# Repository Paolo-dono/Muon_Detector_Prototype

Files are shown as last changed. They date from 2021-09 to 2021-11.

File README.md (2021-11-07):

# Muon Detector Prototype
PCB design for the microcontroller subsystem of a muon detector.
- Creator: Paolo de Bruyn
- License: GNU General Public License v3.0

NOTE: Although the name of the project folder is STM32WL55JC_pcb_design, the STM32WL55JC is not the microcontroller that is used in the design. It was used during the initial design, but it has been replaced by the STM32F051R8. The reason why it was not renamed was because all the external component libraries that were added use the absolute filepath, and it would be a mission to change all of them.

## Component availability
All of the components are available from JLCPCB except for a few exceptions.

The GPS module needs an external antenna in order to function properly. Any antenna that has an IPEX MHF connector can be used. One recommendation is the KYOCERA AVX GPS Antenna 1004138 which is available from RS Components.

The banana connectors are sadly not available from JLCPCB but can be procured from DigiKey. It is recommended that the CT3151SP-0 connector is ordered for the ground connector as it is black, and the CT3151-6 is a blue connector which can be used for the supply voltage.

## Using the project
Simply clone the project and open it in KiCAD. The PCB should be in a state where it can already be printed by JLCPCB, but if not, probably only minor changes will have to be made.

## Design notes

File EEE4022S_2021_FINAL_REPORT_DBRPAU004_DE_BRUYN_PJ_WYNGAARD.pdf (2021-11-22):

# Muon Detector Prototype

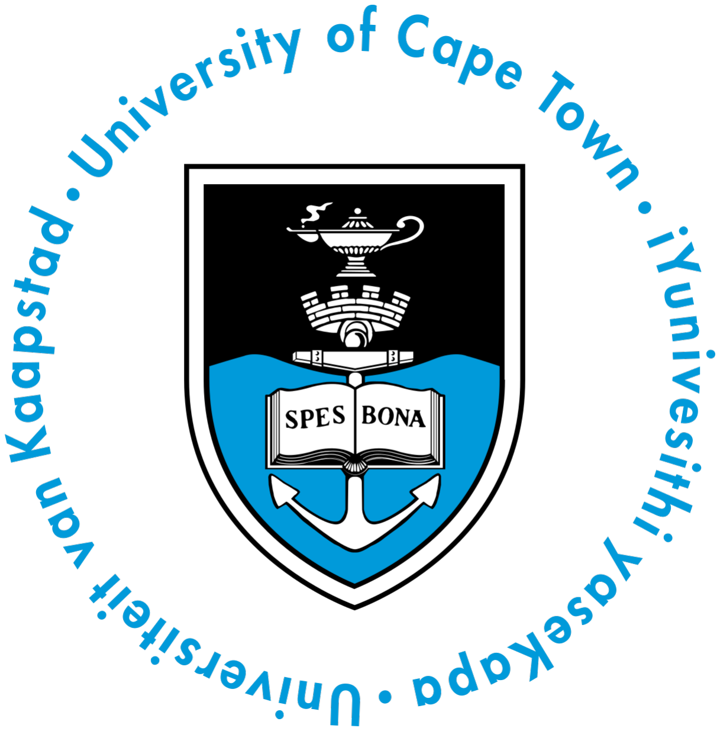
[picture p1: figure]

Presented by:
Paulus Jacobus de Bruyn

Prepared for:
Dr. Jane Wyngaard
Department of Electrical and Electronics Engineering University of Cape Town

Submitted to the Department of Electrical Engineering at the University of Cape Town in partial fulfilment of the academic requirements for a Bachelor of Science degree in Electrical and Computer Engineering

### 7 November 2021

## Declaration

1. I know that plagiarism is wrong. Plagiarism is to use another’s work and pretend that it is one’s own.
2. I have used the IEEE convention for citation and referencing. Each contribution to, and quotation in, this report from the work(s) of other people has been attributed,

and has been cited and referenced.

3. This report is my own work.
4. I have not allowed, and will not allow, anyone to copy my work with the intention of passing it off as their own work or part thereof.
Signature: |
P.J. de Bruyn
Date: | 7 November 2021

## Abstract

Muon radiography has been used since the 1950s to create scans of large and complex objects such as mountains, volcanoes, and pyramids. In this project, a system that can detect muons will be created in order to muon-image Devil’s Peak. A previous final year engineering student built a muon detector subsystem. The purpose of this project is to create the microcontroller subsystem to which the muon detector subsystem can connect that can send out data about the muon detection to a distant computer using LoRa. The data that will be sent is the following: longitude and latitude coordinates; accelerometer data; temperature and humidity; and voltage levels over time measured by the peak detector.

i

# Contents

1 Introduction | 1
2 Literature Review | 4

ii

3 Methodology | 15

iii

4 Design | 24
5 Implementation | 37

iv

6 Results | 65

v

7 Conclusion | 67
8 Recommendations | 68
A Additional files and schematics | 72
B Addenda | 77

vi

# List of Figures

3.1 Flow chart of the methodology | | 16
3.2 Layout of scintillator planes [24] | | 17
3.3 Layout of the muon detector subsystem [24] | | 18

4.1 Diagram of the daughter board and its interface with the microcontroller
subsystem | | 25
4.2 Pulse shaping circuit output [24] | | 27
4.3 Microcontroller subsystem design | | 29
4.4 Attempted STM32WL55JC routing | | 32
4.5 FSM of the control program | | 35
5.1 Power supply of the PCB | | 38
5.2 Peripherals on the PCB | | 39
5.3 IO expanders on the PCB | | 40
5.4 Schematic of the LoRa module | | 42
5.5 Connections of the microcontroller | | 44
5.6 NRST and BOOT connections | | 45

vii

5.7 ST-Link header | | 46
5.8 Oscillators for the microcontroller | | 46
5.9 JST GH header footprint | | 48
5.10 3D view of the JST GH header | | 48
5.11 19-pin 2.54 mm pitch male header appearance on the PCB | | 49
5.12 8-pin 2.54 mm pitch male header appearance on the PCB | | 50
5.13 Microcontroller routing on the PCB | | 51
5.14 LoRa routing on the PCB | | 52
5.15 Power supply routing on the PCB | | 53
5.16 Accelerometer and temperature sensor routing on the PCB | | 54
5.17 IO expanders routing on the PCB | | 55
5.18 3.3V supply across the PCB | | 56
5.19 Acid trap formed by copper tracks | | 57
5.20 An initial design with poor track spacing | | 58
5.21 Timing diagram of the daughter board | | 59
5.22 Final timing diagram | | 64
A.1 Front side of the PCB | | 73
A.2 Back side of the PCB | | 74
A.3 Front side of the PCB without copper fill | | 75
A.4 3D view of the PCB | | 76

viii

# List of Tables

3.1 Functional requirements of the system | | 21
3.2 Non-functional requirements of the system | | 22
5.1 Address selection of the IO expanders | | 40
5.2 10-pin JST GH header pin description | | 48
5.3 9-pin JST GH header pin description | | 49
5.4 3-pin JST GH header pin description | | 49
5.5 19-pin 2.54 mm pitch male header pin description | | 50
5.6 8-pin 2.54 mm pitch male header pin description | | 51

ix

# Nomenclature

BGA Ball Grid Array

EMC Electromagnetic Capability

FSM Finite State Machine

PCB Printed Ciruit Board

RTC Real Time Clock

SiPM Silicon Photomultiplier

SPI Serial Peripheral Interface

SWD Serial Wire Debug

x

# Chapter 1

# Introduction

## 1.1 Background to the study

Muons are elementary particles that are part of the lepton group and were discovered by American physicists Carl David Anderson and Seth Neddermeyer in 1936 [1]. It was later

found that muons provide a good way to image the internal structure of large objects such as mountains. This is because of a property muons have where they change direction and lose a certain amount of energy after they penetrated an object. This information can be used to find the size and type of material the muon travelled through. Muons are a good method for imaging because they occur naturally in the environment and do not have to be produced by an external source like other imaging techniques such as using x-rays or gamma rays. Muon radiography is also a much safer way of imaging that does not have the potential to expose humans to stray radiation as with other methods [2]. Additionally, the foremost reason muons are efficient for imaging is because of their deep penetrative power. Muons can travel through thick layers of rock, concrete, and iron which usually block other particles that are used for detection such as x-rays, gamma rays, neutrons, alpha particles, and beta particles [3].

## 1.2 Objectives of the study

### 1.2.1 Problems to be investigated

The main problem that will be investigated is how to design a PCB with a microcontroller that can communicate with the muon detector subsystem, GPS module, accelerometer, and temperature and humidity sensor, and transmit information from those devices via LoRa to a remote computer. This information will then be used for muon imaging.

### 1.2.2 Purpose of the study

This study will produce a way to detect muons and measure their direction of motion. This will allow one to muon image large objects such as Devil’s Peak, which is the case in this study. This way, geological research can be done on Devil’s Peak such as finding hidden tunnels and caves.

## 1.3 Scope and limitations

This study will only include the following: the design of the PCB of the microcontroller subsystem; the coding of the microcontroller to interface with the muon detector, GPS module, accelerometer, and temperature and humidity sensor; and then finally the sending of the data from those sensors via LoRa. The study will not include the design of the muon detector subsystem, or the actual muon-imaging of Devil’s Peak.

The biggest limitation to this study is time as it has to be completed within a period of three months. There is also a limited budget of R1500 for the project.

## 1.4 Plan of development

The study starts off with a literature review which will be an overview of the research and development that has been done in the field of muon detection, edge computing, IoT, and communication technologies. It will then continue to the methodology section which will explain what approach was used to satisfy the requirements of the project as well as exploring previous work done on the project. Thereafter, the schematic and PCB design of the microcontroller subsystem will be documented together with the design choices that were made to come to that design. Then, the results of the study will be reported. And finally, conclusions will be drawn and recommendations will be made for further study in this field.

# Chapter 2

# Literature Review

## 2.1 Muons

### 2.1.1 Introduction to muons

A muon is an elementary particle which, similar to an electron, has a negative charge and is part of the lepton group, but is approximately 207 times heavier than an electron. It was discovered by the American physicists Carl David Anderson and Seth Neddermeyer in 1936. A muon is fairly unstable, and has a lifetime of just 2.2 microseconds. Although their lifetime is short, muons travel at speeds close to the speed of light and can penetrate thousands of metres into the Earth [1].

Muons detected on Earth come into being due to primary cosmic rays. These are produced from a variety of sources in outer space such as solar flares, or novas. The primary cosmic rays travel through space and some collide with Earth’s atmosphere. Then, they generate a shower of secondary cosmic rays of which muons are one type [4].

### 2.1.2 Muon radiography

A valuable property that muons have is that they scatter after penetrating objects. The degree at which their angles change depend on the object. For dense objects with a high number of protons, such as uranium and plutonium, the change in angle is more prominent. Data can be collected on the degree of scattering of muons throughout the body of the object to create scans of the interior of the object. This field is known as muon radiography and has been implemented since the 1950s [5].

Due to their high momentum, muons can penetrate deeper into thick and dense objects than x-rays, and so they are the better choice when scanning thick samples [5]. Muon

radiography is also a safer option than x-rays which can produce stray radiation, unlike muons that are present naturally [2]. About 10 000 muons reach every square metre of

Earth per minute which is approximately one muon passing through an area the size of a human hand every second [5]. Thus, there is an ample supply of muons to create accurate

scans.

### 2.1.3 Operation of a muon detector

The main parts of a muon detector are a scintillator and a SiPM. A scintillator is a material that luminesces (produces photons) when it is hit by ionizing radiation (which includes muons). This is a property of the material scintillators are made of. Scintillators

can be made from a variety of different materials that can be solid, liquid, or gas and can be organic or inorganic. But in general, high density materials are usually chosen. In the case of inorganic crystal scintillators, the way they operate is when they are hit by ionizing radiation, it excites the electrons within the crystal which then move from the valence to the conduction band leaving holes behind in their place. These electron-hole pairs move around the structure until they reach and are trapped by a defect such as a dopant which are known as activators when it comes to scintillation. At these activator sites, the electrons decay and emit photons which causes luminescence [6].

Although the property of scintillators to luminesce is interesting from a physics perspective, to turn it into something useful an electrical signal is required so that processing and analysis of the luminescence can be made. This is where SiPMs come in. SiPMs are devices that convert light into electrical pulses. They are highly sensitive such that even a single photon can trigger them. The most vital component in a SiPM is the APD (Avalanche Photomultiplier Diode). This component streams an avalanche of electrons

when it is triggered by a photon. This avalanche of electrons only lasts for a very short time in the order of 1 nanosecond. This electrical pulse is then what can be passed to an electronics device for processing. One disadvantage of SiPMs is that they need a high voltage power supply. In some cases, an older variant of the SiPM is used which is the PMT (Photomultiplier Tube). However, SiPMs are becoming the more popular choice

because of their lower operating voltage, lack of susceptibility to magnetic fields, compact

size, and sturdiness [7].

### 2.1.4 Use cases

Decision Sciences

Decision Sciences is a company that has been given the exclusive licence of the Intellectual Property (IP) by U.S. Department of Energy’s Los Alamos National Laboratory (LANL)

to create a system they call Discovery. Discovery is a system that uses muon radiography as a non-intrusive and safe way to generate scans of cargo trucks. They have found that dense shielding such as metal plates around nuclear materials and contraband can pass many types of scanning techniques, like x-rays and gamma rays, completely undetected. However, this does not happen with muons as the dense shielding makes them scatter more which actually makes the materials easier to find. Many smugglers know that water can defeat x-ray systems and would place contraband in pallets of water. However, water still cannot pass by muon radiography undetected [3]. The system can learn the

configuration of different types of vehicles to ignore the known features such as the engine and transmission and focus on any unusual materials that might be hidden [2].

Pyramids

A major use for muon radiography is to scan the internal structure of pyramids. This is often used for the purpose of finding hidden rooms inside the pyramids. Luis Alvarez used muon radiography to search for hidden chambers in the Pyramid of Chephren in Giza. Alvarez and his team started recording data in early 1968 on magnetic tape and through the course of their research they were unable to find any hidden chambers in the 19% of the pyramid that they scanned. Although they were unable to find anything, their research did demonstrate the potential that muon radiography holds [8].

In December 2015, a physicist called Kunihiro Morishima and his team placed muon detectors in the Queen’s chamber of the Great Pyramid of Giza. After a few months, the researchers came upon something promising. To validate their findings, two other teams of physicists placed muon detectors of different types at different locations inside and outside the pyramid. All three teams agreed that their results showed a cavity above the Grand Gallery. The space was found to have a similar cross section as the Grand Gallery and at least 30 metres long. This was the largest discovery of a new space inside the pyramid since the 19th century [9].

Volcanoes

Muon radiography has also been used to scan magma chambers in order to estimate when the volcanoes will erupt. Hiroyuki K. M. Tanaka from the University of Tokyo and his colleagues investigated the density distribution of magma in Mount Iwodake. A 1m² detector was placed at the foot of the volcano to obtain an image of the conduit on

the inside. This information can be used to predict the development of eruptions and determine which areas close to the volcano are in danger [5].

Cosmic Pi

Cosmic Pi is a low-cost cosmic ray detector kit. The kit contains scintillators and SiPM modules as well as a PCB with an amplifier for the detection of muons. The PCB also contains a GPS module, temperature and humidity sensor, and accelerometer. The kit also contains a Raspberry Pi Zero WH which helps with wireless communication and some processing. The idea is for many of these kits to be assembled and used by people all over the world so that the data gathered by these devices can be collected in order to create a global telescope [10].

## 2.2 The Internet of Things (IoT)

### 2.2.1 Introduction

IoT is the growing trend whereby more and more devices are being connected to the internet. Through the development of IoT, devices that initially had very limited functionality have become more useful and responsive not only through their ability to connect to the internet, but more specifically because of their ability to collaborate with other devices. This makes the environment smarter as more internet-capable devices are integrated with it. These devices collect a vast amount of data about the environment which then leads to a challenge with IoT which is how to store and process such large quantities of data that are related to each other. The challenge is made harder by the fact that the data can be produced by many different types of devices running on different platforms that are connected from a variety of remote locations. This is where cloud computing arises to offer a solution [11].

Cloud computing allows a way for IoT devices to connect to each other through central servers that are very powerful and reliable. Cloud computing also offers analytics tools and various ways to visualize data. In addition, it also allows one to access applications from anywhere that has an internet connection [11]. There are some issues with the use

of cloud computing when it comes to IoT which are explained further in Section 2.3.

Through the large collection of data about an environment (such as a home environment or work environment like construction), it helps one produce a common operating picture (COP) [11] of the environment. In addition, through this collection of data, a new realm

of possibilities are opened in the field of data analytics, and it allows one to understand, optimize, and control the environment better.

Another important factor of IoT is that it should be able to operate without the interference of humans or, put differently, it should ”disappear from the consciousness of the user”[11]. To achieve this, IoT devices need to: be able to communicate relevant con-

textual information; have a shared comprehension of the environment and context; and have strong analytics tools. This will allow IoT devices to act autonomously [11].

In order to fully utilize the available Internet technology, large-scale wireless sensor networks that are platform independent must be deployed and include the collection, management, storage, and analysis of data [11].

### 2.2.2 History of IoT

The term ‘Internet of Things’ was first introduced by Kevin Ashton in a presentation he made at a Proctor and Gamble (P&G) conference in 1999. The presentation specifically addressed the use of RFID in supply chain management [12]. But since then, the term has

expanded to include a whole variety of applications and smart devices that can operate autonomously.

### 2.2.3 The use of IoT

Radio Frequency Identification (RFID)

RFID is the use of small electronic chips for wireless data communication. They assist with the identification of the object they are attached to. One major benefit is that they are passive elements and not battery powered, which saves a lot of energy. They use the power of the RFID reader’s probing signal to communicate their ID. The major usage of RFID tags is currently with bank cards to allow for quick transactions. Another major usage is in the monitoring of cargo by attaching RFID tags to port containers [11].

Lighting

The control of lighting is one of the classic examples of the use of IoT because it can take place fully without the need for human intervention. Light sensors that are positioned outside a building can communicate the light intensity to the lights that are inside the building which would then adjust their brightness accordingly. This can save much energy and ensures that lights are not too bright or left on unnecessarily. This is often done using Bluetooth mesh nodes that are attached to all the sensors and lights.

Automotive

Predictive maintenance technology can be used in one’s car to have a better understanding about the internal state of the car. Data that is collected by many sensors in your car can be sent for analysis on the cloud to notify the driver of any potential problems that might present themselves in the future. This allows the user to take action to avoid potential incidents [13].

## 2.3 Edge computing

### 2.3.1 Introduction to edge computing

Edge computing is a distributed computing paradigm that brings computing closer to the edge where it is needed. The edge can be defined as any computing resources that are at a distance from cloud data centers and closer to data sources. In the last couple of years, the amount of data produced at the edge has grown significantly with the great expansion of IoT and the increase of data producers. As an example, a Boeing 727 can produce 5 GB of data every second, and an autonomous car can produce 1 GB of data every second. This has put much pressure on networks and cloud data centers and they cannot keep up with the big volume of data being produced. This is why edge computing is needed because it lightens the load on cloud data centers and decreases network traffic [14].

### 2.3.2 History of edge computing

The idea behind edge computing started in the late 1990s when Akamai launched content delivery networks (CDNs) to increase the speed of web services. CDNs use nodes closer

to the user devices to prefetch and cache content so that it can be delivered to users faster. CDNs are especially useful when it comes to video streaming because there is no more reliance on one central server to do all the work. The potential for edge computing truly became evident in 1997 when Brian Noble and his coworkers implemented speech recognition on mobile devices by having the resource intensive work delegated to a nearby server and then the results would be only have to be sent to the mobile device.

### 2.3.3 Benefits of edge computing

Edge computing increases responsiveness because it decreases the distance data exchanges have to travel. Data does not have to traverse various networks to get to the cloud for processing and so latency is decreased [15]. As a test for edge computing, researchers

built a platform to run a facial recognition application, and found that the response time improved from 900 to 169 ms when using edge computing instead of a cloud based solution [14]. According to Ha et al. [16], using cloudlets to do the processing for wearable

cognitive assistants improved the response times between 80 and 200 ms. In addition, the energy consumed was lowered by 30% to 40% [16].

A great example of the potential of edge computing was given by Shi et al. [14], which is

in the case of video analytics. If a child goes missing, the video data from street cameras can be used to help locate the child. However, to send all of that large video data to a central server to be analyzed would be a very slow task which would not be suitable for such an urgent matter. But if edge computing is utilized, the central server can signal the devices at the edge to search through their local data. Then, an edge device only needs to report back the result to the cloud server. This is very beneficial because not only is the overhead of transferring large amounts of video data eliminated, the search for the child is done in parallel by all the devices which massively reduces the time to retrieve a result [14].

Privacy and security is a major issue of concern with the increasing prevalence of IoT. IoT devices can collect a vast amount of private data that should not be available to unauthorized third parties. And so, sending data to the cloud for processing could be a problem because it exposes the data to potential threats such as unauthorised parties intercepting the data. For this reason, it is more secure to process the data where it is collected - at the edge [14].

### 2.3.4 Challenges of edge computing

One challenge experienced with edge computing is that of programmability. With cloud computing, programs are usually written in one language and compiled for a specific platform. In this way, there is more control over where and how a program is run. But because edge computing platforms are more diverse, it becomes more difficult to create a program that will function properly everywhere it is used [14].

And next is the issue of data abstraction. It should be avoided to send raw data from IoT devices to applications that run on the gateway. Firstly, because of security, and secondly, because the extra load of data could overwhelm the gateway. However, one then has the issue of usability of the data because information describing the data is removed which could make it more difficult for the gateway application to make sense of the data and use it. The reliability of the data can also be a problem because firstly the sensing of the data might not be completely accurate and the wireless communication medium might be unreliable. And so, a major challenge for edge computing and IoT is how to extract useful data from an unreliable source. [14].

According to Shi et al. [14], there are four essential issues when it comes to service

management for edge computing which are summarized as follows:

- Differentiation: some services are more important than others and so there needs

to be some form of prioritization.

- Extensibility: the network should be able to grow and easily accept new nodes to

connect to it.

- Isolation: several applications should have access to a resource so that if one appli-

cation fails, the resource should still be accessible. In this way, if one application fails, it does not affect the rest of the system.

- Reliability: if a service is not working properly, it is a challenge to find what ex-

actly the problem is. A way to overcome this problem would be if the service could provide a message of what component failed.
The reliability of a service is mostly centred around data collection and communication. When the communcation medium is not reliable, one way to overcome this is to use predictions from historical and reference data, but this is still an ongoing challenge.

## 2.4 Communication technologies

### 2.4.1 Introduction

In order for IoT devices to interact with each other, they need to be able to communicate. This can be either with short range communication technologies such as Bluetooth, Zigbee, LoWPAN, RFID, Zwave, and NFC as well as long range technologies such as cellular networks (such as 3G and 4G), Sigfox, and LoRa. All of these technologies utilize radio

waves instead of dealing with the complications of physical wiring such as not being easily extendable. These technologies can be based locally on a more private network with a smaller range, or they can make use of the cloud for interconnection and take advantage of cloud services [17]. The following subsections will take a look at the different long

range communication standards.

### 2.4.2 Cellular networks

Cellular communication, especially through the evolution of 4G and 5G, allows for communication at very high speeds. 4G has a theoretical maximum of 300 Mbps while typical values are around 40 Mbps. And 5G has theoretical speeds of 10 Gbps and potentially even more, but currently speeds of around 200 Mbps are experienced [18]. Cellular net-

works also have a very wide range with LTE being able to reach 100 km. The main disadvantage of cellular networks, however, is that they are relatively power hungry and might not be suitable for small low-powered devices that should be able to run on a battery for a number of weeks [17].

### 2.4.3 Sigfox

Sigfox is a narrowband technology that uses binary phase-shift keying (BPSK) for radio

transmission. The narrowband technology allows a receiver to only listen for incoming signals on a smaller spectrum of frequencies which reduces the effects of noise [19]. Sigfox

uses a very low data rate of 100 to 600 bps but has a range of approximately 40 km in rural areas and 10 km in urban areas.

Sigfox was found in 2010 by Ludovic Le Moan and Christophe Fourtet with the intention to improve the world of IoT and allow devices to connect to each other in a more efficient way. Sigfox places great emphasis on providing a service that can extend a long range to reach low-powered devices that need to transfer small packets of data. All the complex computations for Sigfox are performed on the cloud instead of the low-power devices for additional energy savings. Another advantage is that Sigfox is capable of operating very efficiently and has reduced signalling and protocol overhead [20].

One usage of Sigfox is in the monitoring of the fill levels of dumpsters. In this way, dumpsters do not have to be manually checked, and the refuse collection provider does not have to be manually sent a request for a pickup. Instead, these processes happen automatically by having a sensor send a signal to the pickup collection provider, using Sigfox, that the dumpster is full and ready for a pickup. In addition, a temperature sensor and fire alarm can be added to the system for extra safety [20].

### 2.4.4 LoRa

LoRa (Long Range) is a technology provided by Semtech. It is used to transmit data of low data rates (0.3 to 27 kbps) [17] over a long range and can transmit 5 km in urban

areas and 20 km in open space. LoRa uses the sub-GHz bands of the ISM radio band spectrum and the specific band it uses depends on the geographical location. A major advantage of LoRa is that it is very low-power, making it suitable for IoT applications [21].

It is important to make a distinction between LoRa and LoRaWAN. LoRa is the modulation technique to get a high receiver sensitivity and reduce bit errors. LoRa also refers to the systems and chips that support this type of modulation [22]. However, LoRaWAN is quite different. It is a MAC layer protocol that is built on top of LoRa. LoRaWAN also includes encryption and identification functionality at the gateway level. Additionally, LoRaWAN has a cloud component which the gateways connect to [23].

# Chapter 3

# Methodology

The approach used for this project was mostly similar to that of the waterfall methodology with some touches of the agile methodology. The work took a mostly linear approach with problem definition, design, and implementation, but there were numerous times where the design would have to change or new components had to be added to the design and then the project had to adapt to those changes in an agile manner.

The project had a team of five members. The undergrad student doing this project, a master’s student, Alan Pohl, who previously worked on this project for his final undergraduate project, the supervisor for the project, Jane Wyngaard, and a team from the physics department consisting of two members. The physics team was made up of a student, Daniel Weiss, doing his honours project on muon imaging and his supervisor, James Keaveney. The team would meet weekly for updates on everyone’s progress together with direction from the supervisors. Much collaboration was done with Pohl as he pursued the design and implementation of the muon detector subsystem further as his master’s project which had to interface with the microcontroller subsystem of this project. The physics team acted as a sort of client for this project as the eventual goal was to provide them with the muon detector to be used in their research.

Below is a diagram showing the sequence of steps in the project, followed by a more detailed description of each step.

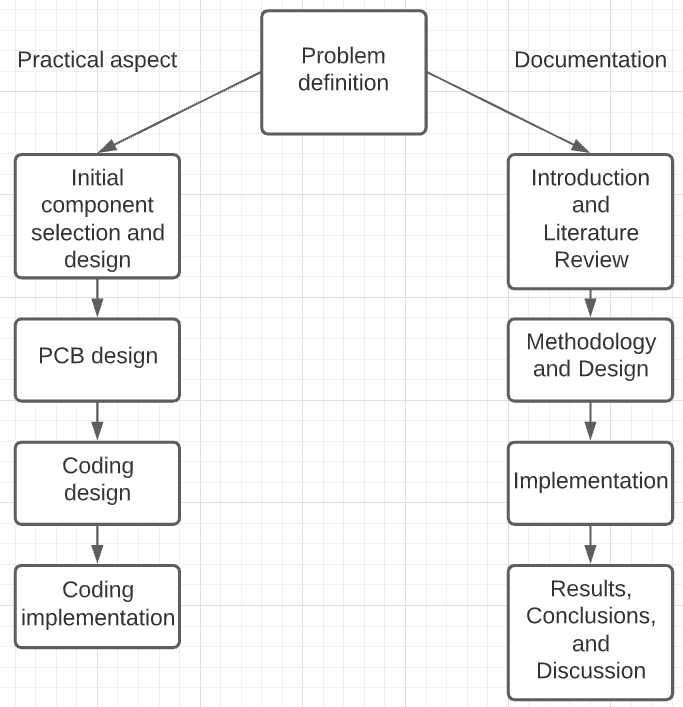
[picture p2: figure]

Figure 3.1: Flow chart of the methodology

## 3.1 Problem definition

This was the initial step to start off the project. Through introductory meetings with the team, the goals and requirements of the project were established. The work that was done by Pohl during his undergraduate project was investigated as a starting point for the project.

### 3.1.1 Previous work done on the project

Pohl designed the muon detector subsystem in his undergraduate final project which includes scintillator planes, SiPMs, comparators, pulse shaping circuits, ADCs, and encoders.

The scintillator planes had the following layout:

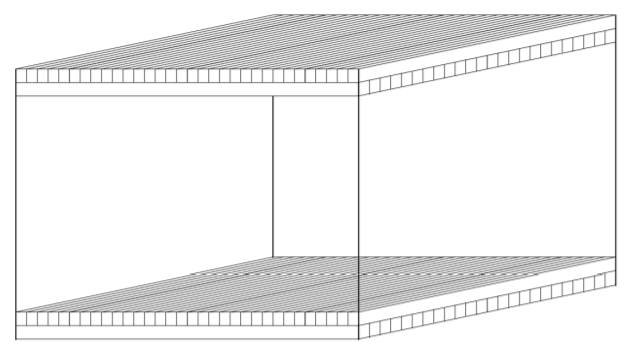
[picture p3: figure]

Figure 3.2: Layout of scintillator planes [24]

The scintillator has two sets of planes - one at the top and one at the bottom with a space between the two sets. Each set has one plane of vertical scintillator blocks and one plane of horizontal scintillator blocks. This was done to create a grid so that when a muon passes through the plane, the exact x- and y-coordinates of where the muon hit the plane can be found. The reason for having two sets of planes with a distance between them is so that one can determine the trajectory of the muon. When a muon hits the scintillator, the coordinates of the top plane and the bottom plane can be compared to find the trajectory. For the trajectory to be found with good accuracy, there must be enough scintillator blocks to create a grid that is sufficiently fine. By weighing the costs and the accuracy required, it was decided to use 32 scintillator blocks for each of the 4 planes.

The overall design of each plane in the scintillator subsystem is as follows:

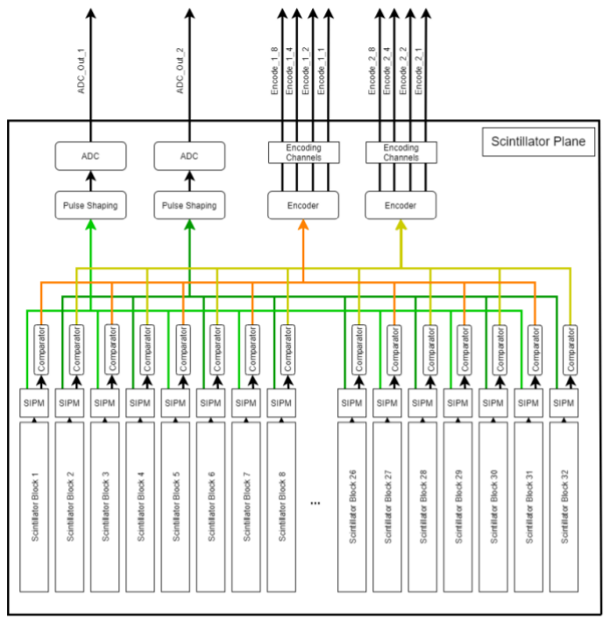
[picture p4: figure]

Figure 3.3: Layout of the muon detector subsystem [24]

When a muon hits the plane, the scintillator that was hit absorbs the muon’s energy and converts it into photons. These photons then travel to the SiPM (silicon photomultiplier)

which produces an electrical pulse. Thereafter, two things happen with the pulse.

Firstly, the pulse is sent to an ADC so that the pulse can be read. However, because the pulse is so short, it first has to pass through a pulse shaping circuit to extend it so that it can be picked up by the ADC. Then, the digital output from the ADC is sent to the microcontroller subsystem.

Secondly, in order to find which scintillator block was hit, a logic signal must be passed to the microcontroller from the specific scintillator block. In order to generate a logic high signal, the pulse from the SiPM is passed through a comparator. And because there are 32 scintillator blocks which would require many pins on a microcontroller, an encoder is used to reduce the number of pins required from 16 to only 4 pins for each of the two sets of scintillator blocks which brings it to a total of 8 encoder pins.

Another important design choice to mention is the separation of the scintillator blocks into two sets of 16 and the use of two ADCs and encoders instead of one of each. There is a problem that a muon might come at the scintillator plane at such an angle that it activates two scintillator blocks that are next to each other. But a muon will never be able to activate more than two scintillator blocks. For this reason, every second scintillator block is connected to its own ADC and encoder so that no information is lost.

### 3.1.2 Requirements for this project

The aim of this project was to continue from where Pohl left off and implement the microcontroller subsystem for the project. This subsystem had two major elements -a hardware part and a software part. The hardware element consisted of the selection of all the hardware modules and components and the placement and routing of those components on a PCB. The software element consisted of the program that would run on the microcontroller, that was on the PCB, which would utilize the hardware components selected in order to perform the major functions needed for the project.

The subsystem needed the following hardware components:

- GPS module: this is used to find the location of the device. During muon detection,

several scintillator planes are usually used. It is then necessary to know where each of these planes are in relation to each other in order to determine how to piece together their outputs to produce a muon image.

- Accelerometer: this component is often used to determine the amount of accelera-

tion of a device, but in this case it is used to determine the angle of inclination of the plane which helps with determining the trajectory of a muon.

- Temperature and humidity sensor: temperature and humidity can have an effect

on the muons and their detection, and so this is useful information to be sent to the physics department for analysis.

- Headers for interfacing with the muon detector subsystem: the muon detector sub-

system needed to get its power from the microcontroller subsystem. In addition, the microcontroller subsystem needed to interface with the ADCs and encoders from the muon detector subsystem.

- LoRa module: this module enables LoRa communication which is necessary to

transmit the information gathered from the muon detector subsystem and the sensors on the microcontroller subsystem.

In addition, collaboration had to be done with Pohl to decide which ADCs to use on the daughter board of the muon detector subsystem to sample the output of the pulse shaping circuits. This is because the ADCs fell in the middle ground between the muon detector subsystem and the microcontroller subsystem. The ADCs needed to be fast enough to capture the pulse produced by the pulse shaping, but at the same time have the right specifications that it could work with the chosen microcontroller.

Functional requirements

Functional
requirement
number

Description

FR001 | The system must include a functioning PCB that can be pro-
| grammed and can communicate with its peripherals.
FR002 | The PCB must contain a microcontroller that can store and run a moderately sized program and have enough I²C, SPI,
| and UART interfaces to support all the peripherals that need
| to connect to it.
FR003 | The PCB must be able to interface with the muon detector
| subsystem.
FR004 | The system must be able to find its GPS coordinates.
FR005 | The system must be able to determine its angle of inclination.
FR006 | The system must be able to determine the surrounding tem-
| perature and humidity.
FR007 | The system must be able to send the information it gathered
| via LoRa.
FR008 | The microcontroller must be fast enough to extract the values
| from the ADCs, GPS module, accelerometer, and tempera-
| ture and humidity sensor, and work out where exactly on the
| scintillator planes the muon made contact, and then commu-
| nicate this information via LoRa all in under one second. This
| is because approximately one muon will hit scintillator every
| second.
FR009 | An ADC must be selected for the daughter board of the muon
| detector subsystem which must be fast enough to sample at
| least 10 values of the output of the pulse shaping circuit.

Table 3.1: Functional requirements of the system

Non-function requirements

Non-functional
requirement
number

Description

NF001 | Standard components that are available from JLCPCB must
| be selected.
NF002 | On the PCB, there should be a minimum track spacing of 0.2
| mm.
NF003 | The minimum via to pad and via to track spacing should be
| 0.2 mm.
NF004 | Vias with a drill hole size of no less than 0.2 mm with a diam-
| eter of at least 0.4 mm must be used.
NF005 | Blind and buried vias must not be used.

Table 3.2: Non-functional requirements of the system

## 3.2 Practical aspect

### 3.2.1 Initial component selection and design

In this stage, the major components for the microcontroller subsystem were selected such as the microcontroller, of course, and the accelerometer, temperature and humidity sensor, GPS module, and LoRa module. It had to be confirmed that all components that were selected were available from JLCPCB in order to be manufactured. If a critical component was needed that was not available from JLCPCB, other plans were made such as ordering from RS Components or DigiKey so that the component could be soldered onto the PCB manually. In addition, in this stage diagrams of the design of the microcontroller subsystem were drawn up using online tools such as diagrams.net, and the interfaces between the muon detector subsystem and microcontroller subsystem were determined. This process is explained in detail in Chapter 4.

### 3.2.2 PCB design

In this section, the schematic of the PCB for the microcontroller subsystem was created using KiCAD. After the schematic was completed, the PCB layout and routing was done so that it could be manufactured by JLCPCB. All specifications laid out by JLCPCB were followed to make sure they could produce the PCB without any issues. This section is demonstrated in Chapter 5.

### 3.2.3 Coding design

This is where the planning for the programming of the microcontroller took place. Diagrams such an FSM (Finite State Machine) were drawn to plan out the flow of the

logic of the main program that would be running on the microcontroller. This section is demonstrated in Chapter 4.

### 3.2.4 Coding implementation

During this stage, the actual coding of the microcontroller was to be done and tested. The software that was planned to be used was the STM32CubeIDE. The various communication protocols for the components used in the microcontroller subsystem had to be investigated as part of the coding design. UART was used for the GPS module, SPI for the ADCs and IO expanders, and I²C for the accelerometer and temperature and

humidity sensor.

## 3.3 Report

The report was written in parallel with the development of the project. The introduction in the report gave a basis for the project by detailing the history and background to the project as well as its aims. Then the literature review was where all the research had been gathered that was needed to implement the project. The methodology provided the structure for how the project was developed and implemented. The design section was where all the design decisions were made such as component selection and schematic design. This section also included diagrams that show the operation of the system and its programs. Thereafter, the implementation section was where the PCB layout was produced. Finally, the results of the investigation were reported, and conclusions of the project were drawn.

# Chapter 4

# Design

## 4.1 PCB Design

### 4.1.1 Daughter board

The muon detector subsystem designed by Pohl has two main parts: the scintillator planes and the daughter boards. The scintillator planes contain the 32 scintillator blocks which are used to detect muons. The scintillator planes then connect to the daughter boards which contain the electronics of the muon detector subsystem. After the completion of Pohl’s design, the interface of the daughter boards to the main PCB, which is the microcontroller subsystem, was determined. Below is the simplified design of a daughter board which was used to determine the interface with the microcontroller subsystem:

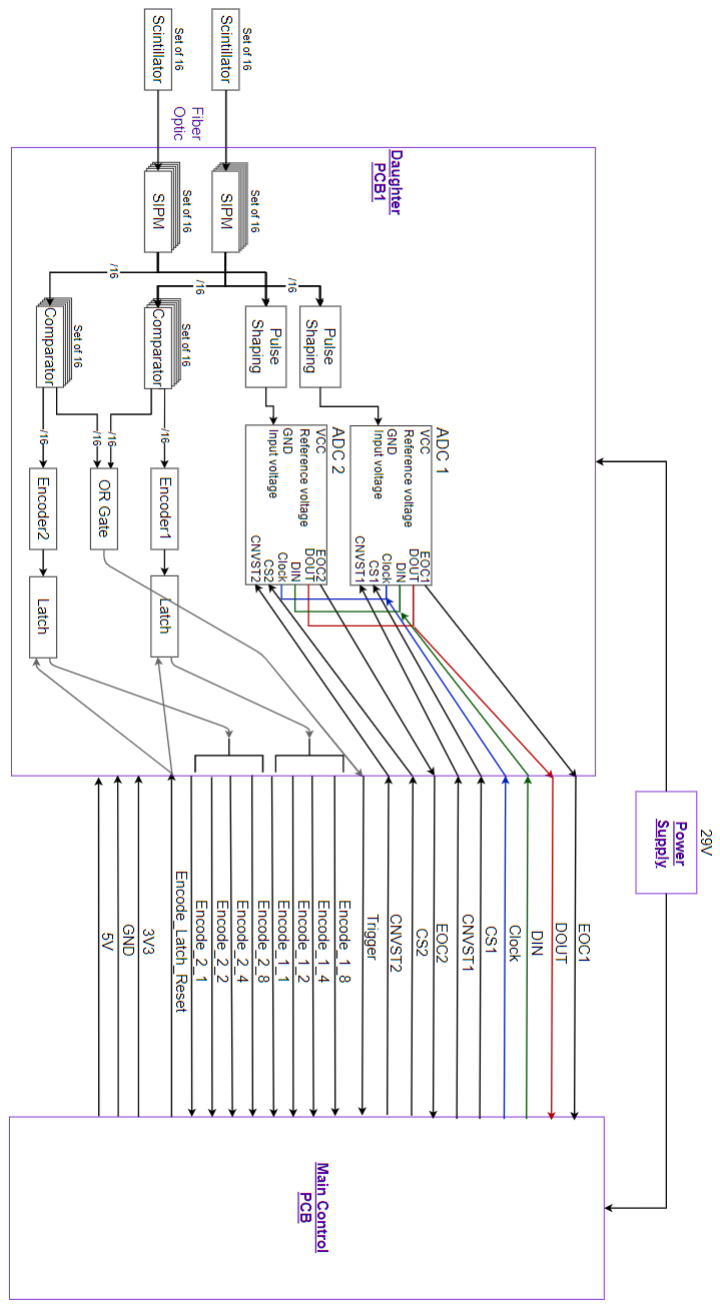
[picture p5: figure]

Figure 4.1: Diagram of the daughter board and its interface with the microcontroller subsystem

Each of the four scintillator planes will have one daughter board which will have the same design as the one above. Two major changes were made to the design of the daughter board from the initial design in Chapter 3.

Firstly, the outputs of the comparators of were connected to an OR gate. Each plane has its own OR gate. The OR gate will function as a trigger to the microcontroller as it indicates that an event on the scintillator has occurred, i.e. that a muon hit the scintillator. The alternative to using OR gates to check for an event would be to check every encoder pin to see if any of them went high. The problem with this is that it takes much longer to read the 32 encoder lines than checking the 4 OR gates.

The other change was that the output of the encoders were connected to a latch so that the their outputs are remembered. This is necessary because after the microcontroller is triggered by the OR gate, it takes a while for the microcontroller to gather all the data from the daughter board. The comparators, and therefore the encoders, only stay at a high output for a few microseconds. Thus, in order not to lose the output of the encoders, they must be stored by latches. Because of this, an additional reset line is required to clear the values of the latches after they have been read by the microcontroller.

The daughter board is powered by 5V, 3V3, and GND lines. The 5V supply is required to power the ADCs, while the standard 3V3 is required to power the rest of the electronics and logic lines.

The ADCs have several useful pins beyond the clock, MISO, MOSI, and NSS pins that are necessary for SPI communication. There is a conversion start (CNVST) pin that allows you to enable or disable the ADC. This functionality will be explained further in the ADC selection section. Then, there is also an end of conversion (EOC) pin which can signal the micro that a new sample has finished being converted by the ADC.

ADC selection

One of the vital requirements for the ADC was to ensure that it is fast enough to capture at least 10 samples of the output of the pulse shaping circuit. Below is shown two graphs: the output of the SiPM is on top which is also the input to the pulse shaping ciruit, and then the output of the pulse shaping circuit is shown at the bottom.

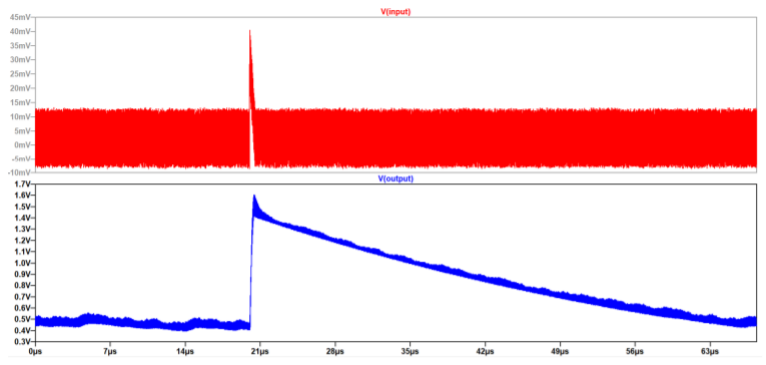
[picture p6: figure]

Figure 4.2: Pulse shaping circuit output [24]

It can be seen from the above figure how the very short output from the SiPM is significantly extended. On the output of the pulse shaping circuit, the pulse starts at approximately 20 µs and ends at approximately 66 µs. Thus, the pulse has a duration of approximately 46 µs. As 10 samples must be taken from this pulse, the ADC needs to be able to take a new sample at least every 4.6 µs. Then, the required sampling rate of the ADC can be calculated as follows:

Sampling rate = | 1 sampling period

=

1
4.6µs

= 217391 Hz

Therefore, when looking at standard ADC values, an ADC that has a sampling rate of at least 220 kHz was required.

The other major requirement was that the ADC should include a FIFO to store the most recent values it converted. There are a number of reasons why this was required. Firstly, because the required sampling rate is quite fast and the microcontroller would have to read from 8 ADCs that are producing new data at 220 kHz, which would mean that a fast microcontroller would have to be chosen and timing would be very critical to make sure no values are missed. Secondly, all 8 ADCs needed to be connected to the same SPI interface because of the limited number of SPI interfaces on the available microcontrollers, which means that the ADCs would have to take turns to send their data which makes it take even longer to read all the data from the ADCs. This challenge can be demonstrated with a calculation. A standard 12-bit ADC would need to send 16 bits over SPI (SPI sends one byte at a time), and taking into account the start and stop bits

that are sent to control communication, a total of 18 bits will need to be sent to send one sample from an ADC to the microcontroller. Taking a standard SPI speed of 18 MHz (which is the speed allowed by the chosen microcontroller [25]), we get the following:

Time to send 18 bits = | Size of data Frequency in Hz
= | 18 bits 18 MHz

= 1 µs

Because 8 ADCs need to be read from in the worst case, it will require 8 µs to read one sample from each ADC which violates the requirement of 4.6 µs. Therefore, a FIFO is absolutely required and needs to be big enough to store at least 10 values.

With these requirements in mind, the MAX11635EEE+T was found. It has a sampling rate of 300 kHz which satisfies the requirement of at least 220 kHz. In addition, it has a FIFO that can store up to 16 samples, making the MAX11635EEE+T the perfect choice for the daughter board.

The ADC will be operated as follows: when the scintillator plane is hit by a muon, the microcontroller will wait for about 50 µs to allow the entire pulse to be produced by the pulse shaper and converted by the ADC. After this point, the ADC is disabled by using the CNVST pin. This will prevent the ADC from adding in more values into the FIFO which will push out the desired pulse shaper output values before they can be captured by the microcontroller. Then, after the values have been read by the microcontroller, the ADC will be enabled once again so that it can be ready to convert values from the pulse shaper at any time.

### 4.1.2 Main PCB

The design for the microcontroller subsystem is shown below:

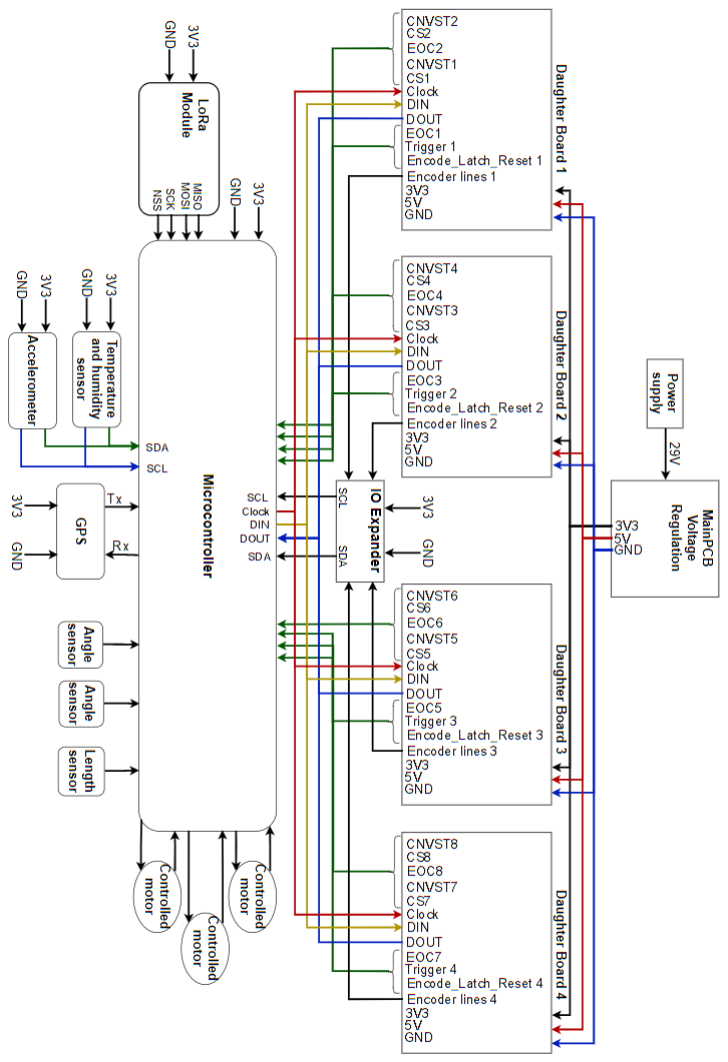
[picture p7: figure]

Figure 4.3: Microcontroller subsystem design

Some simplifications were made for a less messy demonstration of the subsystem. The 8 encoder lines of each daughter board were joined together as one line. In addition, some of the connections of the peripherals such as the accelerometer and LoRa module were omitted. However, the connections that are of most interest such as the supply connections and communication interfaces are shown.

This subsystem design satisfies the hardware requirements laid out in the methodology by including a GPS module, accelerometer, temperature and humidity sensor, and LoRa module. The subsystem includes the correct interface to the muon detector subsystem. In addition, the subsystem also attempts to use components that are available from JLCPCB as far as possible.

It can be seen in the diagram that angle sensors, a length sensor, and controlled motors are included in the diagram. These components were not developed in this project, but will be included in a future project. One motor will allow one to change the ‘top-down’ angle of the scintillator, while another motor will allow one to change the ‘left-right’ angle of the scintillator. The angle sensors will measure the extent of these two angles. The final motor will control the distance between the two planes. The distance between the planes changes the angle of acceptance that the scintillator allows. When the planes are close together, a wider angle of muons are accepted. This is because a muon can come at the scintillator nearly parallel to the plane, but still manage to travel through all 4 planes because they are close together. But when the planes are further apart, a more focused angle of muons are accepted. The length sensor would measure this distance between the planes.

The following sections detail the components that were selected and reasons for the choice.

Microcontroller: STM32F051R8T6

One of the major reasons for this choice was because it is a mainstream microcontroller with much community support. Its core is an ARM 32-bit Cortex-M0 CPU with a frequency of up to 48 MHz, making this microcontroller sufficiently powerful for this project. It has a flash size of 64 kB, making it unlikely to run out of memory for a mediumsized program. It also has the perfect amount of communication interfaces needed of two SPI (ADCs and LoRa module), two I²C (accelerometer and temperature sensor connected

to one interface and the IO Expander to the other), and two USART interfaces (of which only one will be used for the GPS module). Another major reason for this choice for a

microcontroller, was because it is a 64-pin package with many GPIO connections which are necessary to interface with the muon detector subsystem which requires many pins [25].

However, for the greater part of the project another microcontroller was chosen and worked with before the selection of the STM32F051R8T6, which is the STM32WL55JC. This was because of its large flash size, extensive 73-pin package, and the fact that it has two processing cores (ARM Cortex M4 and M0+). But the major reason it was chosen

was because LoRa is integrated with it. This meant that no additional external LoRa module would be required and it removes the risk of communication problems between the microcontroller and the LoRa module [26].

The reason the STM32WL55JC was not chosen even though it seemed to be the perfect selection for the project was because of the type of pins. It had BGA (Ball Grid Array) pins with a pitch of 0.5 mm [26]. This means that the pins are very densely packed, and

routing between the pins is impossible. The only way to route this type of microcontroller is through placing blind and buried vias under the microcontroller pins (called via-in-pad).

Firstly, the use of these vias is not ideal because of the high manufacturing complexity which makes them very expensive and time consuming to make. Secondly, because the BGA pins are so small, vias with a very small diameter would be required which violate JLCPCBs minimum specifications. The vias needed a drill hole size of 0.17 mm and a diameter of 0.34 mm which is lower than JLCPCB’s minimum specifications of a 0.2 mm drill and a 0.4 mm diameter. It is likely that microvias would be required in order to get these small sizes which is also a problem because microvias are more specialized and expensive than normal vias [27]. Thirdly, because these vias are of the via-in-pad type,

they need to be capped and filled with epoxy. This is because of the small size of the BGA pins. The pins are so small that they can only take a little bit of solder. If the via used under the pad is an open hole, the via might wick all the solder away from the pad which creates a weak or broken connection between the pad and microcontroller pin [28].

In addition, when it came to routing the microcontroller this was the result:

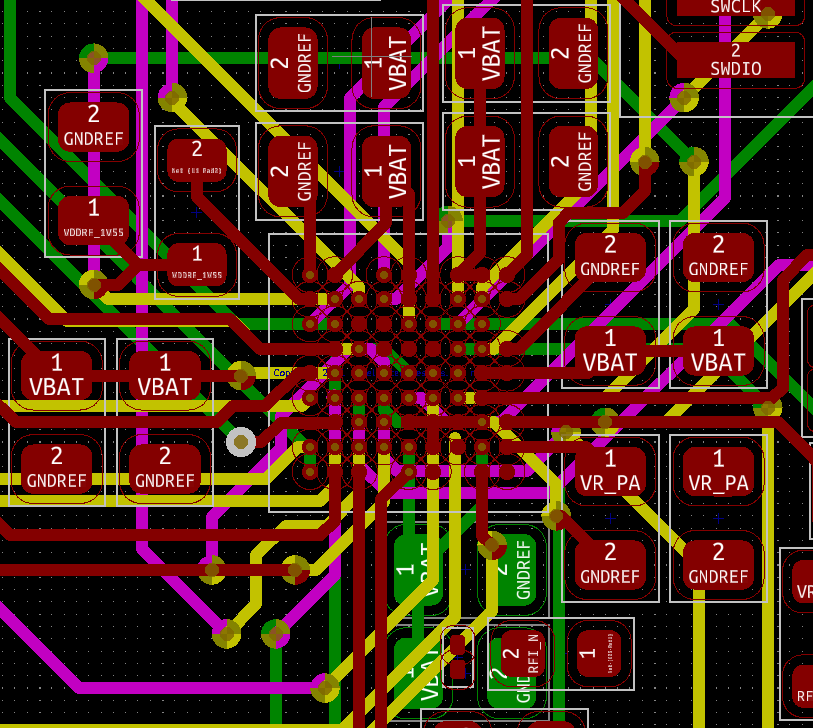
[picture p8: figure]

Figure 4.4: Attempted STM32WL55JC routing

Even through the use of 4 signal layers, the routing was highly difficult and there were still a number of unconnected pins which were stuck on the inside. It was likely that the design would have needed to be changed to 6 signal layers to complete the routing. And so, because of the high complexity, high costs, and greater potential of making a mistake and getting a faulty PCB, it was decided to change the design and use another microcontroller which turned out to be the STM32F051R8T6.

GPS module: ATGM336H-5N31

The ATGM336H-5N31 is one of the most popular GPS modules at JLCPCB which makes it a trustworthy choice. This GPS module uses the standard NMEA0183 protocol which is the standard with GPS modules making it easy to work with. This module requires an external antenna, and so the KYOCERA AVX GPS Patch Antenna 1004138 will be used. This antenna is not available from JLCPCB and would have to be procured from RS Components [29].

Accelerometer: LIS3DHTR

This component was mainly selected for its availability, and the fact that it is an STMicroelectronics product which makes it more reliable. It also includes a 32 level FIFO for each of the X, Y, and Z output channels which can be quite useful [30].

Temperature and humidity sensor: SHT30-DIS

This component was chosen firstly because it includes a temperature sensor and a humidity sensor in one package instead of needing two separate components. It also has a compact size which aids with the layout and routing of the PCB. In addition, it was also chosen because of its high reliability, accuracy, and high signal to noise ratio [31].

LoRa module: SX1276IMLTRT

This component was mainly selected for its availability at JLCPCB, and the fact that there are libraries readily available for it. Another benefit is that it has a wider frequency range than some of the other models in the same line such as the SX1278 and SX1279. Its frequency range stretches from 137 - 1020 MHz whereas the SX1278 and SX1279 only range from 137 - 525 MHz and 137 - 960 MHz respectively [32].

IO expanders: PCF8575, PCF8574

Because of the 36 pins needed for the encoders from the daughter board (8 pins each for 4 planes plus 4 pins to reset the latches that hold onto the data of the encoders), it adds

extra complexity for the routing of the PCB and requires a microcontroller with a very high number of GPIO pins which are not always readily available. For this reason, it was chosen to add IO expanders to the design to which the encoder lines can connect. Then, only two I²C pins (SDA and SCL) are needed from the microcontroller to communicate

with all 36 encoder pins. This also has the added benefit of making the design more modular. And so, two PCF8575 modules and one PCF8574 module were chosen. The reason the PCF8575 was chosen was because it was the biggest IO expander JLCPCB had available with 16 IO pins. The PCF8575 is also one of the most popular IO expanders which makes it more reliable. Because the PCF8575 only has 16 pins, two of them were put in the design which brought the number of IO pins to 32. But because an additional 4 pins were needed, the smaller version of the PCF8575 was chosen which is the PCF8574 with 8 IO pins [33][34].

## 4.2 Coding design

An FSM of the control program that will be running on the microcontroller is shown below:

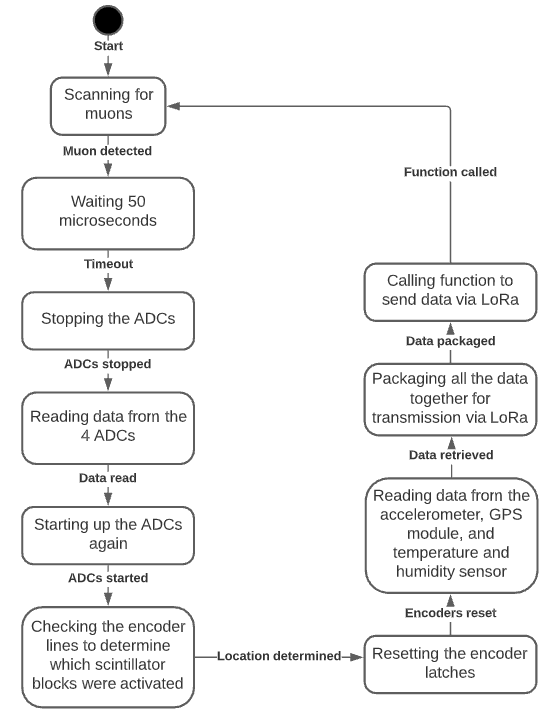
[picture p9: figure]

Figure 4.5: FSM of the control program

The program starts off in a loop where it continuously checks the OR gates from the daughter board to see if any of them are high which indicates that a muon hit the scintillator. When an event is detected, the microcontroller has to wait for approximately 50 µs. This will give enough time for the pulse shaping circuits to extend the pulse, as well as giving the ADCs the opportunity to convert the 10 samples from the pulse. After those 50 µs when the ADCs have finished the conversions, they need to be deactivated so that they do not push more values into the FIFO which might cause the desired pulse shaping output values to be lost. All the data stored in the FIFOs of the ADCs will then be read and stored, and thereafter the ADCs will be started again so that they are ready to sample new pulses as soon as they arrive. Then, the encoder lines will be checked to determine which scintillator blocks were activated in order to find where exactly the muon hit the scintillator. This will allow the microcontroller to calculate the trajectory of the muon, and together with the GPS coordinates, the exact geographical coordinates of where the muon hit the scintillator can be calculated. Thereafter, the angle of inclination of the scintillator plane will be determined using the accelerometer, the GPS coordinates will be read from the GPS module, and the temperature and humidity will be read from the temperature and humidity sensor. All of this data that was read from the peripherals and calculated (the trajectory and exact position of the muon) will be transferred to a remote computer using LoRa. And finally, the program returns to the loop where it continues checking for new events from the muon detector subsystem.

# Chapter 5

# Implementation

## 5.1 Schematic

The following sections follow the schematic of the PCB for the microcontroller subsystem and the major decisions that were made about the connections between the components. Any calculations used to work out component values will also be covered.

### 5.1.1 Power supply

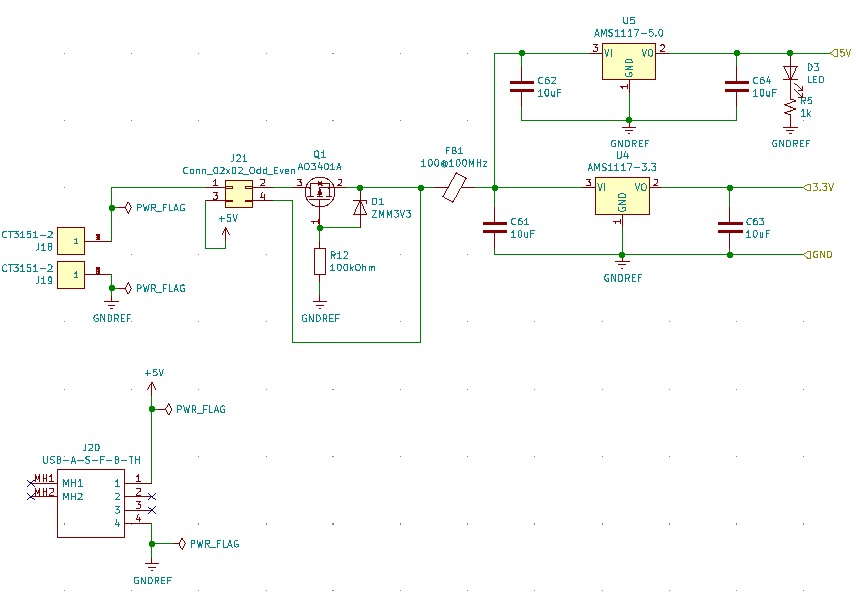
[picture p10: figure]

Figure 5.1: Power supply of the PCB

There are two ways to power the PCB - through banana connectors or through USB. The USB connection is convenient for programming the microcontroller outside an electronics lab as it can simply be powered by a laptop. The banana connectors are what will be used when the project will be deployed in the field. A 29V input will then power the system. The USB connector is a standard female USB-A connector that is available from JLCPCB. However, the CT3151-2 connectors are only available from DigiKey and no equivalent connectors were found from JLCPCB, and so these will have to be ordered separately from DigiKey and manually soldered.

To select between the banana connector power supply and USB power, a header is used. The appropriate pins can just be connected for the desired power supply.

The power supply circuit also includes reverse polarity protection on the banana connectors using a p-channel enhancement type MOSFET in case the input jacks are swapped by mistake. Using a MOSFET solution instead of using a simple diode is more energy efficient because the MOSFET does not have a significant voltage drop like a diode does [35]. Because USB-A inherently enforces polarity protection by only allowing the USB

connector to connect with a specific orientation, the reverse polarity protection circuit is not necessary and can be chosen to be bypassed if USB power is used.

Next, a ferrite bead is included to remove unwanted high frequencies from the circuit. Then, the components that follow thereafter are the voltage regulators. The AMS1117-5.0 and the AMS1117-3.3 are used to regulate the voltage supply to 5V and 3.3V respectively. They were selected because of their popularity and because of their use in PCBs that were examined as reference during the development of the schematic.

The final component included in the power supply circuit is an LED to indicate that the power has been connected successfully. It is connected in series with a resistor to prevent it from burning out.

### 5.1.2 Peripherals

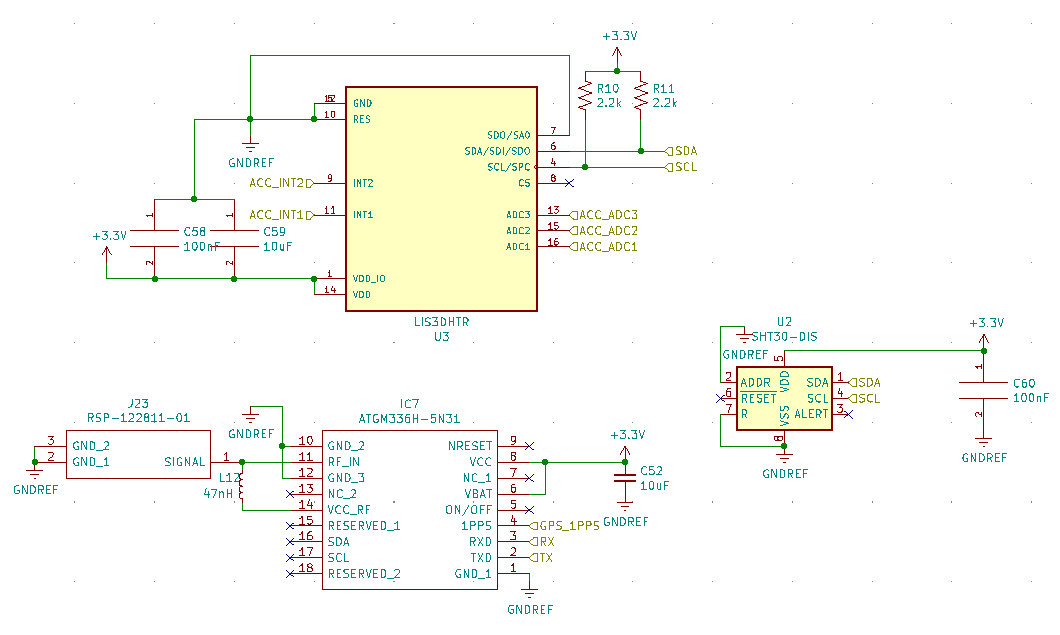
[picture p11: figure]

Figure 5.2: Peripherals on the PCB

The three peripherals on the PCB - accelerometer (LIS3DHTR), GPS module (ATGM336H-5N31), and temperature and humidity sensor (SHT30-DIS) - will be discussed in this

section. The peripherals mostly have their connections similar to that which is recommended in their respective data sheets with the correct voltage and ground connections as well as the appropriate decoupling capacitors. Any unused pins of interest such as the three input pins of the auxiliary ADC of the accelerometer as well as its two interrupt pins and the 1PPS pin from the GPS module are all connected to a header so that they can be accessed externally when needed.

The accelerometer and temperature and humidity sensor share the same I²C interface because of the limited I²C interfaces on the microcontroller. The GPS module has its

own separate UART interface to the microcontroller.

The GPS module requires an external antenna and therefore the KYOCERA AVX GPS Antenna was chosen. This antenna uses an IPEX MHF connector which the GPS module is connected to using pins 11 and 14 as shown in Figure 5.2.

### 5.1.3 IO expanders

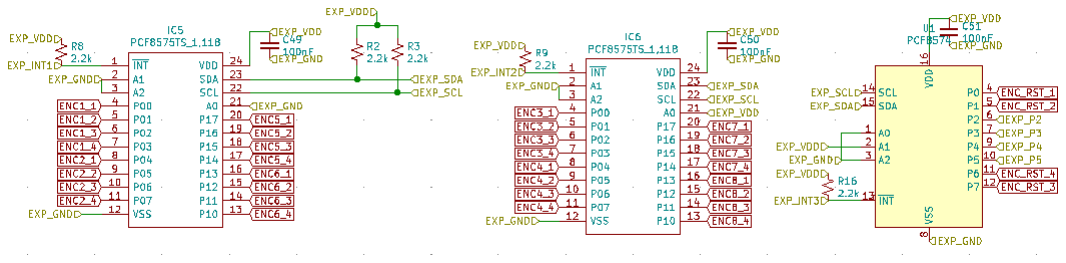
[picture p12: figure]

Figure 5.3: IO expanders on the PCB

Because of the shortage of pins on the microcontroller, IO expanders (PCF8575 and PCF8574) were chosen to interface with the 36 pins from the encoder section from the

daughter board. The IO expanders have a useful feature of allowing one to change the address of the devices when multiple devices are used on the same I²C interface, which

is the case in this design. This is done through hardware by setting the A0, A1, and A2 pins of the IO expanders high or low. The addresses for these devices have a leading 0100 and so the address for a particular device is 0100[A2][A1][A0]. The values that were

selected for the devices, which corresponds to the IO expanders in Figure 5.3 from left to right, are shown below:

Device | A2 | A1 | A0 | Address
PCF8575 (1) | 0 | 0 | 0 | 0100000
PCF8575 (2) | 0 | 0 | 1 | 0100001
PCF8574 | 0 | 1 | 0 | 0100010

Table 5.1: Address selection of the IO expanders

It can be seen that these values correspond with the connections in Figure 5.3. A2, A1, and A0 are pins 3, 2, and 21 respectively on the PCF8575 IO expanders, but pins 3, 2, and 1 respectively on the PCF8574 IO expander.

### 5.1.4 LoRa module

Figure 5.4: Schematic of the LoRa module

The above figure shows the LoRa module (SX1276) and how its pins are connected as well

as the impedance matching circuits and filters that connect the module to the antennas. This schematic was drawn up with the aid of reference designs from Semtech which is the manufacturer of LoRa modules. The SX1276RF1JAS reference design was looked at specifically [36]. The configuration registers of the LoRa module are controlled using

SPI, while the transmitted and received data as well as various states and clocks of the module are communicated using the digital IO (DIO) pins.

The LoRa module has three power amplifiers. By using the RFO LP and RFO HP, up to +14dBm can be delivered. But the third power amplifier, PA BOOST, can deliver up to +20dBm. However, in the reference design the RFO HP pin is unused, and so the RFO LP and RFI LP are used as the low-power transceiver pair, while the PA BOOST and RFI HP are used as the high-power transceiver pair. To switch the module to the transmitting state, the LoRa TX EN pin on the microcontroller must be set high while the LoRa RX EN pin must be set low. This is the opposite for when the module is in the receiving state where the LoRa RX EN pin is set high and the LoRa TX EN pin is set low.

### 5.1.5 Microcontroller

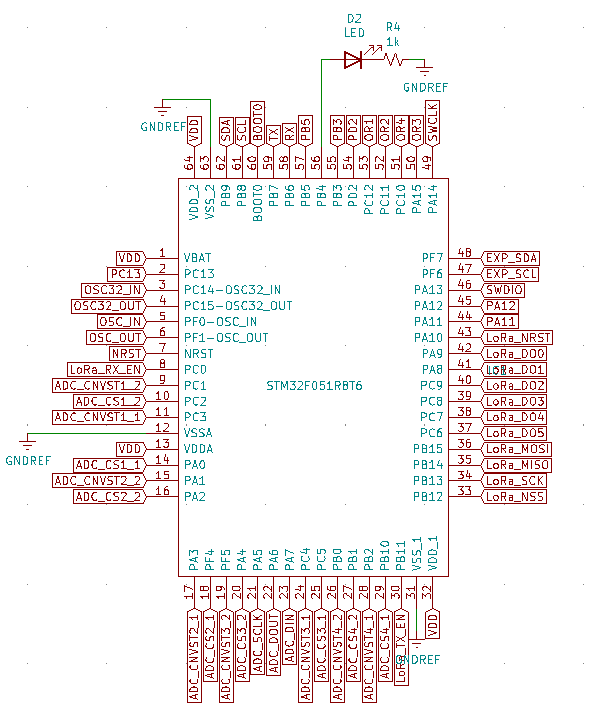
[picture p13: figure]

Figure 5.5: Connections of the microcontroller

The figure above shows how all of the pins of the microcontroller are connected with the aid of the STM32F051 datasheet [25]. This arrangement of pins was selected to optimize

the routing of the PCB. The connections for the peripherals, such as the accelerometer and temperature and humidity sensor which use I²C and the GPS module which uses UART, are at the top of the microcontroller. The I²C connections for the IO expanders

together with the OR gates from the daughter board are at the top right. The majority of the LoRa connections are on the right side. The ADC connections are mostly at the bottom of the microcontroller and some are on the left. And then finally, the other major connections on the left are for the 32 MHz (OSC) and 32.768 kHz (OSC32) oscillators.

During the process of assigning these pins, the pins for the power connections were done first, followed by the connections for the communication interfaces. The remaining pins were assigned to the more basic connections such as the OR gates which are simple logic level inputs. An LED was added for testing to check if the GPIO works as expected.

### 5.1.6 NRST and BOOT

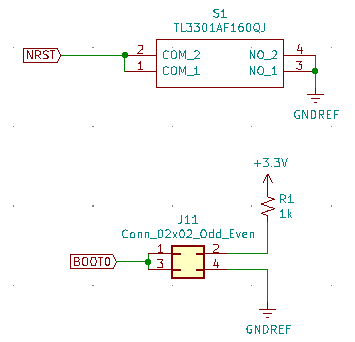
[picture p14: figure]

Figure 5.6: NRST and BOOT connections

The NRST (not reset) pin must be pulled low to signal a reset to the microcontroller. As can be seen in the above figure, the NRST pin is connected to a tactile push button which will connect the NRST to GND when pressed.

The BOOT0 controls the source from which the microcontroller boots. If the BOOT0 pin is set low (connecting pin 4 to either pin 1 or 3), then the user flash memory is selected as the boot space. If the BOOT0 pin is set high (connecting pin 2 to either pin 1 or 3), then the microcontroller activates the bootloader in system memory [37].

### 5.1.7 ST-Link

Figure 5.7: ST-Link header

To program the microcontroller through SWD, the ST-Link/V2 is used. A 2x10 ribbon

cable is used to connect the ST-Link to the 2.54 mm pitch male header shown above. The SWDIO, SWCLK, and NRST pins connect to the microcontroller and are the major pins for programming the microcontroller.

### 5.1.8 Oscillators

Figure 5.8: Oscillators for the microcontroller

The 32 MHz crystal (NX2016SA) is the main external oscillator, while the 32.768 kHz crystal (SC-20S) is the oscillator for the internal RTC. The following equation is used to determine the values of the external capacitors [38]:

CL =

C1 × C2
C1 + C2
+ CS | (5.1)

CL is the load capacitance specified by the manufacturer, and C1 and C2 are the external capacitors that are connected to the sides of the oscillator. CS is the stray capacitance in the PCB which can range between 2 pF and 8 pF [38].

To calculate the values of the capacitors for the 32 MHz crystal, the load capacitance was needed from the NX2016SA datasheet which was found to be 8 pF. By using a stray capacitance of 3 pF, and using the same capacitor value for C1 and C2, then the value of the external capacitors can be calculated as follows:

CL =

C1 × C2
C1 + C2

+ CS

CL =

C1 × C1
C1 + C1

+ CS (C2 = C1)

CL =

C

2
1
2 × C1

+ CS

CL =

C1
2

+ CS

8 =

C1
2

+ 3

C1 = 10 pF

A similar process is followed to find the capacitance for the 32.768 kHz crystal. A load capacitance value of 12.5 pF was specified by the manufacturer. By using a value of 5 pF for the stray capacitance, and the derivation in the calculations above, the value of the external capacitors can be calculated as follows:

CL =

C1
2

+ CS

12.5 =

C1
2

+ 5

C1 = 15 pF

### 5.1.9 Interface with the daughter board

For the PCB of the microcontroller subsystem to interface with the daughter board, JST GH connectors were chosen. The footprint of a 9-pin JST GH header appears as follows:

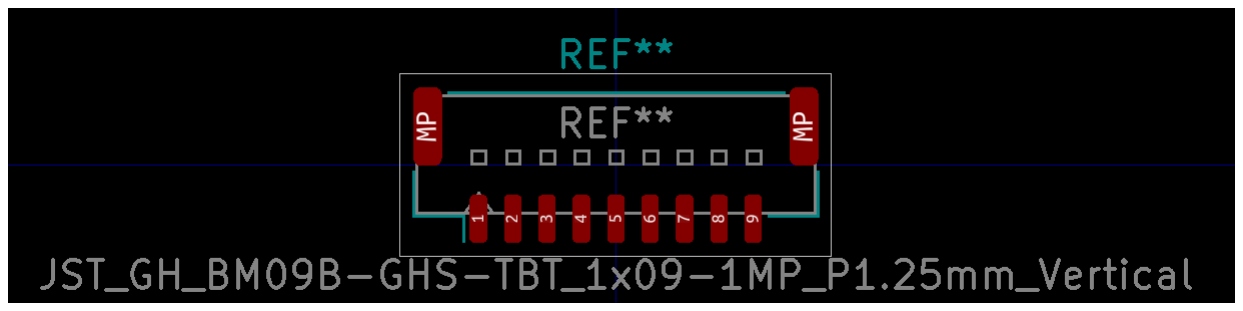
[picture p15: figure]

Figure 5.9: JST GH header footprint

A 9-pin JST GH header would appear as follows in an assembled PCB:

Figure 5.10: 3D view of the JST GH header

The pins are ordered from pin 1 to 9 from left to right in the figures above. The following tables describe the pins that are used for each JST GH header that is used to interface with the daughter board. Take note that there are four JST GH headers on the PCB for each header described because of the use of four daughter boards for the four scintillator planes in the muon detector subsystem.

10-pin JST GH header for the encoder section:

Pin# | Name | Function
1 | OR1 | Trigger that a muon was detected
2 | ENC RST1 | Resets the latch connected to the encoders
3 | ENC1 1 | Encoder set 1 bit 0
4 | ENC1 2 | Encoder set 1 bit 1
5 | ENC1 3 | Encoder set 1 bit 2
6 | ENC1 4 | Encoder set 1 bit 3
7 | ENC2 1 | Encoder set 2 bit 0
8 | ENC2 2 | Encoder set 2 bit 1
9 | ENC2 3 | Encoder set 2 bit 2
10 | ENC2 4 | Encoder set 2 bit 3

Table 5.2: 10-pin JST GH header pin description

9-pin JST GH header for the ADC section:

Pin# | Name | Function
1 | ADC CNVST1 2 | Active-low conversion start pin 2
2 | ADC CS1 2 | Chip select 2
3 | EOC1 2 | End of conversion output 2. Conversion ready when pulled low.
4 | ADC CNVST1 1 | Active-low conversion start pin 1
5 | ADC CS1 1 | Chip select 1
6 | ADC SCLK | Clock pin for SPI
7 | ADC DIN | MOSI pin for SPI
8 | ADC DOUT | MISO pin for SPI
9 | EOC1 1 | End of conversion output 1. Conversion ready when pulled low.

Table 5.3: 9-pin JST GH header pin description

3-pin JST GH header for the power supply:

Pin# | Name | Function
1 | GND | Ground connection
2 | 3.3V | Main power supply
3 | 5V | Power supply for ADCs

Table 5.4: 3-pin JST GH header pin description

### 5.1.10 Other pin headers

Any pins from the microcontroller or the peripherals that are unused but would still be helpful to be able to access are connected to headers. There are two headers that have this function. The first header is a 19-pin header with all the unused pins from the microcontroller, accelerometer, GPS module, and IO expanders are connected. The other header which is an 8-pin header is for the unused pins from the ADCs on the daughter board. The following tables describe the pins of these headers. The pins will be labelled on the silkscreen of the PCB.

19-pin 2.54 mm pitch male header:

Figure 5.11: 19-pin 2.54 mm pitch male header appearance on the PCB

Pin# | Silkscreen name | Name | Function
1 | PC13 | PC13 | GPIO pin PC13 on the microcontroller
2 | PA12 | PA12 | GPIO pin PA12 on the microcontroller
3 | PB5 | PB5 | GPIO pin PB5 on the microcontroller
4 | PB3 | PB3 | GPIO pin PB3 on the microcontroller
5 | PD2 | PD2 | GPIO pin PD2 on the microcontroller
6 | PA11 | PA11 | GPIO pin PA11 on the microcontroller
7 | A A1 | ACC ADC1 | ADC input 1 of the accelerometer
8 | A A2 | ACC ADC2 | ADC input 2 of the accelerometer
9 | A A3 | ACC ADC3 | ADC input 3 of the accelerometer
10 | A I1 | ACC INT1 | Interrupt pin 1 of the accelerometer
11 | A I2 | ACC INT2 | Interrupt pin 2 of the accelerometer
12 | 1PPS | GPS 1PPS | GPS pin which produces one pulse per second with a duration of 100 ms.
13 | E I3 | EXP INT3 | Interrupt pin of IO Expander 3 (PCF8574)
14 | E P5 | EXP P5 | IO pin P5 of IO Expander 3 (PCF8574)
15 | E P4 | EXP P4 | IO pin P4 of IO Expander 3 (PCF8574)
16 | E P3 | EXP P3 | IO pin P3 of IO Expander 3 (PCF8574)
17 | E P2 | EXP P2 | IO pin P2 of IO Expander 3 (PCF8574)
18 | E I2 | EXP INT2 | Interrupt pin of IO Expander 2 (PCF8575 (2))
19 | E I1 | EXP INT1 | Interrupt pin of IO Expander 1 (PCF8575 (1))

Table 5.5: 19-pin 2.54 mm pitch male header pin description

8-pin 2.54 mm pitch male header:

Figure 5.12: 8-pin 2.54 mm pitch male header appearance on the PCB

Due to lack of space, it was chosen to label the pins as ‘E1 1’ instead of using the form ‘EOC1 1’.

Pin# | Name | Function
1 | EOC4 1 | End of conversion pin for ADC 1 on daughter board 4
2 | EOC4 2 | End of conversion pin for ADC 2 on daughter board 4
3 | EOC3 1 | End of conversion pin for ADC 1 on daughter board 3
4 | EOC3 2 | End of conversion pin for ADC 2 on daughter board 3
5 | EOC2 1 | End of conversion pin for ADC 1 on daughter board 2
6 | EOC2 2 | End of conversion pin for ADC 2 on daughter board 2
7 | EOC1 1 | End of conversion pin for ADC 1 on daughter board 1
8 | EOC1 2 | End of conversion pin for ADC 2 on daughter board 1

Table 5.6: 8-pin 2.54 mm pitch male header pin description

## 5.2 PCB layout

The following sections examine the major parts of the PCB layout that are of interest. The thinking behind the placement and routing choices will be described. The full views of the PCB layers can be found in Appendix A.2.

### 5.2.1 Microcontroller

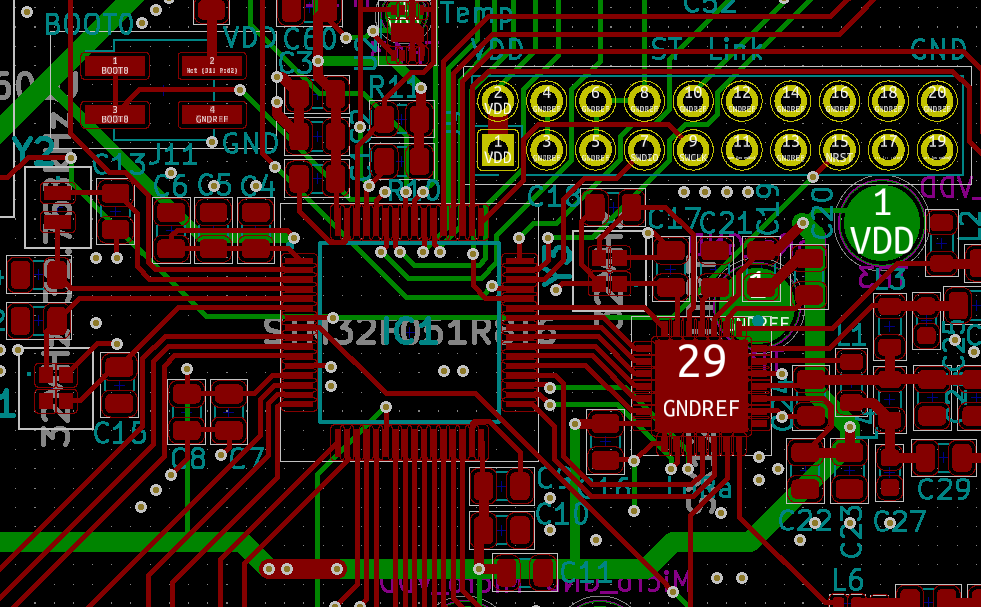
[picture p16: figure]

Figure 5.13: Microcontroller routing on the PCB

The microcontroller was the first component to be routed because of its vital role in the PCB. The decoupling capacitors were placed as close as possible to the microcontroller and from there, the rest of the components were placed around the microcontroller depending on where their connections were. For example, the accelerometer and temperature and humidity sensor were placed at the top of the microcontroller as explained in Section 5.1.5. Although it is not ideal for some of the copper tracks to be so close to each other, because of how close the pins of the microcontroller are to each other, there was no other choice.

The 2x10 2.54 mm pitch male header for the ST-Link ribbon cable can be seen at the top right in the image above. It was placed as close as possible to the microcontroller because of its great importance to have a usable PCB.

At the top left, the 2x2 header can be seen for the BOOT0 pin. The VDD and GND pins are labelled on the silkscreen so that the pins cannot be confused and that it is not necessary to rely too much on the documentation of the PCB.

### 5.2.2 LoRa

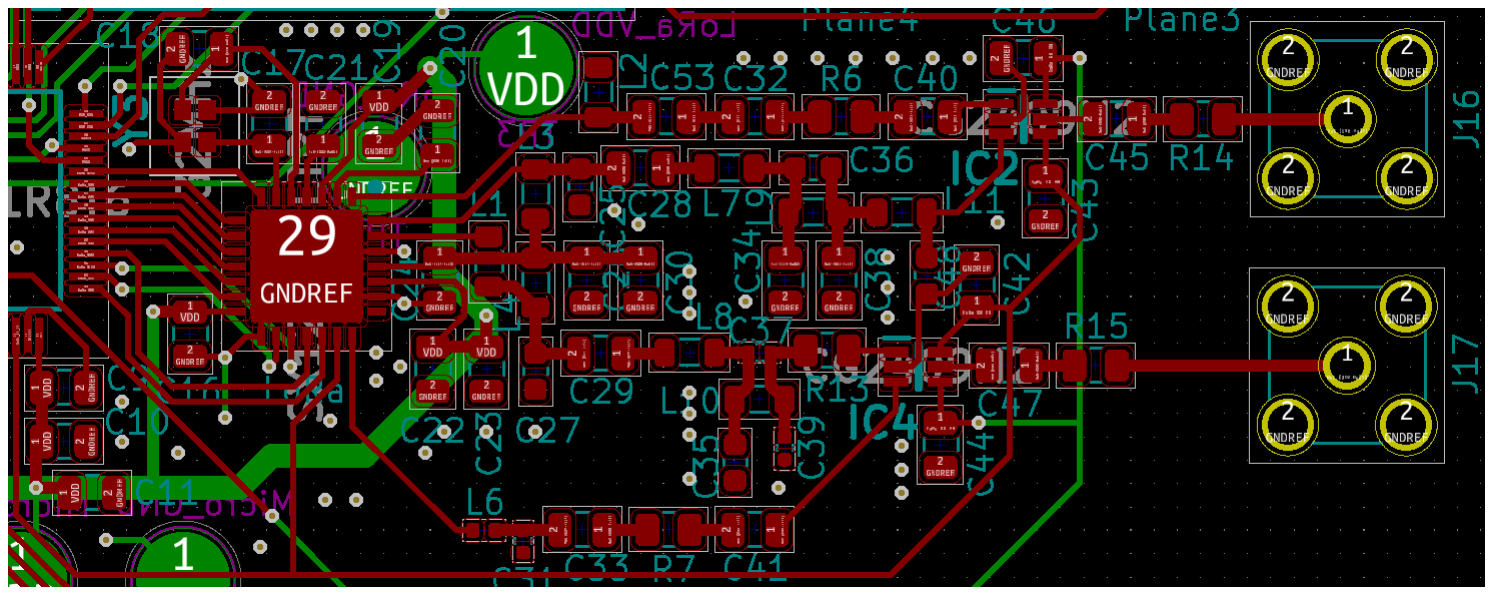
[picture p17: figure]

Figure 5.14: LoRa routing on the PCB

Much care had to be given to do the routing for the LoRa section. Using the AN5407 application note from STMicroelectronics, it was ensured that the copper tracks for the impedance matching circuits and filters were as straight as possible to reduce the possibility of reflections. In the places where there were bends, it would be ideal to have used rounded tracks with the same width instead. Unfortunately, these types of tracks were not available on KiCad, and external libraries did not end up working successfully.

As a compromise, the bends in the tracks were ensured to be no less than 135◦ as the tighter bends such as 90◦
, which is strongly advised against, have a much higher chance of leading to reflections [39].

It can also be seen in the above image that there are many vias placed around the circuit. This is because of another recommendation by the application note that the plane on which the impedance matching circuits and filters are must have a strong ground connection. It is recommended that when using two layers, as is the case for this PCB, each layer must have a large grounded copper fill with many vias connecting the two layers. This reduces ground impedance and EMC issues. This process is called ground flooding [39].

### 5.2.3 Power supply

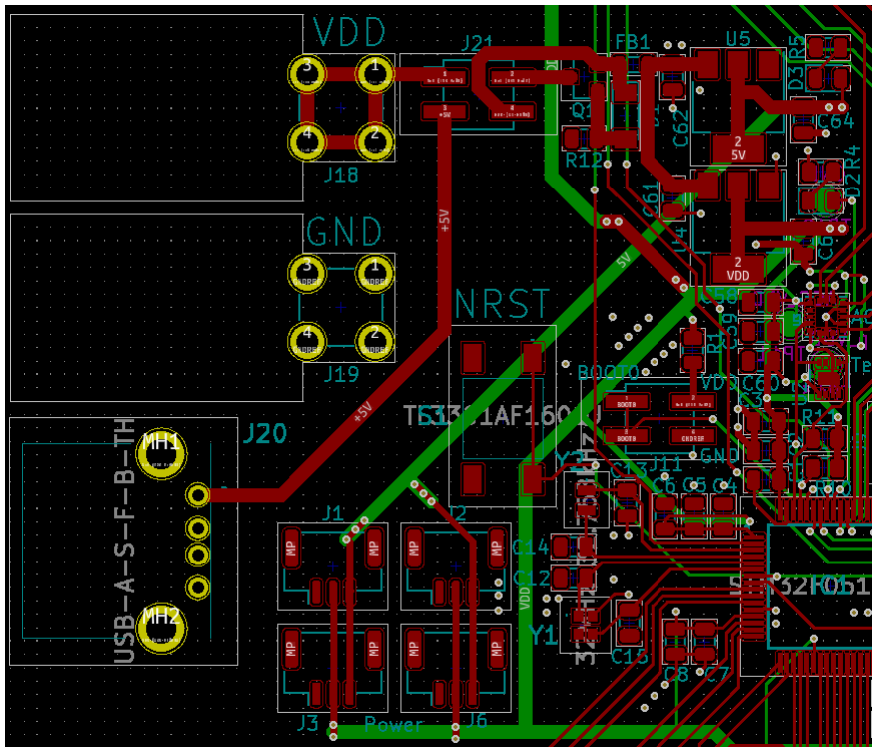
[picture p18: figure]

Figure 5.15: Power supply routing on the PCB

The power connections were all placed at the top right of the PCB. The banana connectors can be seen at the very top left with the USB-A connector below them. All the tracks for the power supply were made 1 mm thick which is much thicker than the standard 0.25 mm tracks. This was done for better current flow for these tracks because they are vital for supplying power to not only this PCB, but also to the four daughter boards. The four 3-pin JST GH pins that are used to power the daughter boards can be seen at the bottom of the figure above. And because of the open space, the NRST tactile push button was placed right next to the BOOT0 header.

### 5.2.4 Accelerometer and temperature sensor

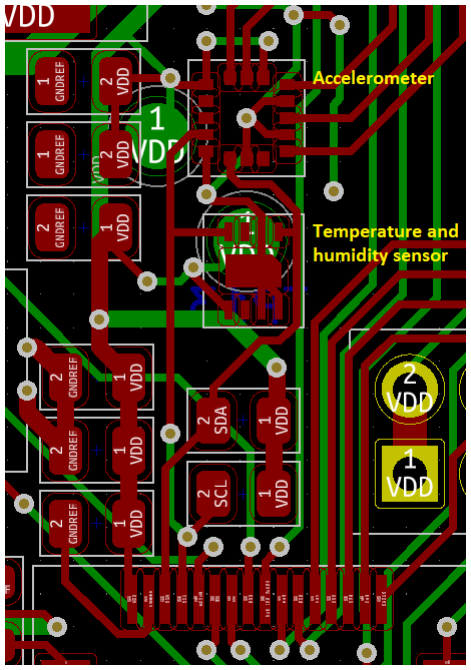
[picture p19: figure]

Figure 5.16: Accelerometer and temperature sensor routing on the PCB

The above image shows the routing for the temperature and humidity sensor as well as the accelerometer which proved to be one of the more difficult sections to route on the PCB. Because of their compact placement close the microcontroller and other components, together with the fact that these components needed to share the SDA and SCL lines, it created a bit of a challenge to do the routing.

### 5.2.5 IO expanders

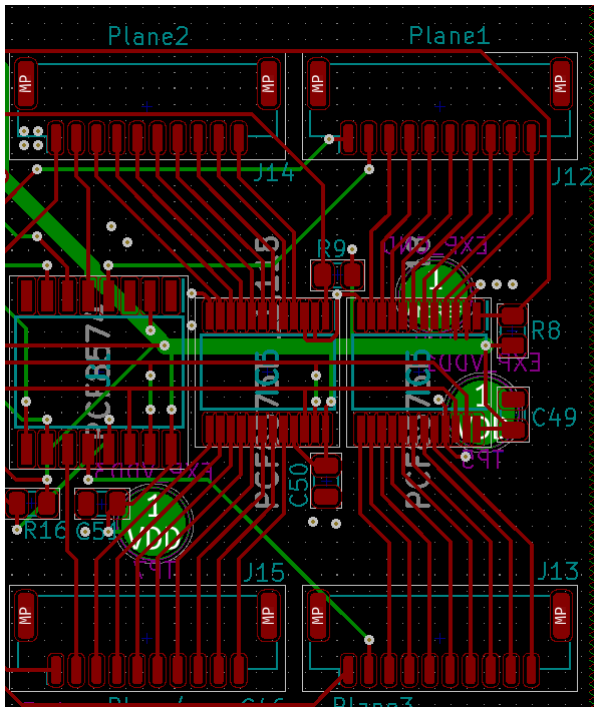
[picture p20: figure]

Figure 5.17: IO expanders routing on the PCB

The figure above shows the routing of the three IO expanders. This is an example of how tight spacing between tracks was avoided and how the tracks were placed a substantial distance away from each other. As can be seen in the image above and some of the previous images, test points were placed at the bottom layer of the PCB to aid with debugging. It was mostly the ground and supply pins to components that were connected to the test points. This is because, in the case that a component is not operating properly, it can be checked whether that component is getting power which will help in determining where the source of the problem could be. If the component is receiving power, but still does not function properly, it could be a sign that the problem lies with the component itself. But if it is found that the component is not getting power, then there could be a break or a mistake in the routing somewhere. In that case, the component could be powered through the test point to make sure that the component is working fine at least.

### 5.2.6 VDD

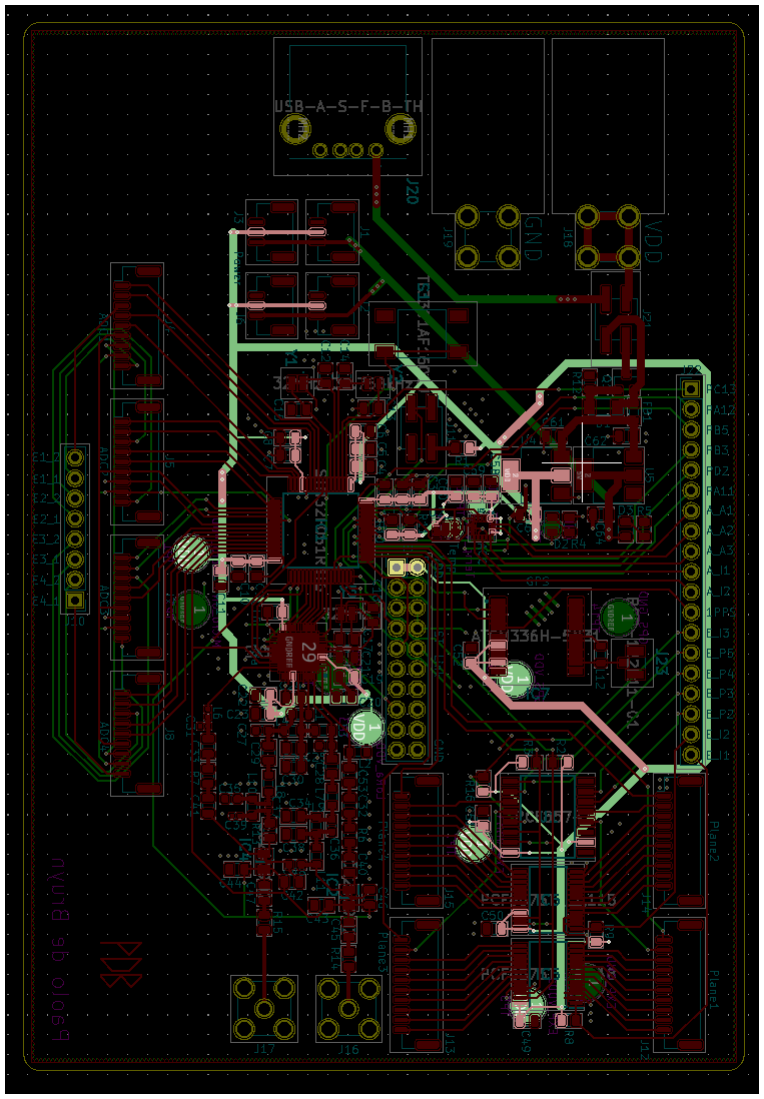
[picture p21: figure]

Figure 5.18: 3.3V supply across the PCB

During the first attempt at the design, it was decided to make the bottom plane the 3.3V supply to make it easier to reach all the components that need power. However, this only made the connection of the ground pins (which are much more in number than the power pins) much more difficult and goes against the recommendation of the AN5407 application note [39]. So instead, the power was supplied by using large 1 mm tracks to

supply all the required parts of the circuit.

### 5.2.7 Issues with initial PCB designs

Acid traps

Figure 5.19: Acid trap formed by copper tracks

The initial versions of the PCB designs contained many acid traps such as the one above. This is a problem because over the course of a few months, the corrosive material used to etch out the tracks on the PCB can erode through copper tracks causing broken connections. To understand why this happens, the process of creating the copper tracks will be explained briefly.

To start off, the core of the PCB, which is a non-conductive material such as fiberglass, has both sides completely covered with copper layers. Then, the layout of the tracks and pads are “printed” on the board with a protective layer that prevents the desired copper from being removed. Thereafter, the layers of the PCB are washed in corrosive chemicals that remove or “etch” the unwanted copper [40].

The problem with copper tracks meeting at an acute angle as shown above, is that some of these corrosive chemicals can get trapped in the area where those tracks meet. And then over time, these chemicals will continue eroding away slowly at those tracks which will eventually cause a broken connection and the PCB might fail [40]. And so, it is better if the tracks are always at obtuse angles or at least do not meet at less than 90◦ .

For this reason, these acid traps had to be fixed later on in the design to prevent this erosion from happening.

Track spacing

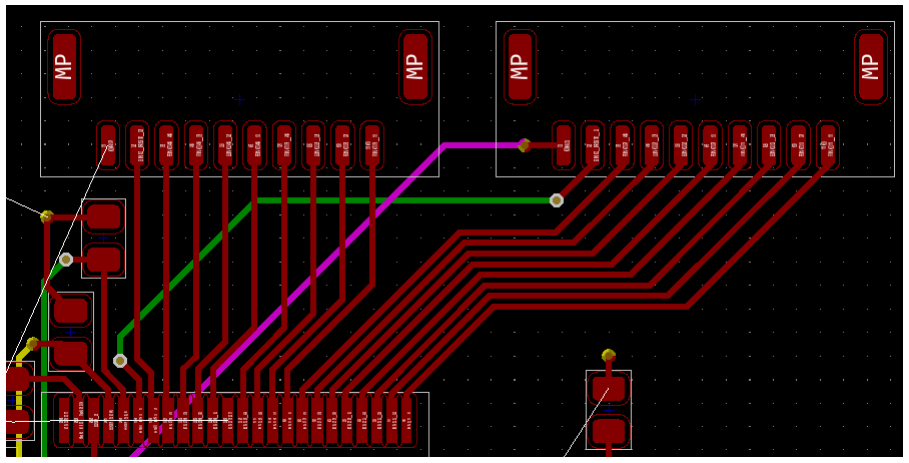
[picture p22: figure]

Figure 5.20: An initial design with poor track spacing

In initial designs, the tracks were often placed too close to each other as in the figure above. This can be a problem because there is a greater chance for these tracks to form a short circuit. It was unnecessary to have the tracks that close to each other. Sometimes there is no other choice which was the situation in Figure 5.13. But in this case, something similar to Figure 5.17 could have been done. It was ensured that in later designs the tracks had sufficient spacing.

## 5.3 Timing

In this section, the time taken from the moment a muon is detected by a scintillator block to the end of the process where data is sent via LoRa is calculated.

### 5.3.1 Timing of the daughter board

The following information, represented as a diagram, was received from Pohl which describes the timing in the daughter board:

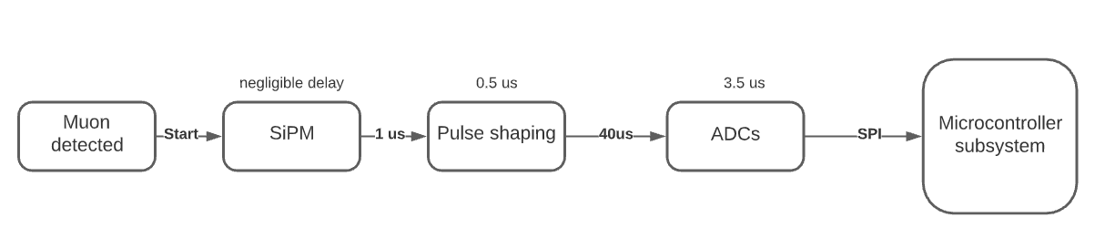
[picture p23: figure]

Figure 5.21: Timing diagram of the daughter board

The diagram starts with a muon detected by the scintillator. The luminescence generated from a scintillator block then passes to a SiPM which converts it into an electrical signal. The signal then passes to a pulse shaper which extends the signal. The extended signal then travels to an ADC where the it is sampled and converted to a digital form. The values above the boxes indicate the amount of time a component takes to process a signal, and the value on the arrow indicates the amount of time to send that signal to the next device. The subsequent timing values will be calculated starting from the time it takes to retrieve data from the ADCs.

### 5.3.2 Timing of the ADCs

The maximum SPI clock speed the STM32F051 allows is 18 MHz [25]. However, the nominal speed of the internal clock of the ADC limits the maximum SPI clock speed to 4.4 MHz [41]. In the worst case, all 8 ADCs will be activated. Because it is a 12-bit ADC, and SPI communication sends 8 bits at a time, a total of 16 bits will have to be sent to transfer the data. The additional start and stop bit for every communication that takes place must also be taken into account which brings it to a total of 18 bits that are transferred for every sample of data. It must also be taken into account that 16 samples must be read for each ADC since that is the size of the FIFO and the desired data can exist between any of those samples. Using this information, the time to transfer all the data from the ADCs can be calculated as follows:

Clock period = | 1 frequency
= | 1 4.4 MHz

= 0.227 µs

Total number of bits = 18 bits × 16 samples × 8 ADCs = 2304 bits

Total time = number of bits × clock period

= 2304 × 0.227 µs

= 0.524 ms

However, the total amount of ADC data that will need to be sent via LoRa, which excludes the start and stop bits, can be calculated as follows:

Total number of bits = 16 bits × 16 samples × 8 ADCs = 2048 bits

### 5.3.3 Timing of the IO expanders

The next step is to calculate the time it takes to read from the IO expanders that connect to the encoder section. Because of the significant amount of time taken to extend the pulse and read from the ADCs, the time taken for the signal to pass through an encoder and a latch is negligible. By the time the encoders need to be read from, the data will be available.

In the worst case, all encoders will have to be read from. Because there are 8 encoder pins per daughter board and a total of 4 boards, 32 pins will have to be read. The PCF8575 IO expanders are the only ones that will be read from to get the values of the encoder pins. The PCF8574 is only used for the reset pins of the latches.

The I²C communication on the PCF8575 works as follows. A start bit is sent by having

the SDA line go low while the SCL line is high. To set the IO expander to write mode, the bit after the 7-bit slave address for the specific IO expander is set to a zero. To read, which would be the case in this design, the last bit must be set to a one. So after these 8-bits are sent, two bytes (16 bits) are sent from the slave device with each bit corresponding to the value on a specific IO pin. After each byte sent, an acknowledge bit is sent from either the master or the slave, depending on which one is receiving data. This means that a total of 3 acknowledge bits are sent. Then, at the end of the communication, a stop bit is sent. Adding up the 3 bytes, 3 acknowledge bits, and the start and stop bits, a total of 29 bits need to be sent to read the values of one IO expander. And because there are 2 IO expanders that will have to read from, a total of 58 bits need to be sent to read from all 32 encoder lines.

Because the PCF8575 has a maximum transfer rate of 400 kbps, the time taken to read the all the encoder lines can be calculated as follows:

Total time = size of data
transfer rate

=

58
400 kbps

= 145 µs

### 5.3.4 Timing of the accelerometer

The next step is calculate the time taken to read from the accelerometer. The I²C

communication on the LIS3DHTR works as follows. Similar to the IO expanders, start and stop bits must be sent as well as acknowledge bits after every byte of data transferred. The first byte sent is the slave address of the LIS3DHTR. Next, 8 bits for the specific register to be read from must be sent. To make communication faster, the MSB bit of the register address can be set to a one to allow the address to be automatically incremented to the next register address. Because of this, the next register address to be read from does not have to be specified by the master every time. For the x-, y-, and z-coordinates of the accelerometer, there are two register addresses for each coordinate meaning that there are 2 bytes for each coordinate. Because there are 3 coordinates, a total of 6 bytes (48 bits) need to be read. Therefore, the total number of bytes that need to be communicated when reading from the accelerometer is 8 bytes. And together with the start and stop bits as well as the 8 acknowledge bits, a total of 74 bits must be sent. And because the LIS3DHTR has a maximum transfer rate of 400 kbps, the time taken to read the values from the accelerometer can be calculated as follows [30]:

Total time = size of data
transfer rate

=

74
400 kbps

= 185 µs

### 5.3.5 Timing of the temperature and humidity sensor

The I²C communication for the SHT30-DIS works as follows. As with the previous

sections, a start and stop bit must be sent as well as an acknowledge bit after every byte sent. The first byte sent is the slave address for the SHT30-DIS. Next, two command bytes are sent to start the measurement for temperature and humidity. It then takes 4.5 ms (which is the fastest possible speed) to make the measurement. Then, two bytes for

the temperature value are sent followed by another byte for the CRC checksum. Similarly for the humidity reading, two bytes must be sent for the value followed by one byte for the CRC checksum. As a result, a total of 9 bytes must be sent, together with 9 acknowledge bits, and the start and stop bit. This brings the total number of bits to 83. And because the SHT30-DIS has a maximum transfer rate of 400 kbps, the time taken to read the values from the temperature and humidity sensor can be calculated as follows [31]:

Total time = size of data
transfer rate

=

83
400 kbps

= 207.5 µs

Due to the time it takes to do a measurement, the total time taken to perform the communication with the temperature and humidity sensor is 4.7 ms (4.5 ms + 207.5 µs).

### 5.3.6 Timing of the GPS module

The ATGM336H-5N uses the NMEA0183 protocol through UART. In this protocol, different types of messages are constantly being sent in a loop by the GPS device. Each message can have a maximum of 82 characters meaning that the messages have a maximum size of 82 bytes. Assuming that the ATGM336H-5N provides the 10 messages that are normally sent by GPS devices [42], there is an absolute maximum of 820 bytes

(6560 bits) that need to be sent before the desired information is found. Because the ATGM336H-5N has a default baud rate of 9600 bps, the transmission time can be calculated as follows:

Total time = size of data
transfer rate

=

6560
9600 bps

= 683.3 ms

The only data required from the GPS to be transmitted via LoRa is the latitude and longitude. Each of these require 9 bits (8 bits for the coordinate, and one bit for either north/south or east/west), which brings it to a total of 18 bits.

### 5.3.7 Timing of the LoRa communication

The final stage of the timing is to send the data via LoRa. The following is a rough estimate of how much data needs to be sent via LoRa: 2048 bits from the ADCs; 32 bits from the encoders; 48 bits from the accelerometer; 32 bits from the temperature and humidity sensor (2 bytes for temperature and 2 bytes for humidity); and 18 bits for the

GPS coordinates. This brings the total amount of data that needs to be sent via LoRa to 2178 bits. Using a standard LoRa transfer rate of 27 kbps [17], the total time it takes

to send the data can be calculated as follows:

Total time = size of data
transfer rate

=

2178
27 kbps

= 80.7 ms

### 5.3.8 Timing conclusion

Using the above information, the final diagram for the timing is as follows:

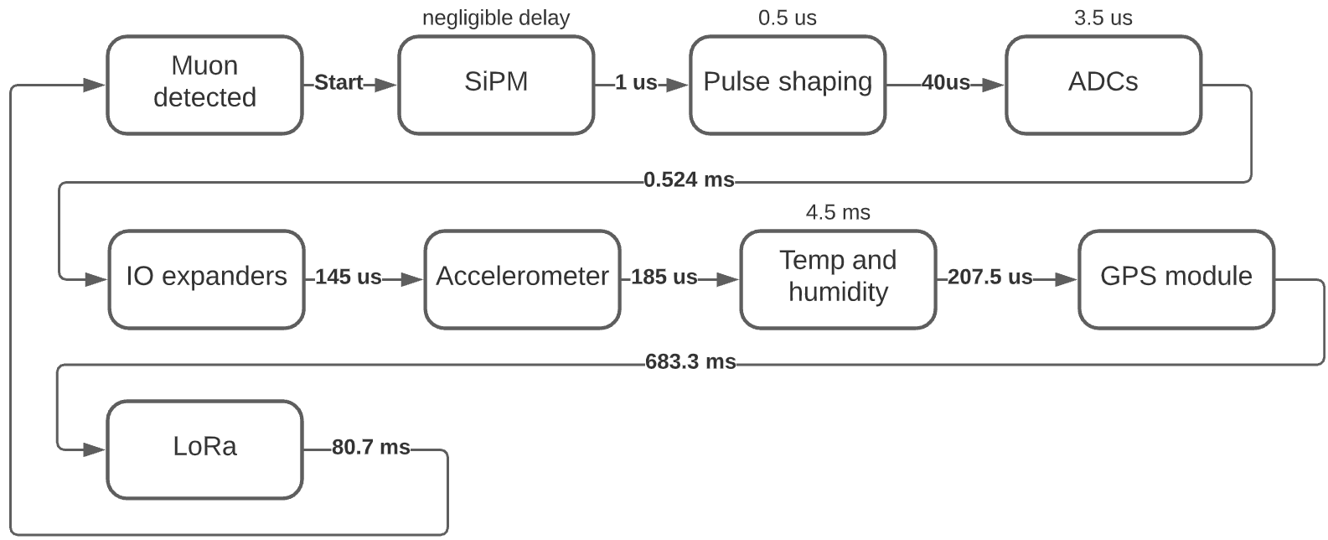
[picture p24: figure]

Figure 5.22: Final timing diagram

This diagram shows how long it takes from detecting a muon, to sending the data about the detection to a remote computer. The total time it takes can be calculated as follows by adding up the values of all the delays and time it takes to do the communication of data:

Total time = 1 µs + 0.5 µs + 40 µs + 3.5 µs + 0.524 ms + 145 µs + 185 µs + 4.5 ms+

207.5 µs + 683.3 ms + 80.7 ms

= 769.61 ms

# Chapter 6

# Results

In terms of the PCB design, all the functional requirements laid out in the Methodology and the aims described in the Introduction were achieved by this project. A PCB for the microcontroller subsystem was designed that could interface with the muon detector subsystem as well as gather additional data surrounding the muon detection and be able to send this data to a remote computer. The PCB contains the appropriate hardware components to satisfy all the functional and non-functional requirements. The PCB has an appropriate microcontroller that satisfies requirement FR002 as it would be able to run a moderately sized program. The microcontroller also has enough interfaces available to support all the peripherals that connect to it. When it was found that the microcontroller would run out of pins, IO expanders were used to compensate for it. The LoRa module is of good quality and would be able to send all the required information to a distant computer, and thereby it satisfies requirement FR007. The accelerometer, temperature and humidity sensor, and GPS module are all of good quality and would be able to perform their functionality well which satisfies requirements FR004, FR005, and FR006. Through collaboration with Pohl, the interface of the microcontroller subsystem with the muon detector subsystem was determined which satisfies requirement FR002. Using the requirements set out by Pohl’s design that an ADC must be selected that can sample at least 10 values of the output of the pulse shaping circuit, an appropriate ADC was found which satisfies requirement FR009. And through timing calculations, it was found that the time taken from the moment a muon is detected to gathering data from peripherals and sending it to a distant computer would take about 769.61 ms which satisfies requirement FR008 that this process should be completed in less than 1 second.

All the non-functional requirements laid out in the Methodology were achieved in this project. Standard components were chosen that were available from JLCPCB. The few components that were not available could easily be ordered from DigiKey and RS Components. Through this, requirement NF001 is satisfied. The track spacing on the PCB was carefully examined and design rules were used to ensure that no tracks had a spacing of less than 0.2 mm, thereby satisfying requirement NF002. The same applies for the via to pad and via to track spacing which was ensured to be more than 0.2 mm which satisfies requirement NF003. Vias that have a diameter of 0.6 mm and a drill size of 0.3 mm were used throughout the PCB design. This satisfies requirement NF004 that the diameter of the vias should be at least 0.4 mm wide and have a drill size of at least 0.2 mm. And because only two layers were used for the PCB design, no blind or buried vias were used which satisfies requirement NF005.

Regrettably, because the project only had a duration of three months, not all of the requirements and practical work could be implemented. Due to the time restrictions and the amount of time it took to design the PCB, there was not sufficient time to have the PCB manufactured at JLCPCB. Because of this, the microcontroller subsystem could not be programmed, and so it could not be tested whether all the components work well enough to satisfy the requirements of the client, the physics team, that the system should be able to be used for muon imaging. So although functional requirements FR002, FR003, FR004, FR005, FR006, FR007, and FR009 were satisfied in terms of component selection and design, there was not an opportunity to implement the programming and use these components to ensure that they satisfy the requirements. And because the physical PCB was not manufactured, FR001 could not be met. Although the theoretical timing calculations do satisfy requirement FR008, it cannot be determined for certain if it will work out the same way if it is implemented in real life.

# Chapter 7

# Conclusion

The aim of the project was to design a PCB for a microcontroller subsystem which consists of a microcontroller and additional peripherals such as an accelerometer, GPS module, and temperature and humidity sensor with which the microcontroller should be able to communicate. In addition, the PCB had to be able to interface with the muon detector subsystem designed by a master’s student, Alan Pohl, and then send the information about the muon detection, such as the GPS coordinates, trajectory of the muon, temperature, humidity, and angle of inclination of the scintillator, to a distant computer using LoRa. The system in its complete form would then be a fully developed muon detector that can be used to muon image Devil’s Peak as per the requirements of the client, the team from the physics department. Through the development of the project, a complete PCB was designed which fulfilled the hardware requirements of the microcontroller subsystem. The PCB includes all the necessary components that are necessary to produce the microcontroller subsystem such as the microcontroller, accelerometer, GPS module, temperature and humidity sensor, and LoRa module. And through collaboration with Pohl, an interface between the microcontroller subsystem and the muon detector subsystem was designed. Due to time constraints, the PCB could not be manufactured and therefore not programmed, but it lays a solid foundation for future development to create a muon detector.

# Chapter 8

# Recommendations

The following recommendations are made for future development of the project:

- Use rounded tracks in the LoRa section of the PCB layout.
- Have the PCB manufactured.
- Program the microcontroller with the control program described in the Design

section.

- Integrate the PCB with the muon detector subsystem and test the operation of the

system as a whole.

- Use a dual-core microcontroller so that the microcontroller does not have to wait for

the LoRa module to finish sending data before it checks for the arrival of another muon. The LoRa communication should run as its own process separate from the main control program.

- Include angle sensors and controlled motors to manipulate the orientation and pitch

of the scintillator plane.

- Include a length sensor together with a controlled motor to manipulate the separa-

tion between the scintillator planes.
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

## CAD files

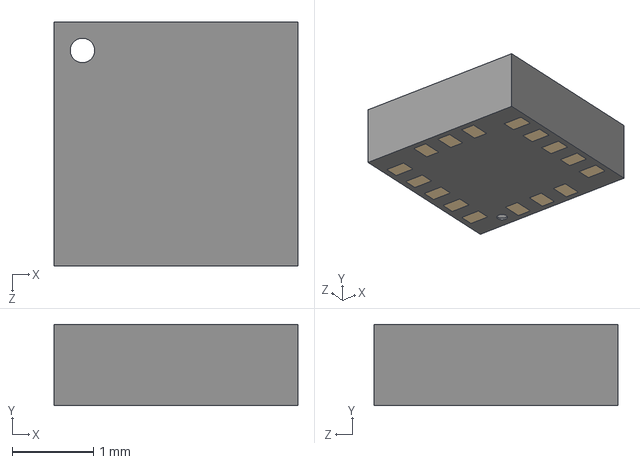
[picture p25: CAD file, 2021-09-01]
STM32WL55JC_pcb_design/STM32WL55JC_pcb_design/Accelerometer_LIS3DHTR/LIS3DHTR.step
3.00 x 1.00 x 3.00 mm

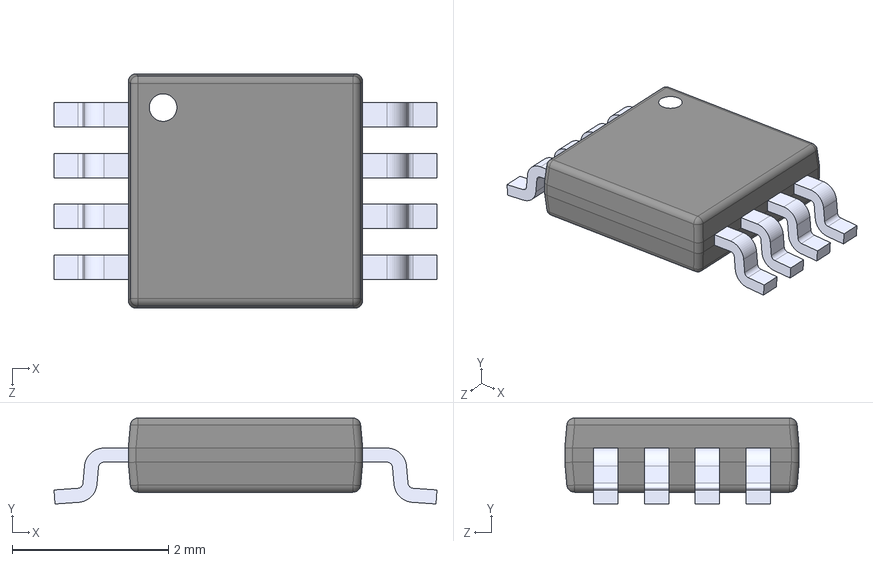
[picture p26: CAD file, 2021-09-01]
STM32WL55JC_pcb_design/STM32WL55JC_pcb_design/ADC122S021CIMM/ADC122S021CIMM.step
4.90 x 1.10 x 3.00 mm

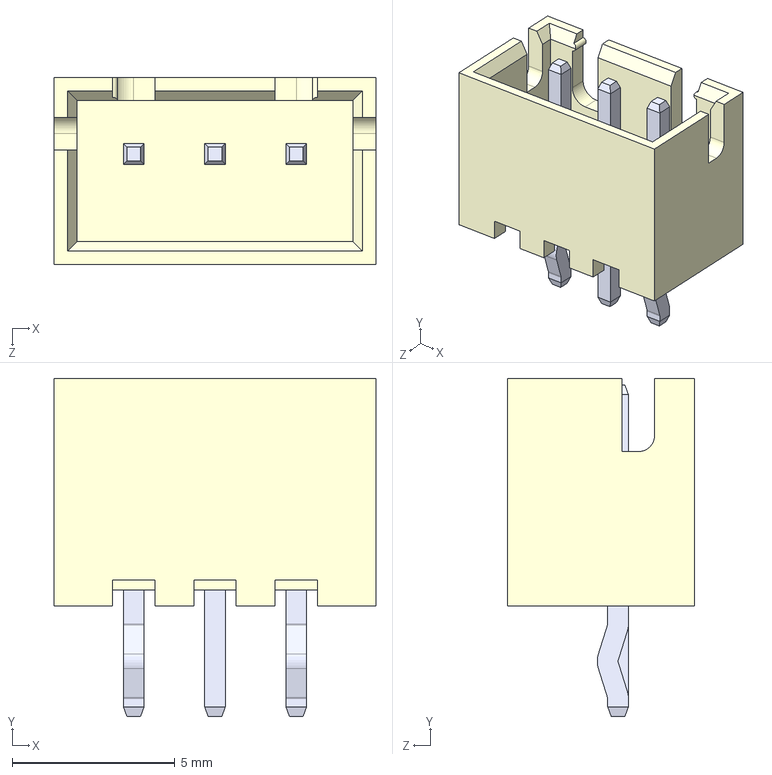
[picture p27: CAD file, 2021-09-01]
STM32WL55JC_pcb_design/STM32WL55JC_pcb_design/B3B-XH-A_LF__SN_/B3B-XH-A_LF__SN_.step
9.90 x 10.4 x 5.75 mm

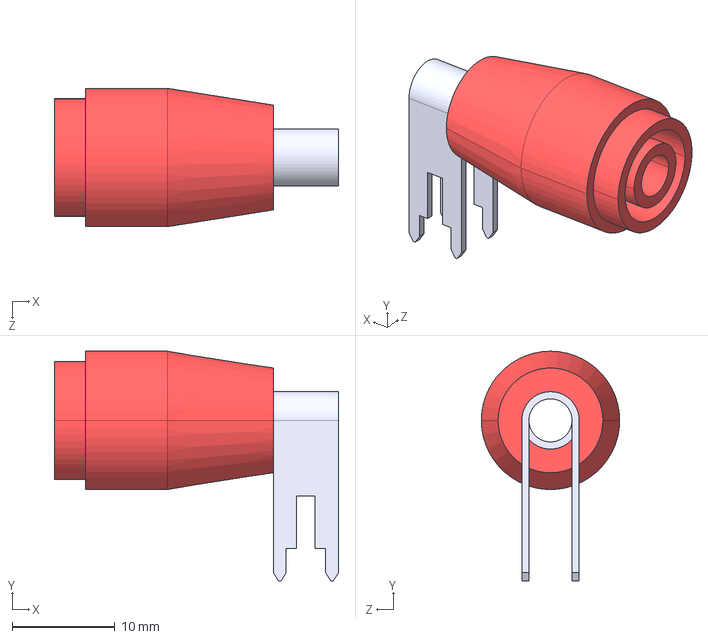
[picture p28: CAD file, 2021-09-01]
STM32WL55JC_pcb_design/STM32WL55JC_pcb_design/CT3151-2/CT3151-2.step
27.7 x 22.4 x 13.5 mm

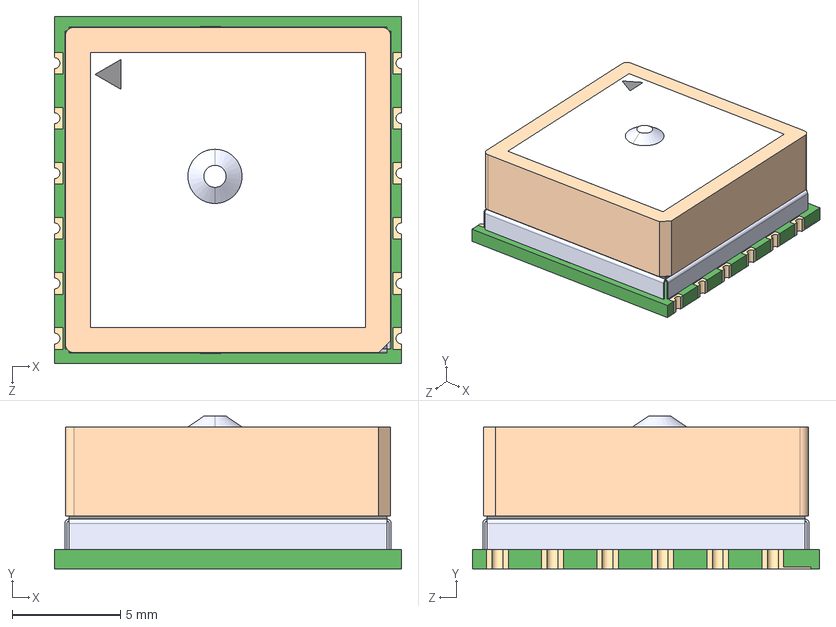
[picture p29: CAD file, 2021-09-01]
STM32WL55JC_pcb_design/STM32WL55JC_pcb_design/GPS_L80-M39/L80-M39.step
16.0 x 7.05 x 16.0 mm

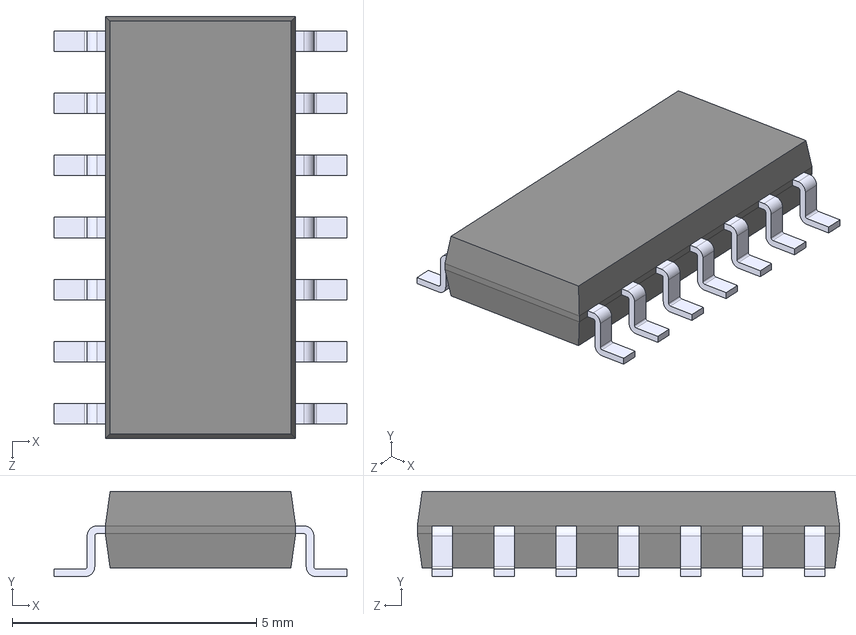
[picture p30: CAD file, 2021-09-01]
STM32WL55JC_pcb_design/STM32WL55JC_pcb_design/LM339DR/LM339DR.step
6.00 x 1.75 x 8.65 mm

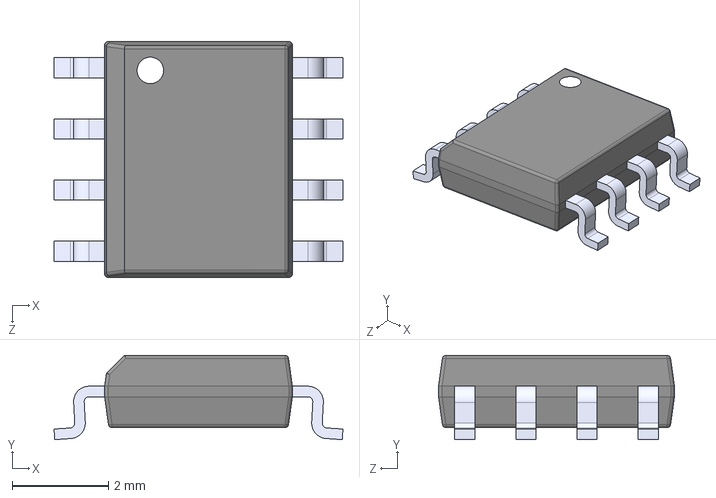
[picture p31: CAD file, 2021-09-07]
STM32WL55JC_pcb_design/STM32WL55JC_pcb_design/ADC08831IM/ADC08831IM.step
6.00 x 1.75 x 4.90 mm

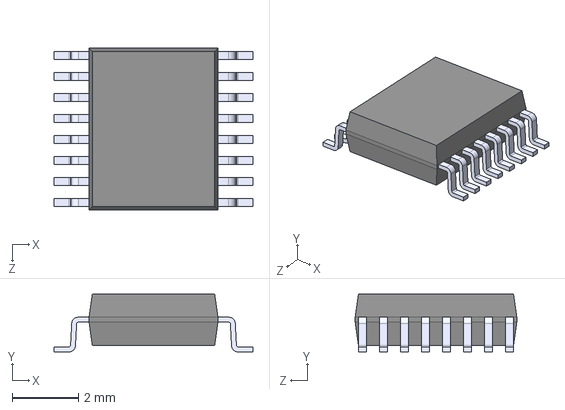
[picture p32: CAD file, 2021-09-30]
STM32WL55JC_pcb_design/STM32WL55JC_pcb_design/ADC_FIFO_MAX11635EEET/MAX11635EEET.step
6.02 x 1.75 x 4.89 mm

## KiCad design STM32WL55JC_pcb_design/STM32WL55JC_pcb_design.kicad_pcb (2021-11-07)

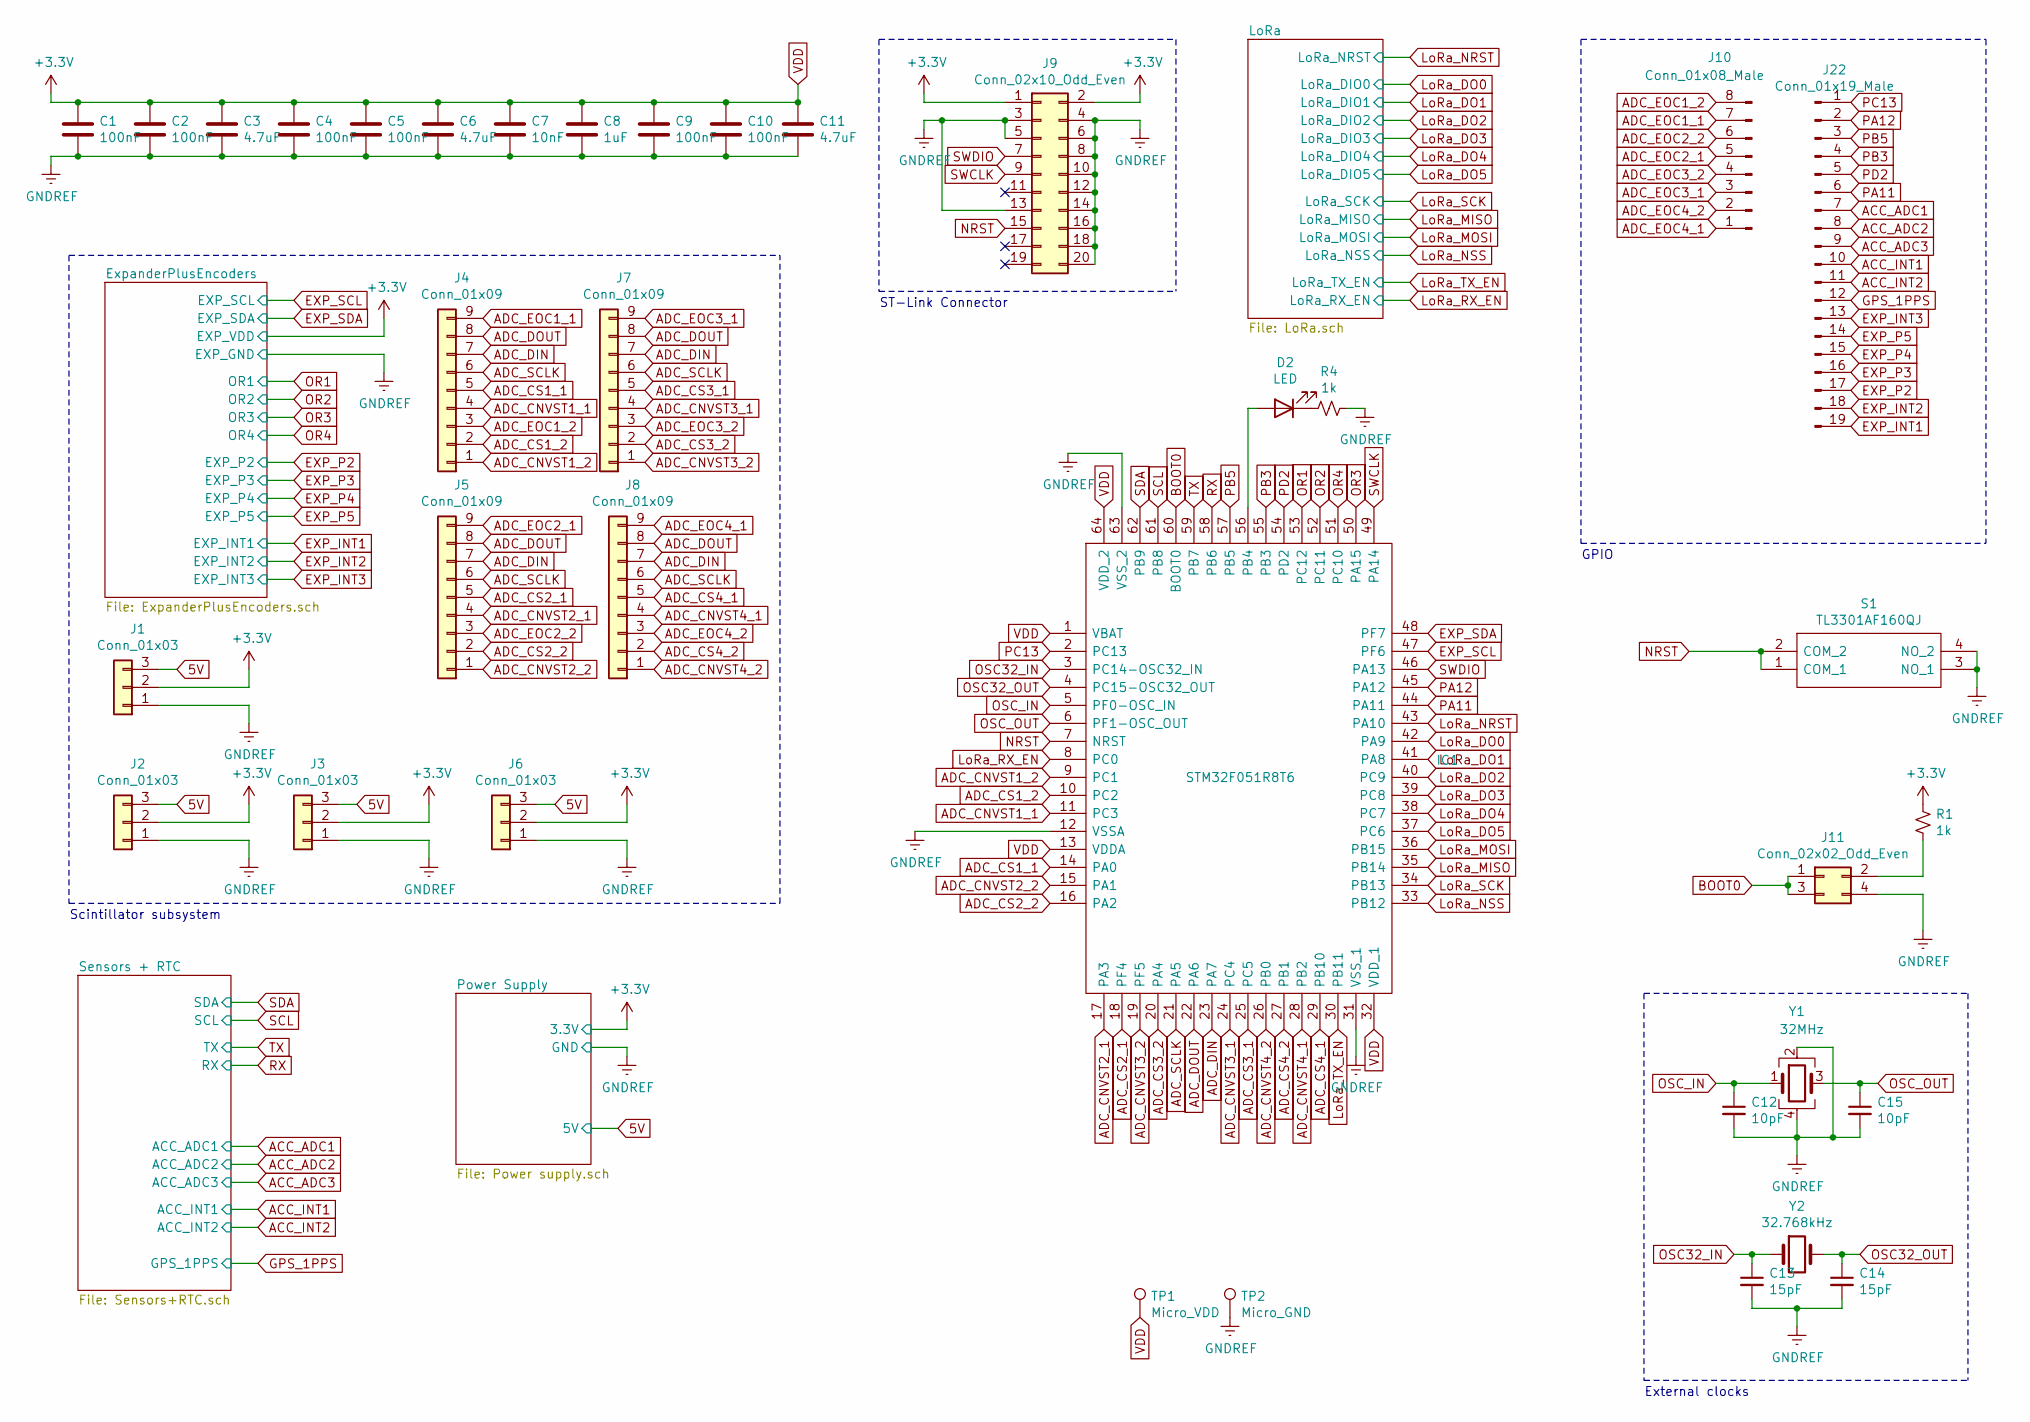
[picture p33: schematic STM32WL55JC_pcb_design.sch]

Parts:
C1, C2, C4, C5, C9, C10: 100nF; C_0805_2012Metric
C3, C6, C11: 4.7uF; C_0805_2012Metric
C7: 10nF; C_0805_2012Metric
C8: 1uF; C_0805_2012Metric
C12, C15: 10pF; C_0805_2012Metric
C13, C14: 15pF; C_0805_2012Metric
D2: LED; LED_0805_2012Metric
IC1: STM32F051R8T6; QFP50P1200X1200X160-64N; Manufacturer_Part_Number STM32F051R8T6; Mouser Part Number 511-STM32F051R8T6
J1, J2, J3, J6: Conn_01x03; JST_GH_BM03B-GHS-TBT_1x03-1MP_P1.25mm_Vertical
J4, J5, J7, J8: Conn_01x09; JST_GH_BM09B-GHS-TBT_1x09-1MP_P1.25mm_Vertical
J9: Conn_02x10_Odd_Even; PinHeader_2x10_P2.54mm_Vertical
J10: Conn_01x08_Male; PinHeader_1x08_P2.54mm_Vertical
J11: Conn_02x02_Odd_Even; PinHeader_2x02_P2.54mm_Vertical_SMD
J22: Conn_01x19_Male; PinHeader_1x19_P2.54mm_Vertical
R1, R4: 1k; R_0805_2012Metric
S1: TL3301AF160QJ; Manufacturer_Part_Number TL3301AF160QJ; Mouser Part Number 612-TL3301AJ
TP1: Micro_VDD; TestPoint_Pad_D4.0mm
TP2: Micro_GND; TestPoint_Pad_D4.0mm
Y1: 32MHz; NX2016SA32MEXS00ACS06465
Y2: 32.768kHz; SC20S125PF20PPM

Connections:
5V: J1.3, J2.3, J3.3, J6.3; also elsewhere on the board
ACC_ADC1: J22.7; also elsewhere on the board
ACC_ADC2: J22.8; also elsewhere on the board
ACC_ADC3: J22.9; also elsewhere on the board
ACC_INT1: J22.10; also elsewhere on the board
ACC_INT2: J22.11; also elsewhere on the board
ADC_CNVST1_1: IC1.11 (PC3), J4.4
ADC_CNVST1_2: IC1.9 (PC1), J4.1
ADC_CNVST2_1: IC1.17 (PA3), J5.4
ADC_CNVST2_2: IC1.15 (PA1), J5.1
ADC_CNVST3_1: IC1.24 (PC4), J7.4
ADC_CNVST3_2: IC1.19 (PF5), J7.1
ADC_CNVST4_1: IC1.28 (PB2), J8.4
ADC_CNVST4_2: IC1.26 (PB0), J8.1
ADC_CS1_1: IC1.14 (PA0), J4.5
ADC_CS1_2: IC1.10 (PC2), J4.2
ADC_CS2_1: IC1.18 (PF4), J5.5
ADC_CS2_2: IC1.16 (PA2), J5.2
ADC_CS3_1: IC1.25 (PC5), J7.5
ADC_CS3_2: IC1.20 (PA4), J7.2
ADC_CS4_1: IC1.29 (PB10), J8.5
ADC_CS4_2: IC1.27 (PB1), J8.2
ADC_DIN: IC1.23 (PA7), J4.7, J5.7, J7.7, J8.7
ADC_DOUT: IC1.22 (PA6), J4.8, J5.8, J7.8, J8.8
ADC_EOC1_1: J4.9, J10.7
ADC_EOC1_2: J4.3, J10.8
ADC_EOC2_1: J5.9, J10.5
ADC_EOC2_2: J5.3, J10.6
ADC_EOC3_1: J7.9, J10.3
ADC_EOC3_2: J7.3, J10.4
ADC_EOC4_1: J8.9, J10.1
ADC_EOC4_2: J8.3, J10.2
ADC_SCLK: IC1.21 (PA5), J4.6, J5.6, J7.6, J8.6
BOOT0: IC1.60 (BOOT0), J11.1, J11.3
EXP_INT1: J22.19; also elsewhere on the board
EXP_INT2: J22.18; also elsewhere on the board
EXP_INT3: J22.13; also elsewhere on the board
EXP_P2: J22.17; also elsewhere on the board
EXP_P3: J22.16; also elsewhere on the board
EXP_P4: J22.15; also elsewhere on the board
EXP_P5: J22.14; also elsewhere on the board
EXP_SCL: IC1.47 (PF6); also elsewhere on the board
EXP_SDA: IC1.48 (PF7); also elsewhere on the board
GNDREF: C1.2, C2.2, C3.2, C4.2, C5.2, C6.2, C7.2, C8.2, C9.2, C10.2, C11.2, C12.2, C13.2, C14.2, C15.2, IC1.12 (VSSA), IC1.31 (VSS_1), IC1.63 (VSS_2), J1.1, J2.1, J3.1, J6.1, J9.3, J9.4, J9.5, J9.6, J9.8, J9.10, J9.12, J9.13, J9.14, J9.16, J9.18, J9.20, J11.4, R4.1, S1.3 (NO_1), S1.4 (NO_2), TP2.1, Y1.2, Y1.4; also elsewhere on the board
GPS_1PPS: J22.12; also elsewhere on the board
LoRa_DO0: IC1.42 (PA9); also elsewhere on the board
LoRa_DO1: IC1.41 (PA8); also elsewhere on the board
LoRa_DO2: IC1.40 (PC9); also elsewhere on the board
LoRa_DO3: IC1.39 (PC8); also elsewhere on the board
LoRa_DO4: IC1.38 (PC7); also elsewhere on the board
LoRa_DO5: IC1.37 (PC6); also elsewhere on the board
LoRa_MISO: IC1.35 (PB14); also elsewhere on the board
LoRa_MOSI: IC1.36 (PB15); also elsewhere on the board
LoRa_NRST: IC1.43 (PA10); also elsewhere on the board
LoRa_NSS: IC1.33 (PB12); also elsewhere on the board
LoRa_RX_EN: IC1.8 (PC0); also elsewhere on the board
LoRa_SCK: IC1.34 (PB13); also elsewhere on the board
LoRa_TX_EN: IC1.30 (PB11); also elsewhere on the board
NRST: IC1.7 (NRST), J9.15, S1.1 (COM_1), S1.2 (COM_2)
unnamed: D2.1 (K), R4.2
unnamed: D2.2 (A), IC1.56 (PB4)
unnamed: J11.2, R1.2
OR1: IC1.53 (PC12); also elsewhere on the board
OR2: IC1.52 (PC11); also elsewhere on the board
OR3: IC1.50 (PA15); also elsewhere on the board
OR4: IC1.51 (PC10); also elsewhere on the board
OSC32_IN: C13.1, IC1.3 (PC14-OSC32_IN), Y2.1
OSC32_OUT: C14.1, IC1.4 (PC15-OSC32_OUT), Y2.2
OSC_IN: C12.1, IC1.5 (PF0-OSC_IN), Y1.1
OSC_OUT: C15.1, IC1.6 (PF1-OSC_OUT), Y1.3
PA11: IC1.44 (PA11), J22.6
PA12: IC1.45 (PA12), J22.2
PB3: IC1.55 (PB3), J22.4
PB5: IC1.57 (PB5), J22.3
PC13: IC1.2 (PC13), J22.1
PD2: IC1.54 (PD2), J22.5
RX: IC1.58 (PB6); also elsewhere on the board
SCL: IC1.61 (PB8); also elsewhere on the board
SDA: IC1.62 (PB9); also elsewhere on the board
SWCLK: IC1.49 (PA14), J9.9
SWDIO: IC1.46 (PA13), J9.7
TX: IC1.59 (PB7); also elsewhere on the board
VDD: C1.1, C2.1, C3.1, C4.1, C5.1, C6.1, C7.1, C8.1, C9.1, C10.1, C11.1, IC1.1 (VBAT), IC1.13 (VDDA), IC1.32 (VDD_1), IC1.64 (VDD_2), J1.2, J2.2, J3.2, J6.2, J9.1, J9.2, R1.1, TP1.1; also elsewhere on the board

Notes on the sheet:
Scintillator subsystem
ST-Link Connector
GPIO
External clocks

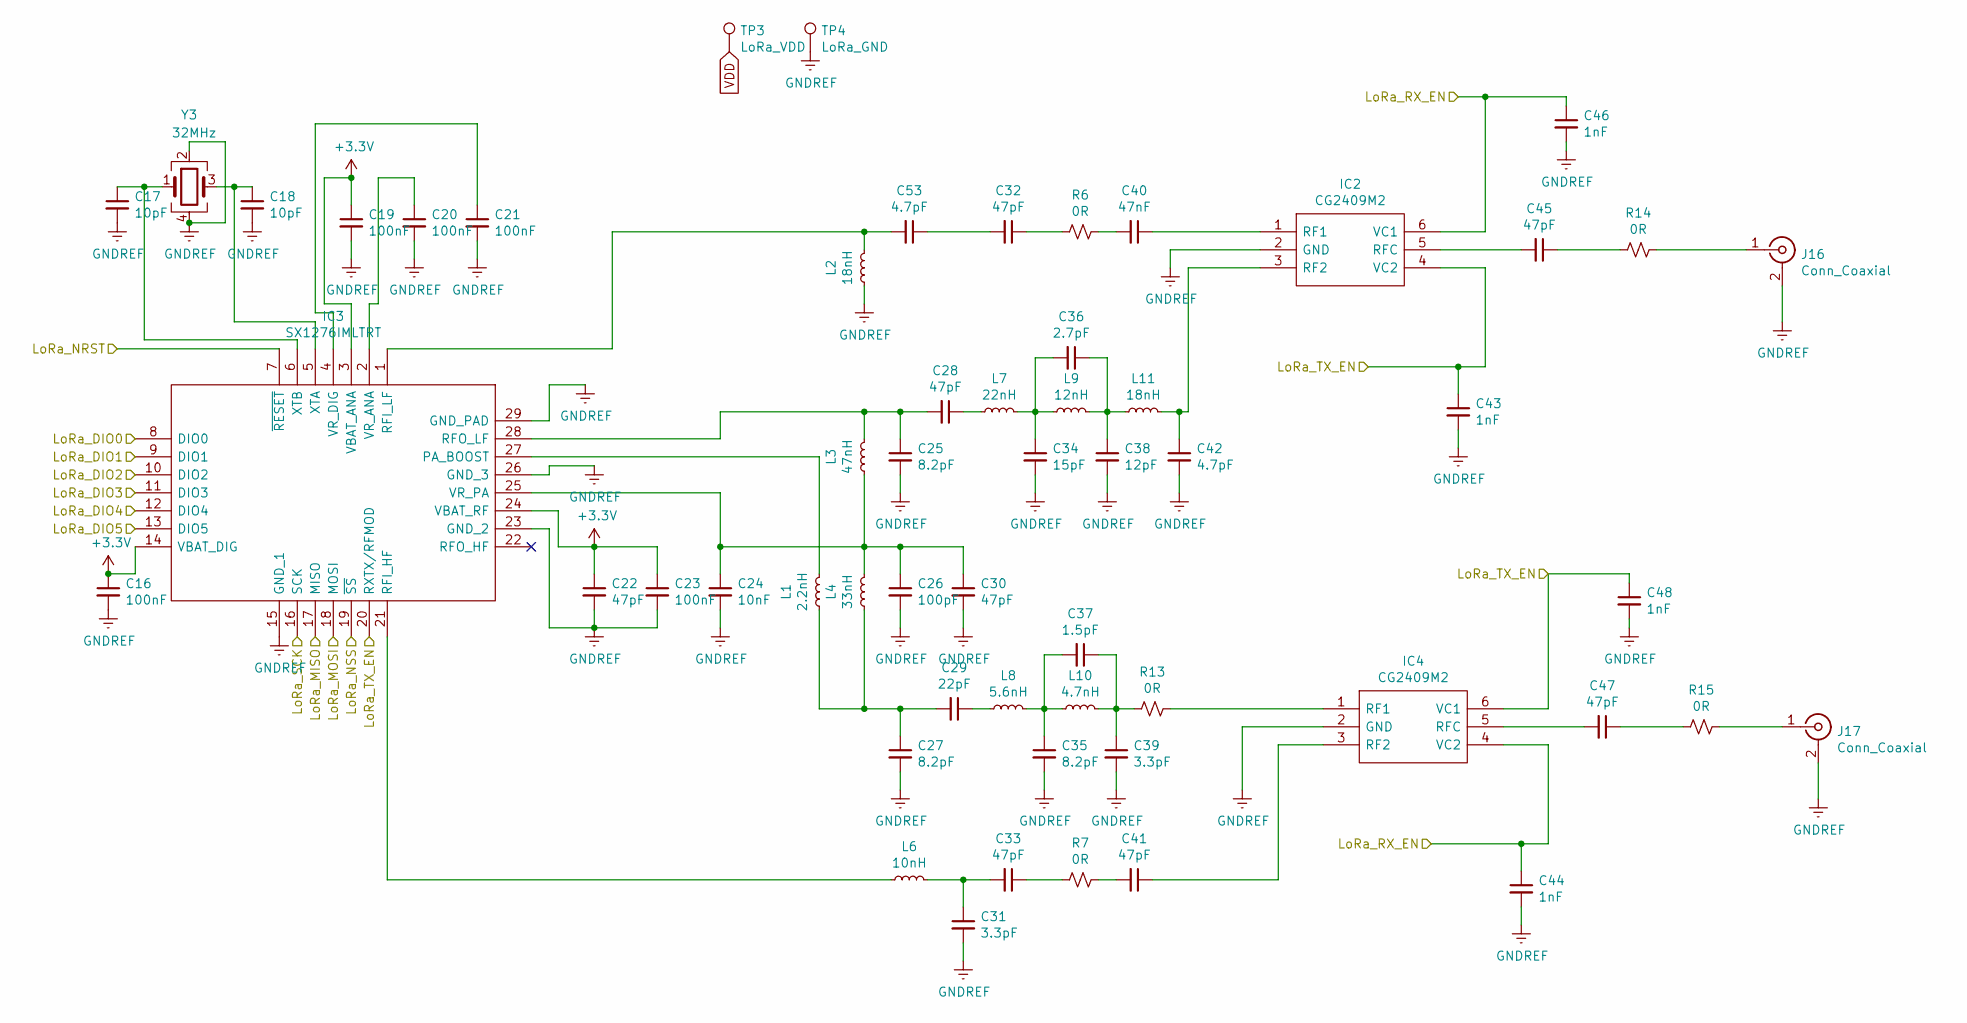
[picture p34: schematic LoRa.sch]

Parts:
C16, C19, C20, C21, C23: 100nF; C_0805_2012Metric
C17, C18: 10pF; C_0805_2012Metric
C22, C28, C30, C32, C33, C41, C45, C47: 47pF; C_0805_2012Metric
C24: 10nF; C_0805_2012Metric
C25, C27, C35: 8.2pF; C_0603_1608Metric
C26: 100pF; C_0805_2012Metric
C29: 22pF; C_0805_2012Metric
C31, C39: 3.3pF; C_0402_1005Metric
C34: 15pF; C_0805_2012Metric
C36: 2.7pF; C_0603_1608Metric
C37: 1.5pF; C_0402_1005Metric
C38: 12pF; C_0805_2012Metric
C40: 47nF; C_0805_2012Metric
C42: 4.7pF; C_0603_1608Metric
C43, C44, C46, C48: 1nF; C_0805_2012Metric
C53: 4.7pF; C_0805_2012Metric
IC2, IC4: CG2409M2; CKRF2406XS03-C2; Manufacturer_Part_Number CG2409M2; Mouser Part Number 551-CG2409M2
IC3: SX1276IMLTRT; QFN65P600X600X100-29N; Manufacturer_Part_Number SX1276IMLTRT; Mouser Part Number 947-SX1276IMLTRT
J16, J17: Conn_Coaxial; SMA_Amphenol_901-144_Vertical
L1: 2.2nH; L_0805_2012Metric
L2, L11: 18nH; L_0805_2012Metric
L3: 47nH; L_0805_2012Metric
L4: 33nH; L_0805_2012Metric
L6: 10nH; L_0402_1005Metric
L7: 22nH; L_0805_2012Metric
L8: 5.6nH; L_0805_2012Metric
L9: 12nH; L_0805_2012Metric
L10: 4.7nH; L_0805_2012Metric
R6, R7, R13, R14, R15: 0R; R_0805_2012Metric
TP3: LoRa_VDD; TestPoint_Pad_D4.0mm
TP4: LoRa_GND; TestPoint_Pad_D4.0mm
Y3: 32MHz; NX2016SA32MEXS00ACS06465

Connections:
GNDREF: C16.2, C17.2, C18.2, C19.2, C20.2, C21.2, C22.2, C23.2, C24.2, C25.2, C26.2, C27.2, C30.2, C31.2, C34.2, C35.2, C38.2, C39.2, C42.2, C43.2, C44.2, C46.2, C48.2, IC2.2 (GND), IC3.15 (GND_1), IC3.23 (GND_2), IC3.26 (GND_3), IC3.29 (GND_PAD), IC4.2 (GND), J16.2 (Ext), J17.2 (Ext), L2.1, TP4.1, Y3.2, Y3.4; also elsewhere on the board
LoRa_DO0: IC3.8 (DIO0); also elsewhere on the board
LoRa_DO1: IC3.9 (DIO1); also elsewhere on the board
LoRa_DO2: IC3.10 (DIO2); also elsewhere on the board
LoRa_DO3: IC3.11 (DIO3); also elsewhere on the board
LoRa_DO4: IC3.12 (DIO4); also elsewhere on the board
LoRa_DO5: IC3.13 (DIO5); also elsewhere on the board
LoRa_MISO: IC3.17 (MISO); also elsewhere on the board
LoRa_MOSI: IC3.18 (MOSI); also elsewhere on the board
LoRa_NRST: IC3.7 (~RESET); also elsewhere on the board
LoRa_NSS: IC3.19 (~SS); also elsewhere on the board
LoRa_RX_EN: C44.1, C46.1, IC2.6 (VC1), IC4.4 (VC2); also elsewhere on the board
LoRa_SCK: IC3.16 (SCK); also elsewhere on the board
LoRa_TX_EN: C43.1, C48.1, IC2.4 (VC2), IC3.20 (RXTX/RFMOD), IC4.6 (VC1); also elsewhere on the board
unnamed: C17.1, IC3.6 (XTB), Y3.1
unnamed: C18.1, IC3.5 (XTA), Y3.3
unnamed: C20.1, IC3.2 (VR_ANA)
unnamed: C21.1, IC3.4 (VR_DIG)
unnamed: C24.1, C26.1, C30.1, IC3.25 (VR_PA), L3.1, L4.2
unnamed: C25.1, C28.2, IC3.28 (RFO_LF), L3.2
unnamed: C27.1, C29.2, L1.1, L4.1
unnamed: C28.1, L7.1
unnamed: C29.1, L8.1
unnamed: C31.1, C33.2, L6.2
unnamed: C32.1, R6.1
unnamed: C32.2, C53.1
unnamed: C33.1, R7.1
unnamed: C34.1, C36.2, L7.2, L9.1
unnamed: C35.1, C37.2, L8.2, L10.1
unnamed: C36.1, C38.1, L9.2, L11.1
unnamed: C37.1, C39.1, L10.2, R13.1
unnamed: C40.1, IC2.1 (RF1)
unnamed: C40.2, R6.2
unnamed: C41.1, IC4.3 (RF2)
unnamed: C41.2, R7.2
unnamed: C42.1, IC2.3 (RF2), L11.2
unnamed: C45.1, R14.1
unnamed: C45.2, IC2.5 (RFC)
unnamed: C47.1, R15.1
unnamed: C47.2, IC4.5 (RFC)
unnamed: C53.2, IC3.1 (RFI_LF), L2.2
unnamed: IC3.21 (RFI_HF), L6.1
unnamed: IC3.27 (PA_BOOST), L1.2
unnamed: IC4.1 (RF1), R13.2
unnamed: J16.1 (In), R14.2
unnamed: J17.1 (In), R15.2
VDD: C16.1, C19.1, C22.1, C23.1, IC3.3 (VBAT_ANA), IC3.14 (VBAT_DIG), IC3.24 (VBAT_RF), TP3.1; also elsewhere on the board

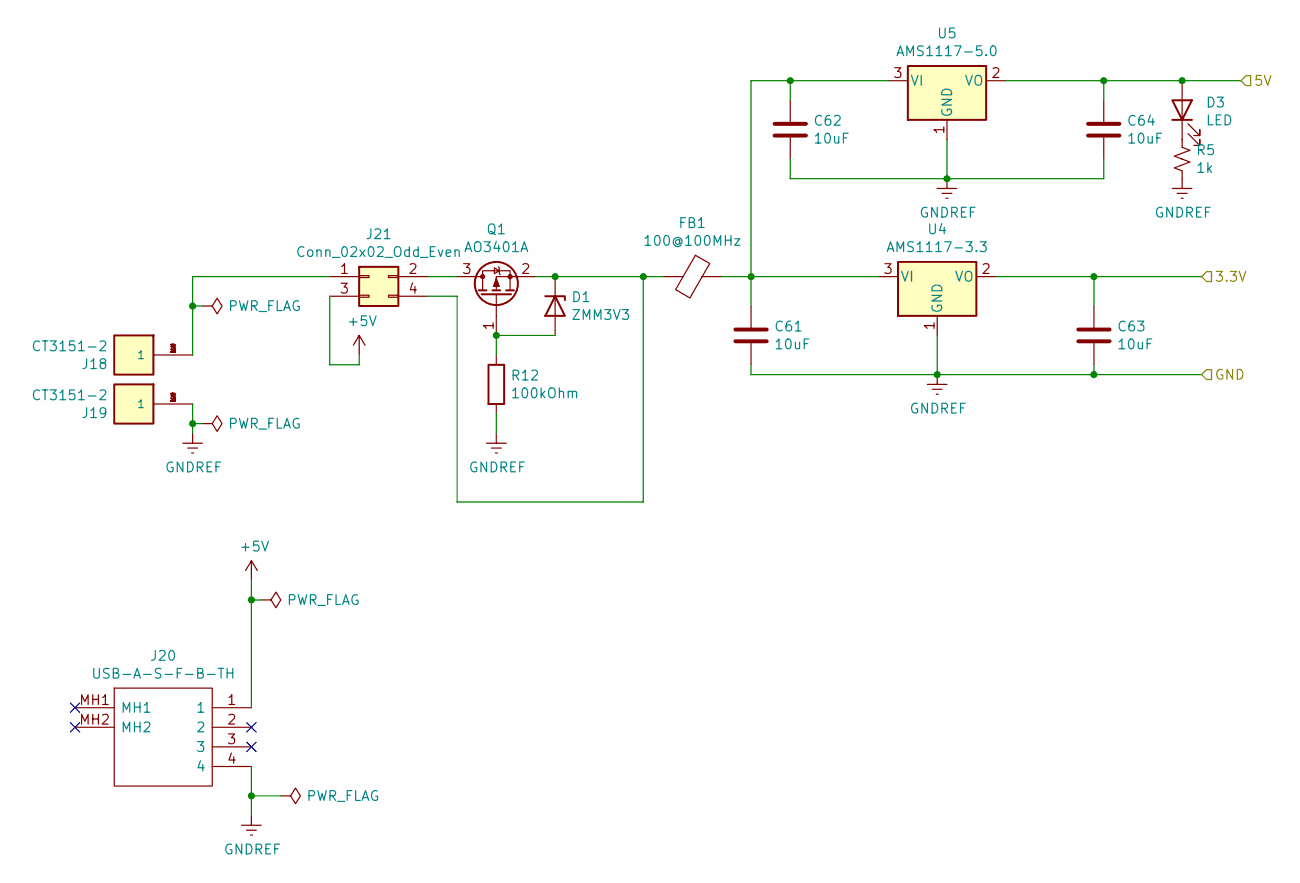
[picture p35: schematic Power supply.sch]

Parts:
C61, C62, C63, C64: 10uF; C_0805_2012Metric
D1: ZMM3V3; D_MiniMELF
D3: LED; LED_0805_2012Metric
FB1: 100@100MHz; L_0805_2012Metric
J18, J19: CT3151-2; CALTEST_CT3151-2; PARTREV H
J20: USB-A-S-F-B-TH; USBASFBTH; Manufacturer_Part_Number USB-A-S-F-B-TH; Mouser Part Number 200-USBASFBTH
J21: Conn_02x02_Odd_Even; PinHeader_2x02_P2.54mm_Vertical_SMD
Q1: AO3401A; SOT-23
R5: 1k; R_0805_2012Metric
R12: 100kOhm; R_0805_2012Metric
U4: AMS1117-3.3; SOT-223-3_TabPin2
U5: AMS1117-5.0; SOT-223-3_TabPin2

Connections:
5V: C64.1, D3.2 (A), U5.2 (VO); also elsewhere on the board
+5V: J20.1, J21.3
GNDREF: C61.2, C62.2, C63.2, C64.2, J19.1, J19.2, J19.3, J19.4, J20.4, R5.2, R12.2, U4.1 (GND), U5.1 (GND); also elsewhere on the board
unnamed: C61.1, C62.1, FB1.1, U4.3 (VI), U5.3 (VI)
unnamed: D1.1 (K), FB1.2, J21.4, Q1.2 (S)
unnamed: D1.2 (A), Q1.1 (G), R12.1
unnamed: D3.1 (K), R5.1
unnamed: J18.1, J18.2, J18.3, J18.4, J21.1
unnamed: J21.2, Q1.3 (D)
VDD: C63.1, U4.2 (VO); also elsewhere on the board

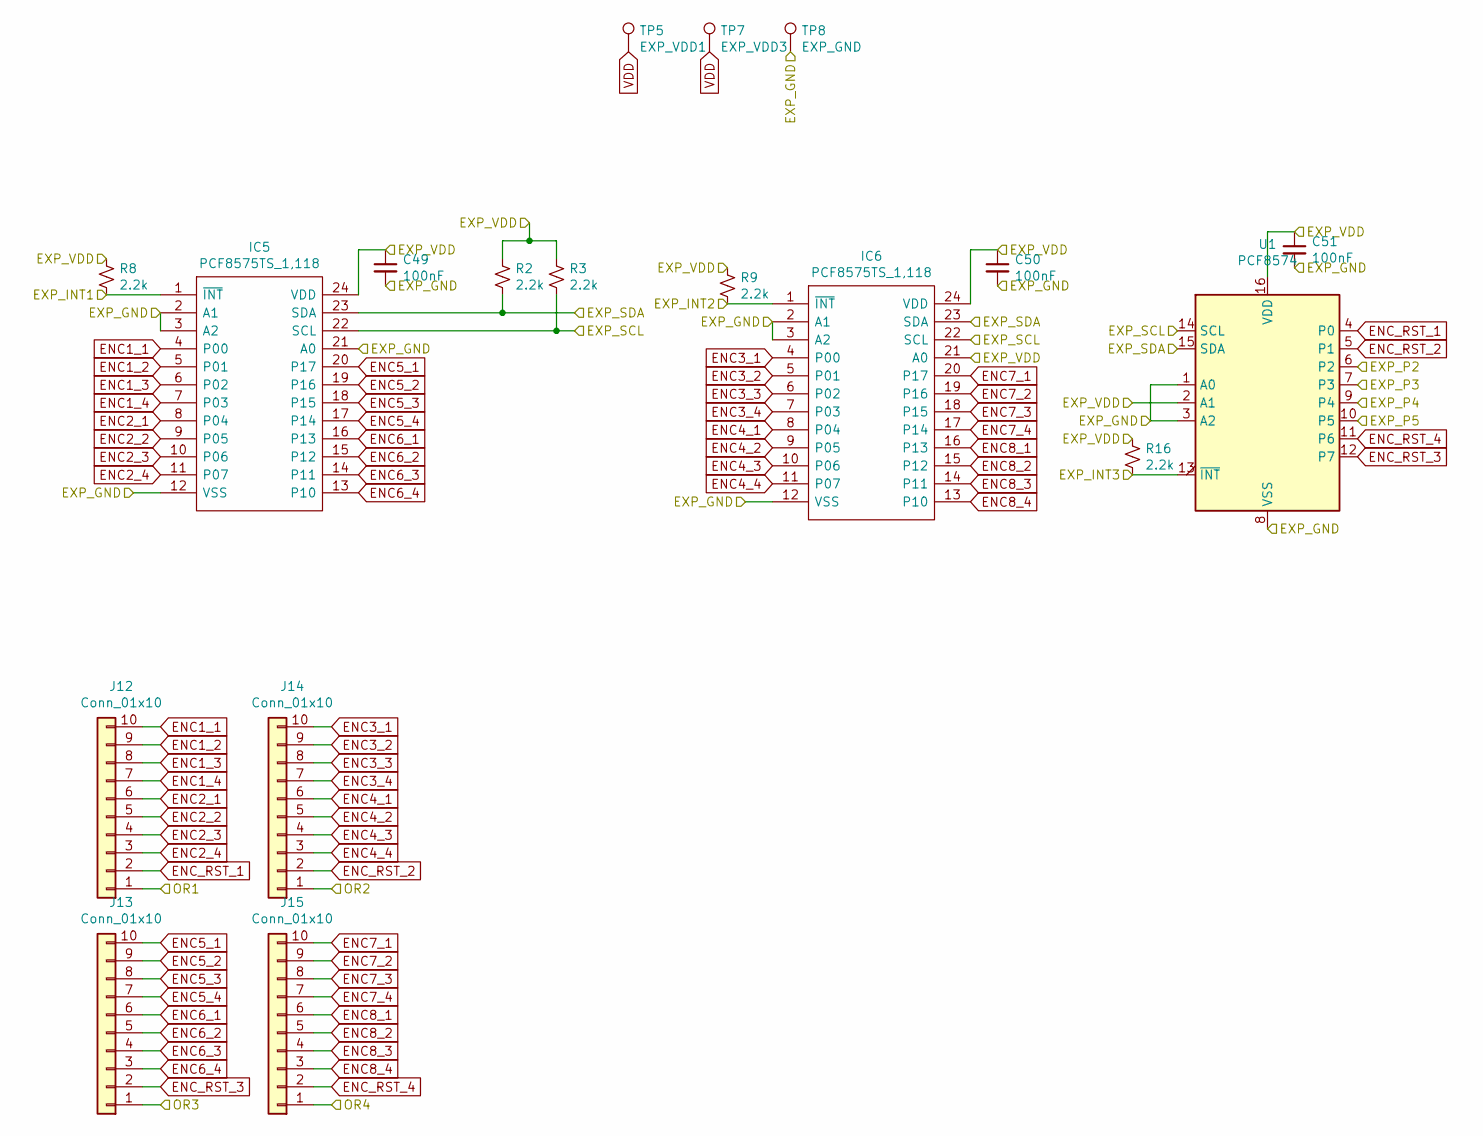
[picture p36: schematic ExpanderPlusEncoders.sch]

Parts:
C49, C50, C51: 100nF; C_0805_2012Metric
IC5, IC6: PCF8575TS_1,118; SOP65P775X200-24N; Manufacturer_Part_Number PCF8575TS/1,118; Mouser Part Number 771-PCF8575TSDB-T
J12, J13, J14, J15: Conn_01x10; JST_GH_BM10B-GHS-TBT_1x10-1MP_P1.25mm_Vertical
R2, R3, R8, R9, R16: 2.2k; R_0805_2012Metric
TP5: EXP_VDD1; TestPoint_Pad_D4.0mm
TP7: EXP_VDD3; TestPoint_Pad_D4.0mm
TP8: EXP_GND; TestPoint_Pad_D4.0mm
U1: PCF8574; SOIC127P1032X265-16N

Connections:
ENC1_1: IC5.4 (P00), J12.10
ENC1_2: IC5.5 (P01), J12.9
ENC1_3: IC5.6 (P02), J12.8
ENC1_4: IC5.7 (P03), J12.7
ENC2_1: IC5.8 (P04), J12.6
ENC2_2: IC5.9 (P05), J12.5
ENC2_3: IC5.10 (P06), J12.4
ENC2_4: IC5.11 (P07), J12.3
ENC3_1: IC6.4 (P00), J14.10
ENC3_2: IC6.5 (P01), J14.9
ENC3_3: IC6.6 (P02), J14.8
ENC3_4: IC6.7 (P03), J14.7
ENC4_1: IC6.8 (P04), J14.6
ENC4_2: IC6.9 (P05), J14.5
ENC4_3: IC6.10 (P06), J14.4
ENC4_4: IC6.11 (P07), J14.3
ENC5_1: IC5.20 (P17), J13.10
ENC5_2: IC5.19 (P16), J13.9
ENC5_3: IC5.18 (P15), J13.8
ENC5_4: IC5.17 (P14), J13.7
ENC6_1: IC5.16 (P13), J13.6
ENC6_2: IC5.15 (P12), J13.5
ENC6_3: IC5.14 (P11), J13.4
ENC6_4: IC5.13 (P10), J13.3
ENC7_1: IC6.20 (P17), J15.10
ENC7_2: IC6.19 (P16), J15.9
ENC7_3: IC6.18 (P15), J15.8
ENC7_4: IC6.17 (P14), J15.7
ENC8_1: IC6.16 (P13), J15.6
ENC8_2: IC6.15 (P12), J15.5
ENC8_3: IC6.14 (P11), J15.4
ENC8_4: IC6.13 (P10), J15.3
ENC_RST_1: J12.2, U1.4 (P0)
ENC_RST_2: J14.2, U1.5 (P1)
ENC_RST_3: J13.2, U1.12 (P7)
ENC_RST_4: J15.2, U1.11 (P6)
EXP_INT1: IC5.1 (~INT), R8.2; also elsewhere on the board
EXP_INT2: IC6.1 (~INT), R9.2; also elsewhere on the board
EXP_INT3: R16.2, U1.13 (~INT~); also elsewhere on the board
EXP_P2: U1.6 (P2); also elsewhere on the board
EXP_P3: U1.7 (P3); also elsewhere on the board
EXP_P4: U1.9 (P4); also elsewhere on the board
EXP_P5: U1.10 (P5); also elsewhere on the board
EXP_SCL: IC5.22 (SCL), IC6.22 (SCL), R3.2, U1.14 (SCL); also elsewhere on the board
EXP_SDA: IC5.23 (SDA), IC6.23 (SDA), R2.2, U1.15 (SDA); also elsewhere on the board
GNDREF: C49.2, C50.2, C51.2, IC5.2 (A1), IC5.3 (A2), IC5.12 (VSS), IC5.21 (A0), IC6.2 (A1), IC6.3 (A2), IC6.12 (VSS), TP8.1, U1.1 (A0), U1.3 (A2), U1.8 (VSS); also elsewhere on the board
OR1: J12.1; also elsewhere on the board
OR2: J14.1; also elsewhere on the board
OR3: J13.1; also elsewhere on the board
OR4: J15.1; also elsewhere on the board
VDD: C49.1, C50.1, C51.1, IC5.24 (VDD), IC6.21 (A0), IC6.24 (VDD), R2.1, R3.1, R8.1, R9.1, R16.1, TP5.1, TP7.1, U1.2 (A1), U1.16 (VDD); also elsewhere on the board

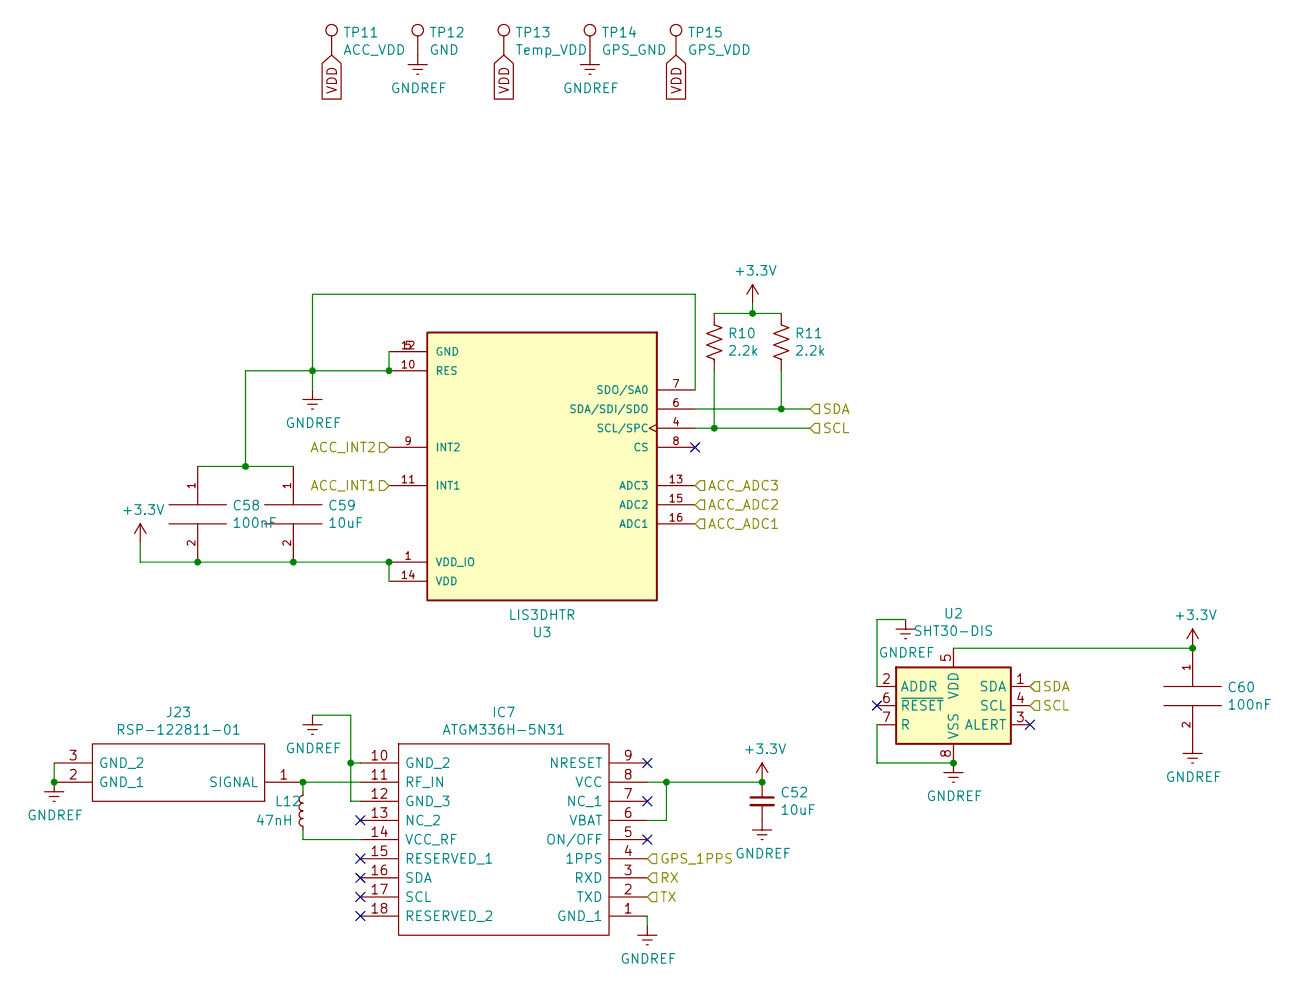
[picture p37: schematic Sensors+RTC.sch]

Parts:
C52, C59: 10uF; C_0805_2012Metric
C58, C60: 100nF; C_0805_2012Metric
IC7: ATGM336H-5N31; ATGM336H5N31; Manufacturer_Part_Number ATGM336H-5N31
J23: RSP-122811-01; RSP12281101; Manufacturer_Part_Number RSP-122811-01; Mouser Part Number 200-RSP-122811-01
L12: 47nH; L_0805_2012Metric
R10, R11: 2.2k; R_0805_2012Metric
TP11: ACC_VDD; TestPoint_Pad_D2.0mm
TP12: GND; TestPoint_Pad_D2.0mm
TP13: Temp_VDD; TestPoint_Pad_D2.0mm
TP14: GPS_GND; TestPoint_Pad_D4.0mm
TP15: GPS_VDD; TestPoint_Pad_D4.0mm
U2: SHT30-DIS; Sensirion_DFN-8-1EP_2.5x2.5mm_P0.5mm_EP1.1x1.7mm
U3: LIS3DHTR; XDCR_LIS3DHTR; PARTREV 2

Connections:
ACC_ADC1: U3.16 (ADC1); also elsewhere on the board
ACC_ADC2: U3.15 (ADC2); also elsewhere on the board
ACC_ADC3: U3.13 (ADC3); also elsewhere on the board
ACC_INT1: U3.11 (INT1); also elsewhere on the board
ACC_INT2: U3.9 (INT2); also elsewhere on the board
GNDREF: C52.2, C58.1, C59.1, C60.2, IC7.1 (GND_1), IC7.10 (GND_2), IC7.12 (GND_3), J23.2 (GND_1), J23.3 (GND_2), TP12.1, TP14.1, U2.2 (ADDR), U2.7 (R), U2.8 (VSS), U2.9 (VSS), U3.5 (GND), U3.7 (SDO/SA0), U3.10 (RES), U3.12 (GND); also elsewhere on the board
GPS_1PPS: IC7.4 (1PPS); also elsewhere on the board
unnamed: IC7.11 (RF_IN), J23.1 (SIGNAL), L12.2
unnamed: IC7.14 (VCC_RF), L12.1
RX: IC7.3 (RXD); also elsewhere on the board
SCL: R10.2, U2.4 (SCL), U3.4 (SCL/SPC); also elsewhere on the board
SDA: R11.2, U2.1 (SDA), U3.6 (SDA/SDI/SDO); also elsewhere on the board
TX: IC7.2 (TXD); also elsewhere on the board
VDD: C52.1, C58.2, C59.2, C60.1, IC7.6 (VBAT), IC7.8 (VCC), R10.1, R11.1, TP11.1, TP13.1, TP15.1, U2.5 (VDD), U3.1 (VDD_IO), U3.14 (VDD); also elsewhere on the board

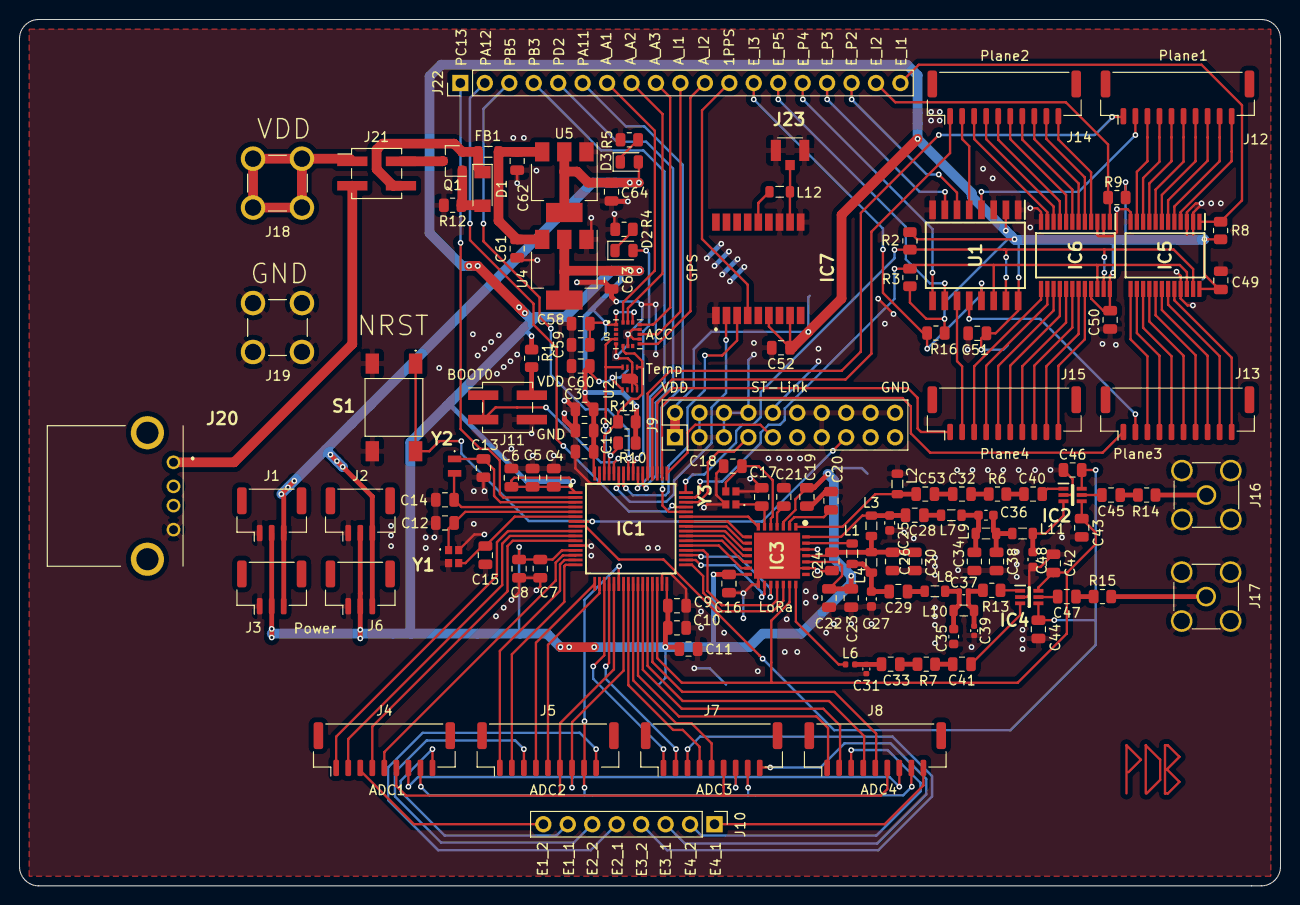
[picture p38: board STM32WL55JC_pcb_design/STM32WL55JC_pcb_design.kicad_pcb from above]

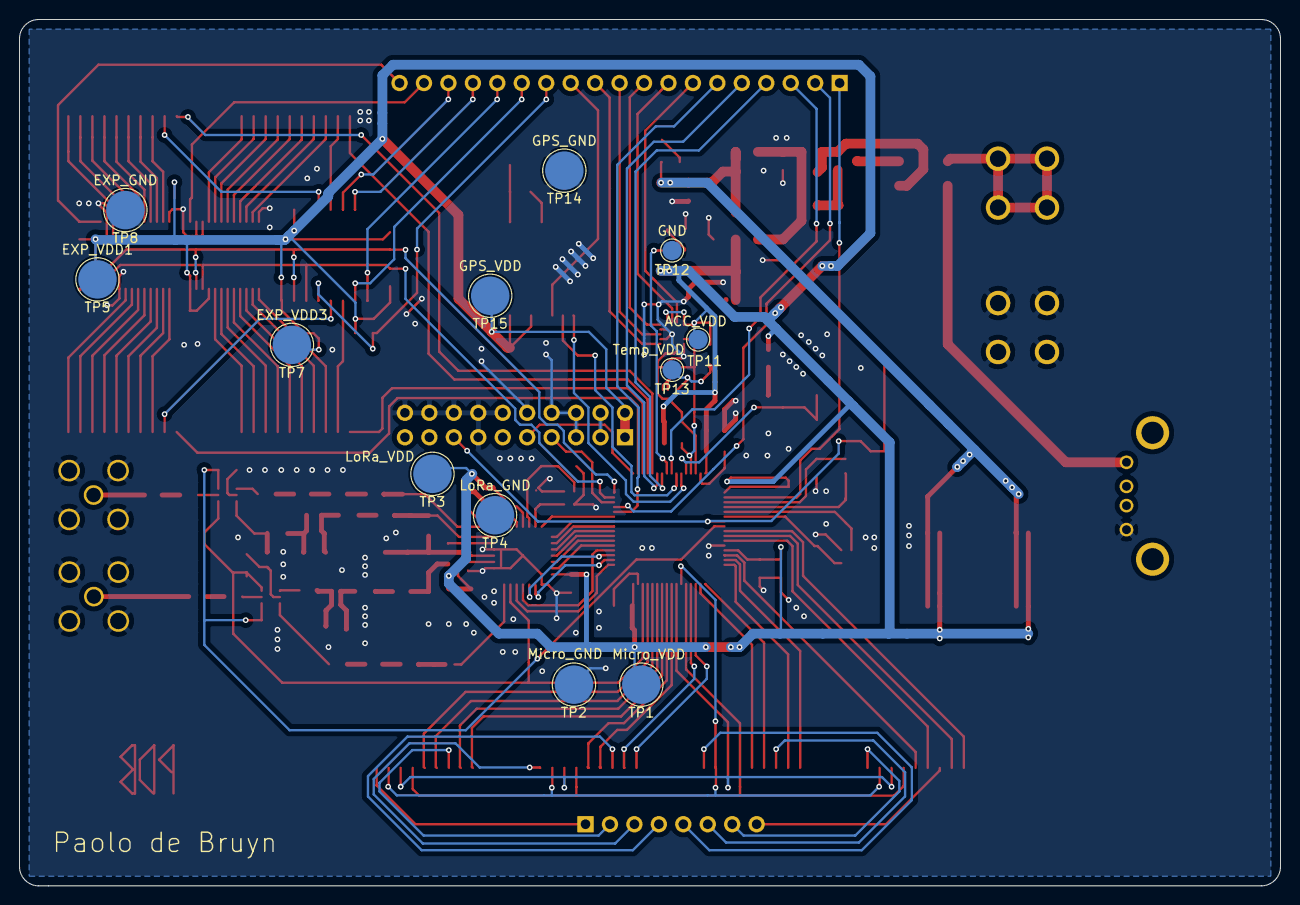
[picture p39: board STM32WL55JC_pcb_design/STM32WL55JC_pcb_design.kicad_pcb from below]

Board: 2 copper layers, 131.0 x 90.0 mm, 143 parts (12 on the bottom side), 160 nets.

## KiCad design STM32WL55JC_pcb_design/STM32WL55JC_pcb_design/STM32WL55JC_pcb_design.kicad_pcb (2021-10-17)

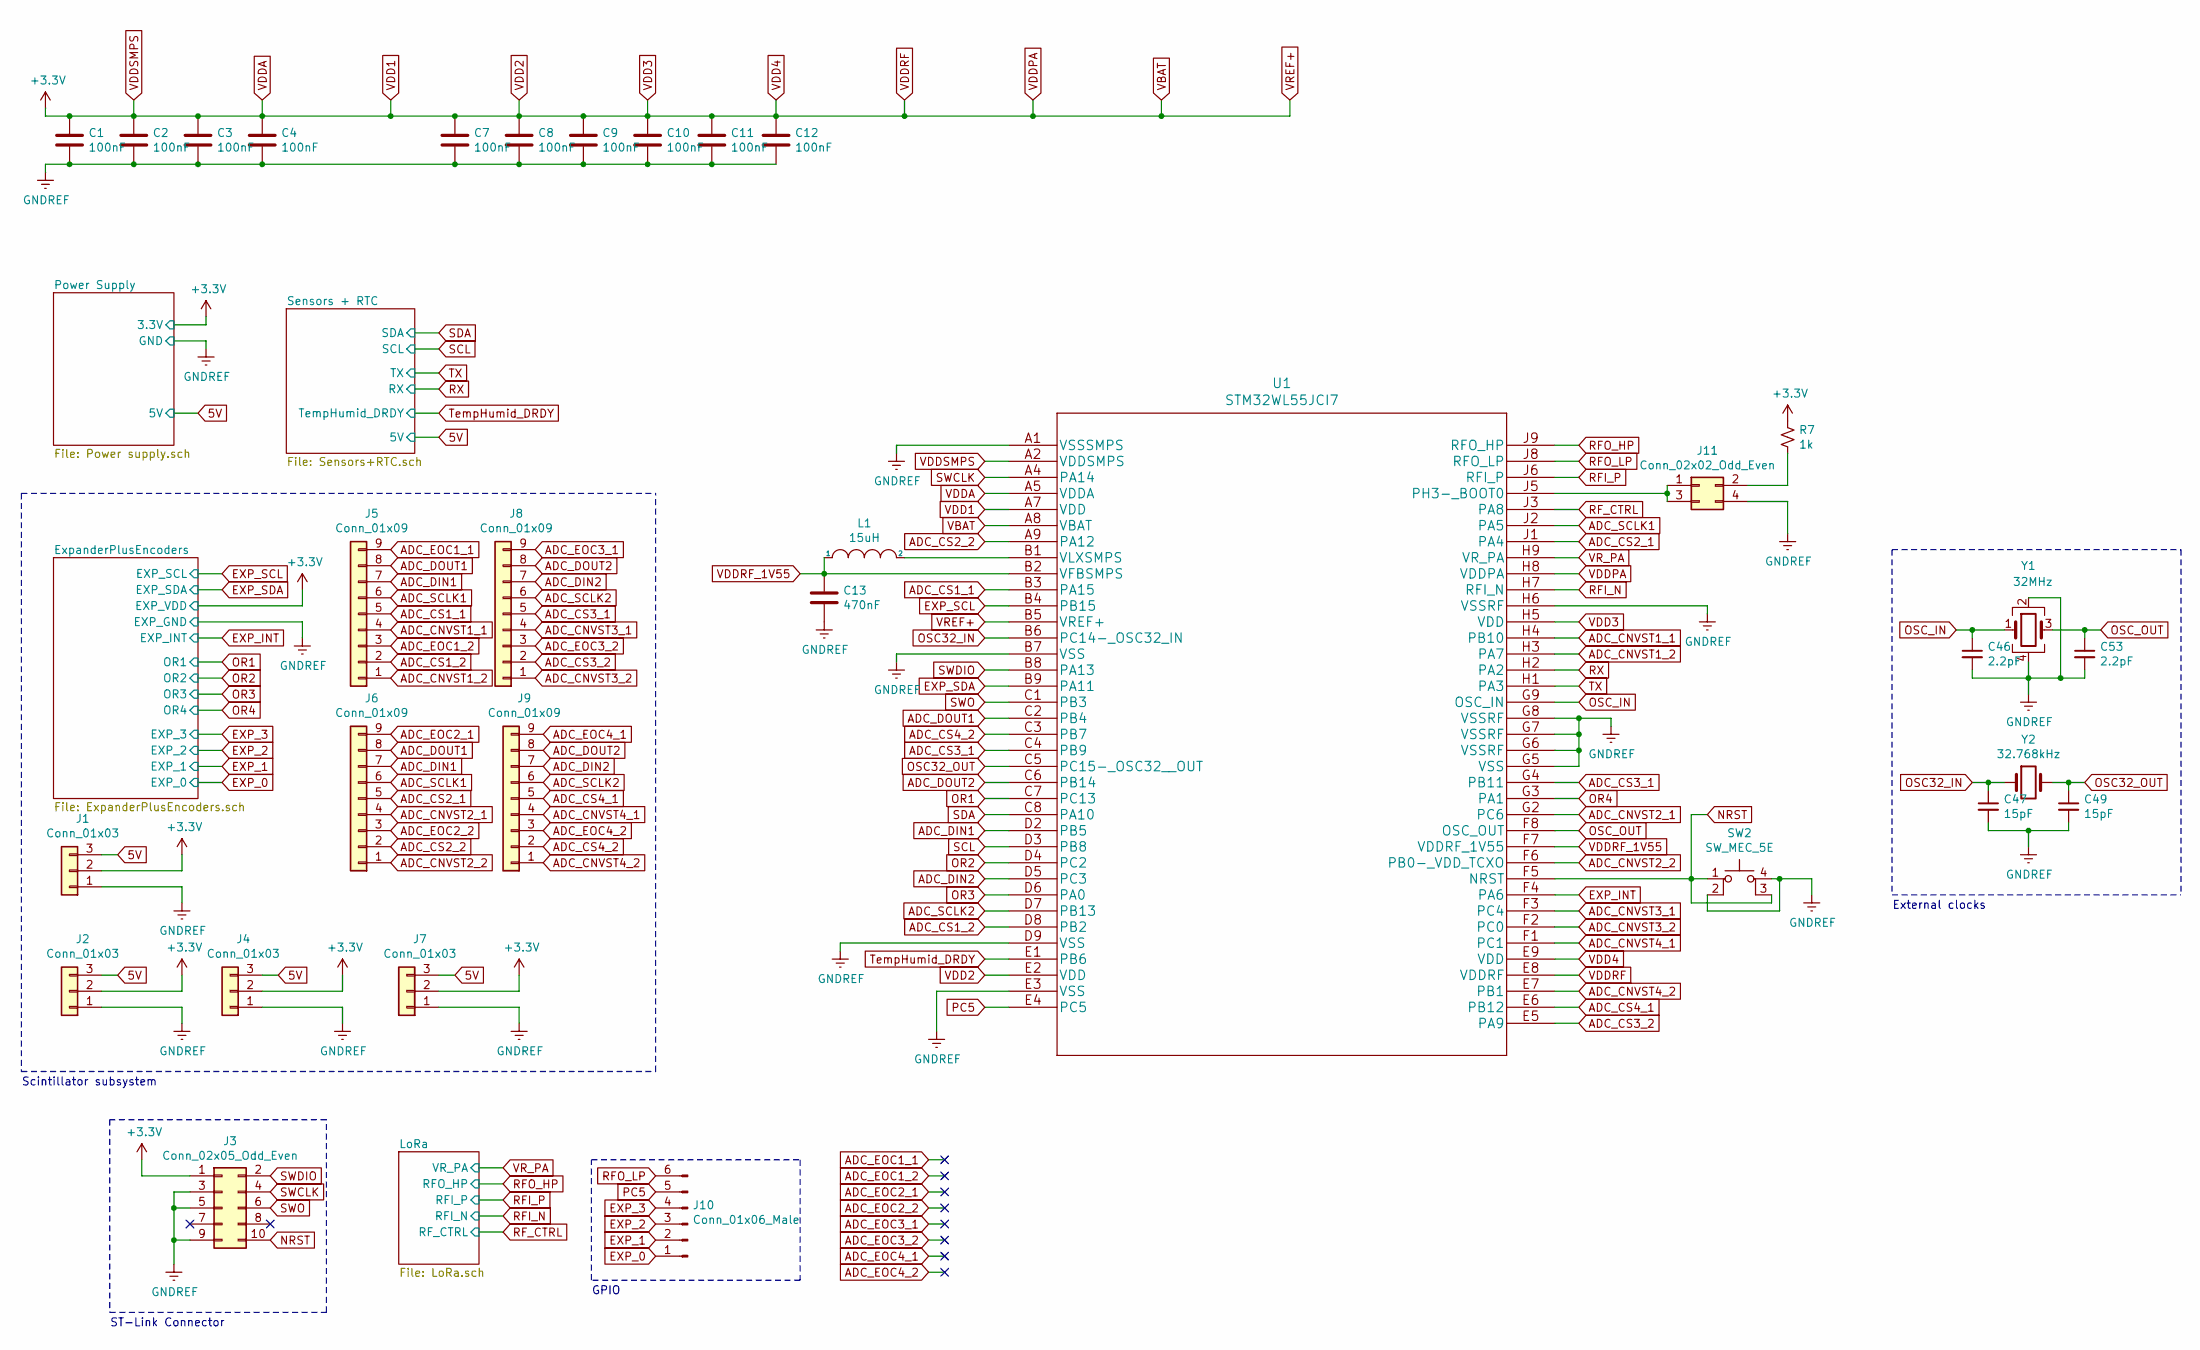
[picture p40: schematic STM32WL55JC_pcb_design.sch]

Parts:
C1, C2, C3, C4, C7, C8, C9, C10, C11, C12: 100nF; C_0805_2012Metric
C13: 470nF; C_0805_2012Metric
C46, C53: 2.2pF; C_0805_2012Metric
C47, C49: 15pF; C_0805_2012Metric
J1, J2, J4, J7: Conn_01x03; JST_GH_BM03B-GHS-TBT_1x03-1MP_P1.25mm_Vertical
J3: Conn_02x05_Odd_Even; PinHeader_2x05_P1.27mm_Vertical_SMD
J5, J6, J8, J9: Conn_01x09; JST_GH_BM09B-GHS-TBT_1x09-1MP_P1.25mm_Vertical
J10: Conn_01x06_Male; PinHeader_1x06_P2.54mm_Vertical
J11: Conn_02x02_Odd_Even; PinHeader_2x02_P2.54mm_Vertical_SMD
L1: 15uH; L_0805_2012Metric
R7: 1k; R_0805_2012Metric
SW2: SW_MEC_5E; EVQP2V02W
U1: STM32WL55JCI7
Y1: 32MHz; Oscillator_SMD_SeikoEpson_SG210-4Pin_2.5x2.0mm
Y2: 32.768kHz; SC20S125PF20PPM

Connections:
5V: J1.3, J2.3, J4.3, J7.3; also elsewhere on the board
ADC_CNVST1_1: J5.4, U1.H4 (PB10)
ADC_CNVST1_2: J5.1, U1.H3 (PA7)
ADC_CNVST2_1: J6.4, U1.G2 (PC6)
ADC_CNVST2_2: J6.1, U1.F6 (PB0-_VDD_TCXO)
ADC_CNVST3_1: J8.4, U1.F3 (PC4)
ADC_CNVST3_2: J8.1, U1.F2 (PC0)
ADC_CNVST4_1: J9.4, U1.F1 (PC1)
ADC_CNVST4_2: J9.1, U1.E7 (PB1)
ADC_CS1_1: J5.5, U1.B3 (PA15)
ADC_CS1_2: J5.2, U1.D8 (PB2)
ADC_CS2_1: J6.5, U1.J1 (PA4)
ADC_CS2_2: J6.2, U1.A9 (PA12)
ADC_CS3_1: J8.5, U1.C4 (PB9), U1.G4 (PB11)
ADC_CS3_2: J8.2, U1.E5 (PA9)
ADC_CS4_1: J9.5, U1.E6 (PB12)
ADC_CS4_2: J9.2, U1.C3 (PB7)
ADC_DIN1: J5.7, J6.7, U1.D2 (PB5)
ADC_DIN2: J8.7, J9.7, U1.D5 (PC3)
ADC_DOUT1: J5.8, J6.8, U1.C2 (PB4)
ADC_DOUT2: J8.8, J9.8, U1.C6 (PB14)
ADC_EOC1_1: J5.9
ADC_EOC1_2: J5.3
ADC_EOC2_1: J6.9
ADC_EOC2_2: J6.3
ADC_EOC3_1: J8.9
ADC_EOC3_2: J8.3
ADC_EOC4_1: J9.9
ADC_EOC4_2: J9.3
ADC_SCLK1: J5.6, J6.6, U1.J2 (PA5)
ADC_SCLK2: J8.6, J9.6, U1.D7 (PB13)
EXP_0: J10.1; also elsewhere on the board
EXP_1: J10.2; also elsewhere on the board
EXP_2: J10.3; also elsewhere on the board
EXP_3: J10.4; also elsewhere on the board
EXP_INT: U1.F4 (PA6); also elsewhere on the board
EXP_SCL: U1.B4 (PB15); also elsewhere on the board
EXP_SDA: U1.B9 (PA11); also elsewhere on the board
GNDREF: C1.2, C2.2, C3.2, C4.2, C7.2, C8.2, C9.2, C10.2, C11.2, C12.2, C13.2, C46.2, C47.2, C49.2, C53.2, J1.1, J2.1, J3.3, J3.5, J3.9, J4.1, J7.1, J11.4, SW2.2, SW2.4 (A), U1.A1 (VSSSMPS), U1.B7 (VSS), U1.D9 (VSS), U1.E3 (VSS), U1.G5 (VSS), U1.G6 (VSSRF), U1.G7 (VSSRF), U1.G8 (VSSRF), U1.H6 (VSSRF), Y1.2, Y1.4; also elsewhere on the board
NRST: J3.10, SW2.1, SW2.3 (K), U1.F5 (NRST)
unnamed: J11.1, J11.3, U1.J5 (PH3-_BOOT0)
unnamed: J11.2, R7.2
unnamed: L1.2, U1.B1 (VLXSMPS)
OR1: U1.C7 (PC13); also elsewhere on the board
OR2: U1.D4 (PC2); also elsewhere on the board
OR3: U1.D6 (PA0); also elsewhere on the board
OR4: U1.G3 (PA1); also elsewhere on the board
OSC32_IN: C47.1, U1.B6 (PC14-_OSC32_IN), Y2.1
OSC32_OUT: C49.1, U1.C5 (PC15-_OSC32__OUT), Y2.2
OSC_IN: C46.1, U1.G9 (OSC_IN), Y1.1
OSC_OUT: C53.1, U1.F8 (OSC_OUT), Y1.3
PC5: J10.5, U1.E4 (PC5)
RFI_N: U1.H7 (RFI_N); also elsewhere on the board
RFI_P: U1.J6 (RFI_P); also elsewhere on the board
RFO_HP: U1.J9 (RFO_HP); also elsewhere on the board
RFO_LP: J10.6, U1.J8 (RFO_LP)
RF_CTRL: U1.J3 (PA8); also elsewhere on the board
RX: U1.H2 (PA2); also elsewhere on the board
SCL: U1.D3 (PB8); also elsewhere on the board
SDA: U1.C8 (PA10); also elsewhere on the board
SWCLK: J3.4, U1.A4 (PA14)
SWDIO: J3.2, U1.B8 (PA13)
SWO: J3.6, U1.C1 (PB3)
TX: U1.H1 (PA3); also elsewhere on the board
TempHumid_DRDY: U1.E1 (PB6); also elsewhere on the board
VBAT: C1.1, C2.1, C3.1, C4.1, C7.1, C8.1, C9.1, C10.1, C11.1, C12.1, J1.2, J2.2, J3.1, J4.2, J7.2, R7.1, U1.A2 (VDDSMPS), U1.A5 (VDDA), U1.A7 (VDD), U1.A8 (VBAT), U1.B5 (VREF+), U1.E2 (VDD), U1.E8 (VDDRF), U1.E9 (VDD), U1.H5 (VDD), U1.H8 (VDDPA); also elsewhere on the board
VDDRF_1V55: C13.1, L1.1, U1.B2 (VFBSMPS), U1.F7 (VDDRF_1V55)
VR_PA: U1.H9 (VR_PA); also elsewhere on the board

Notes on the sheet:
Scintillator subsystem
ST-Link Connector
GPIO
External clocks

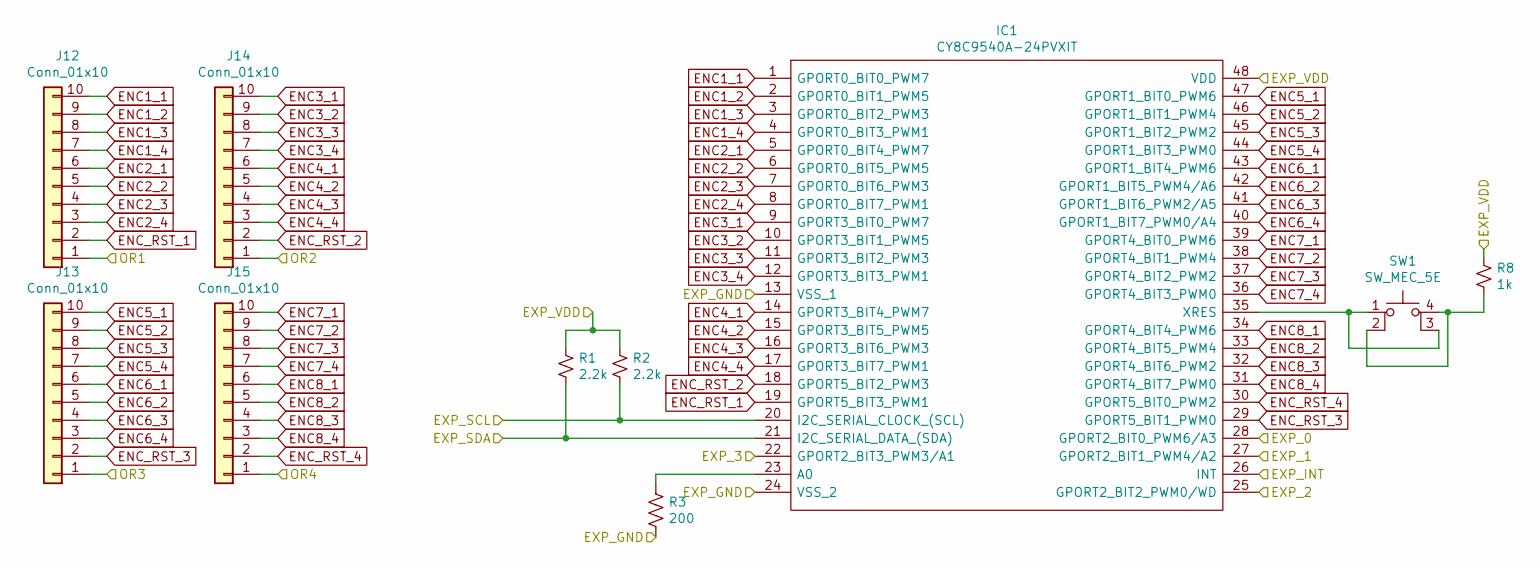
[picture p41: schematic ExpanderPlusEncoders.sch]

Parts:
IC1: CY8C9540A-24PVXIT; SOP64P1035X279-48N; Manufacturer_Part_Number CY8C9540A-24PVXIT; Mouser Part Number 727-CY8C9540A24PVXIT
J12, J13, J14, J15: Conn_01x10; JST_GH_BM10B-GHS-TBT_1x10-1MP_P1.25mm_Vertical
R1, R2: 2.2k; R_0805_2012Metric
R3: 200; R_0805_2012Metric
R8: 1k; R_0805_2012Metric
SW1: SW_MEC_5E; EVQP2V02W

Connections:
ENC1_1: IC1.1 (GPORT0_BIT0_PWM7), J12.10
ENC1_2: IC1.2 (GPORT0_BIT1_PWM5), J12.9
ENC1_3: IC1.3 (GPORT0_BIT2_PWM3), J12.8
ENC1_4: IC1.4 (GPORT0_BIT3_PWM1), J12.7
ENC2_1: IC1.5 (GPORT0_BIT4_PWM7), J12.6
ENC2_2: IC1.6 (GPORT0_BIT5_PWM5), J12.5
ENC2_3: IC1.7 (GPORT0_BIT6_PWM3), J12.4
ENC2_4: IC1.8 (GPORT0_BIT7_PWM1), J12.3
ENC3_1: IC1.9 (GPORT3_BIT0_PWM7), J14.10
ENC3_2: IC1.10 (GPORT3_BIT1_PWM5), J14.9
ENC3_3: IC1.11 (GPORT3_BIT2_PWM3), J14.8
ENC3_4: IC1.12 (GPORT3_BIT3_PWM1), J14.7
ENC4_1: IC1.14 (GPORT3_BIT4_PWM7), J14.6
ENC4_2: IC1.15 (GPORT3_BIT5_PWM5), J14.5
ENC4_3: IC1.16 (GPORT3_BIT6_PWM3), J14.4
ENC4_4: IC1.17 (GPORT3_BIT7_PWM1), J14.3
ENC5_1: IC1.47 (GPORT1_BIT0_PWM6), J13.10
ENC5_2: IC1.46 (GPORT1_BIT1_PWM4), J13.9
ENC5_3: IC1.45 (GPORT1_BIT2_PWM2), J13.8
ENC5_4: IC1.44 (GPORT1_BIT3_PWM0), J13.7
ENC6_1: IC1.43 (GPORT1_BIT4_PWM6), J13.6
ENC6_2: IC1.42 (GPORT1_BIT5_PWM4/A6), J13.5
ENC6_3: IC1.41 (GPORT1_BIT6_PWM2/A5), J13.4
ENC6_4: IC1.40 (GPORT1_BIT7_PWM0/A4), J13.3
ENC7_1: IC1.39 (GPORT4_BIT0_PWM6), J15.10
ENC7_2: IC1.38 (GPORT4_BIT1_PWM4), J15.9
ENC7_3: IC1.37 (GPORT4_BIT2_PWM2), J15.8
ENC7_4: IC1.36 (GPORT4_BIT3_PWM0), J15.7
ENC8_1: IC1.34 (GPORT4_BIT4_PWM6), J15.6
ENC8_2: IC1.33 (GPORT4_BIT5_PWM4), J15.5
ENC8_3: IC1.32 (GPORT4_BIT6_PWM2), J15.4
ENC8_4: IC1.31 (GPORT4_BIT7_PWM0), J15.3
ENC_RST_1: IC1.19 (GPORT5_BIT3_PWM1), J12.2
ENC_RST_2: IC1.18 (GPORT5_BIT2_PWM3), J14.2
ENC_RST_3: IC1.29 (GPORT5_BIT1_PWM0), J13.2
ENC_RST_4: IC1.30 (GPORT5_BIT0_PWM2), J15.2
EXP_0: IC1.28 (GPORT2_BIT0_PWM6/A3); also elsewhere on the board
EXP_1: IC1.27 (GPORT2_BIT1_PWM4/A2); also elsewhere on the board
EXP_2: IC1.25 (GPORT2_BIT2_PWM0/WD); also elsewhere on the board
EXP_3: IC1.22 (GPORT2_BIT3_PWM3/A1); also elsewhere on the board
EXP_INT: IC1.26 (INT); also elsewhere on the board
EXP_SCL: IC1.20 (I2C_SERIAL_CLOCK_(SCL)), R2.2; also elsewhere on the board
EXP_SDA: IC1.21 (I2C_SERIAL_DATA_(SDA)), R1.2; also elsewhere on the board
GNDREF: IC1.13 (VSS_1), IC1.24 (VSS_2), R3.2; also elsewhere on the board
unnamed: IC1.23 (A0), R3.1
unnamed: IC1.35 (XRES), SW1.1, SW1.3 (K)
unnamed: R8.2, SW1.2, SW1.4 (A)
OR1: J12.1; also elsewhere on the board
OR2: J14.1; also elsewhere on the board
OR3: J13.1; also elsewhere on the board
OR4: J15.1; also elsewhere on the board
VBAT: IC1.48 (VDD), R1.1, R2.1, R8.1; also elsewhere on the board

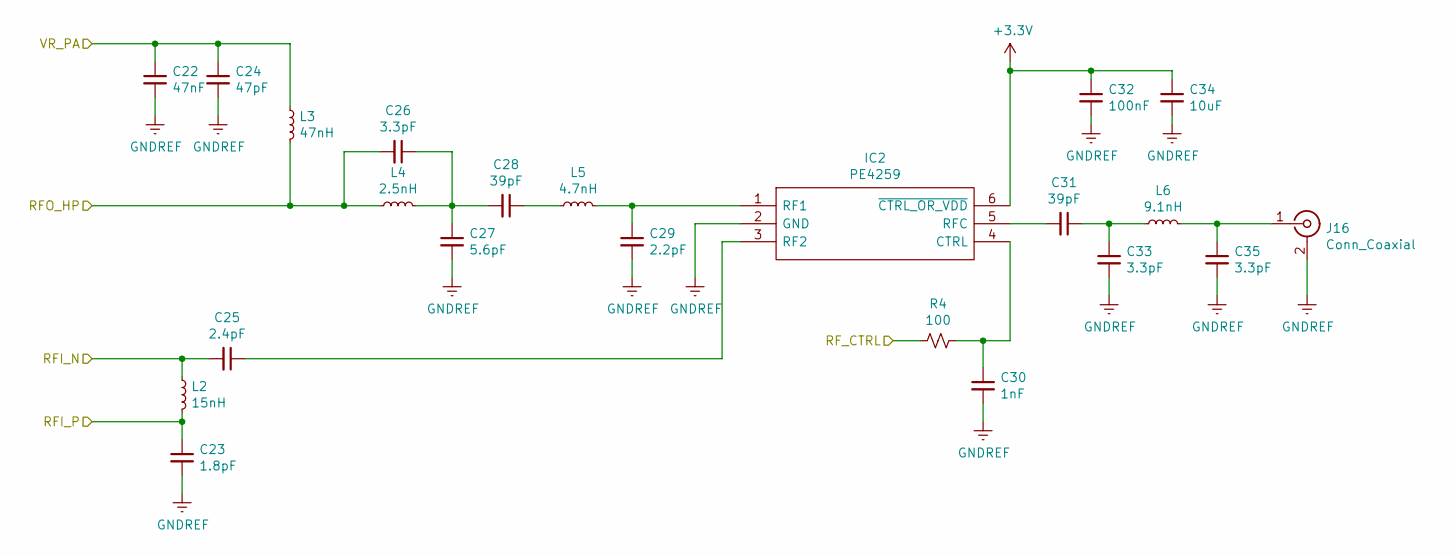
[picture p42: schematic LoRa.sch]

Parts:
C22: 47nF; C_0805_2012Metric
C23: 1.8pF; C_0805_2012Metric
C24: 47pF; C_0805_2012Metric
C25: 2.4pF; C_0603_1608Metric
C26, C33, C35: 3.3pF; C_0805_2012Metric
C27: 5.6pF; C_0805_2012Metric
C28, C31: 39pF; C_0805_2012Metric
C29: 2.2pF; C_0402_1005Metric
C30: 1nF; C_0805_2012Metric
C32: 100nF; C_0805_2012Metric
C34: 10uF; C_0805_2012Metric
IC2: PE4259; SOT65P210X110-6N; Manufacturer_Part_Number PE4259
J16: Conn_Coaxial; SMA_Amphenol_901-144_Vertical
L2: 15nH; L_01005_0402Metric
L3: 47nH; L_0805_2012Metric
L4: 2.5nH; L_0402_1005Metric
L5: 4.7nH; L_0805_2012Metric
L6: 9.1nH; L_0402_1005Metric
R4: 100; R_0805_2012Metric

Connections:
GNDREF: C22.2, C23.2, C24.2, C27.2, C29.2, C30.2, C32.2, C33.2, C34.2, C35.2, IC2.2 (GND), J16.2 (Ext); also elsewhere on the board
unnamed: C25.1, IC2.3 (RF2)
unnamed: C26.1, C27.1, C28.2, L4.2
unnamed: C28.1, L5.1
unnamed: C29.1, IC2.1 (RF1), L5.2
unnamed: C30.1, IC2.4 (CTRL), R4.2
unnamed: C31.1, C33.1, L6.1
unnamed: C31.2, IC2.5 (RFC)
unnamed: C35.1, J16.1 (In), L6.2
RFI_N: C25.2, L2.1; also elsewhere on the board
RFI_P: C23.1, L2.2; also elsewhere on the board
RFO_HP: C26.2, L3.2, L4.1; also elsewhere on the board
RF_CTRL: R4.1; also elsewhere on the board
VBAT: C32.1, C34.1, IC2.6 (~CTRL_OR_VDD); also elsewhere on the board
VR_PA: C22.1, C24.1, L3.1; also elsewhere on the board

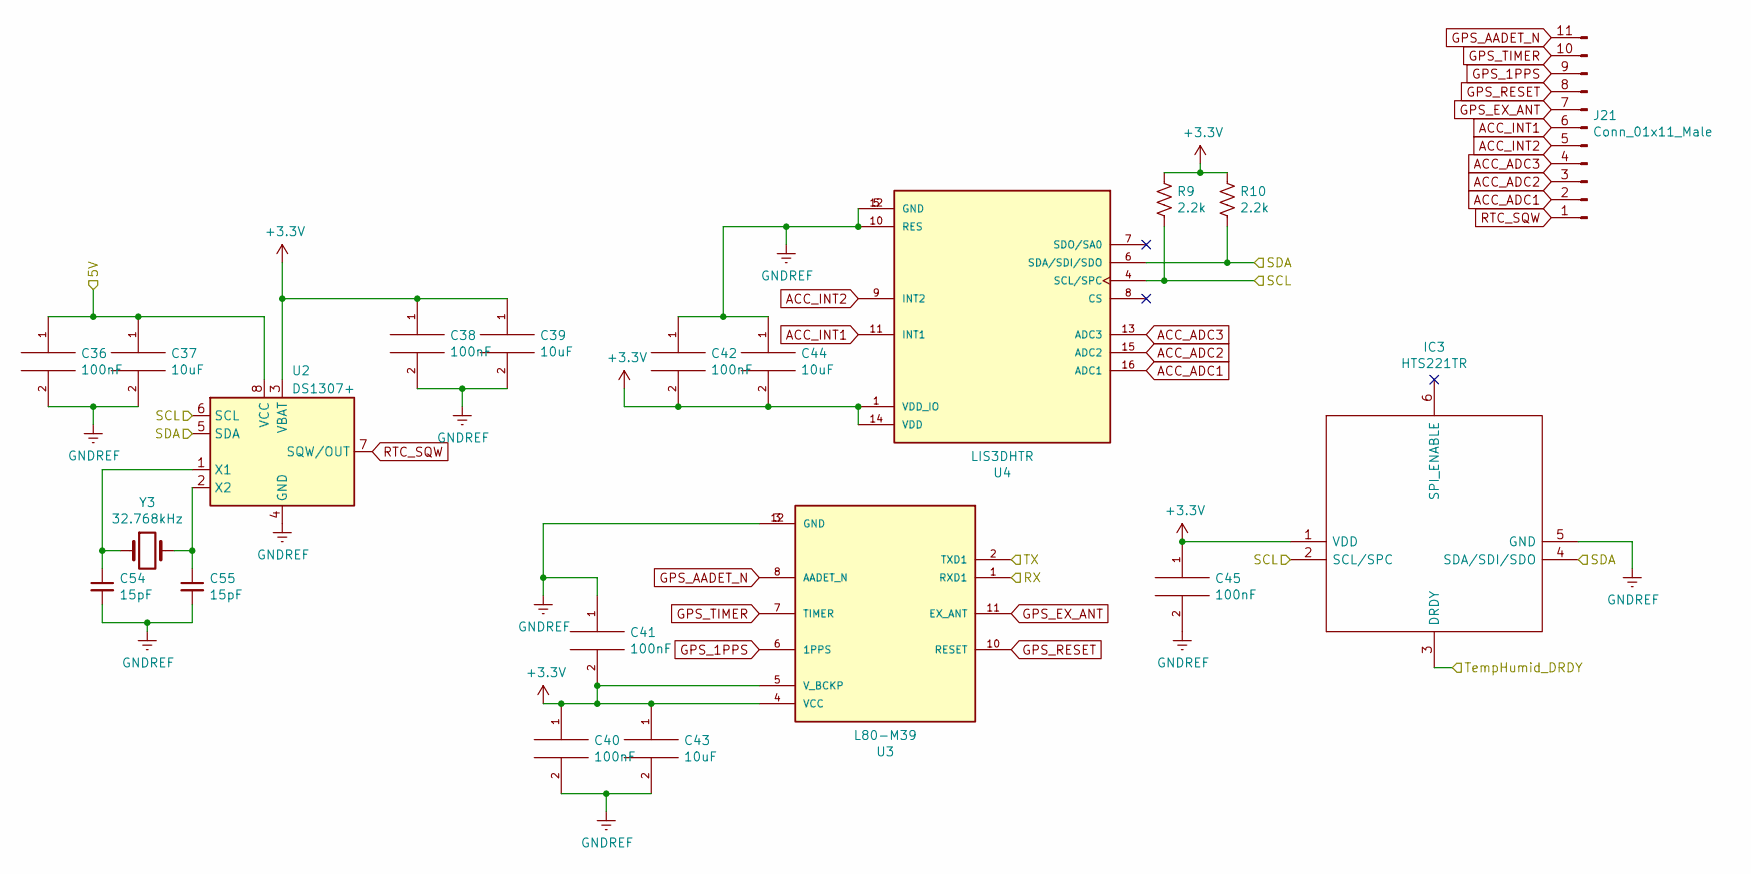
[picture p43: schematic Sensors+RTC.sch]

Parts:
C36, C38, C40, C41, C42, C45: 100nF; C_0805_2012Metric
C37, C39, C43, C44: 10uF; C_0805_2012Metric
C54, C55: 15pF; C_0805_2012Metric
IC3: HTS221TR; Manufacturer_Part_Number HTS221TR; Mouser Part Number 511-HTS221TR
J21: Conn_01x11_Male; PinHeader_1x11_P2.54mm_Vertical
R9, R10: 2.2k; R_0805_2012Metric
U2: DS1307+; DIP-8_W7.62mm
U3: L80-M39; XCVR_L80-M39
U4: LIS3DHTR; XDCR_LIS3DHTR; PARTREV 2
Y3: 32.768kHz; SC20S125PF20PPM

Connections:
5V: C36.1, C37.1, U2.8 (VCC); also elsewhere on the board
ACC_ADC1: J21.2, U4.16 (ADC1)
ACC_ADC2: J21.3, U4.15 (ADC2)
ACC_ADC3: J21.4, U4.13 (ADC3)
ACC_INT1: J21.6, U4.11 (INT1)
ACC_INT2: J21.5, U4.9 (INT2)
GNDREF: C36.2, C37.2, C38.2, C39.2, C40.2, C41.1, C42.1, C43.2, C44.1, C45.2, C54.2, C55.2, IC3.5 (GND), U2.4 (GND), U3.3 (GND), U3.12 (GND), U4.5 (GND), U4.10 (RES), U4.12 (GND); also elsewhere on the board
GPS_1PPS: J21.9, U3.6 (1PPS)
GPS_AADET_N: J21.11, U3.8 (AADET_N)
GPS_EX_ANT: J21.7, U3.11 (EX_ANT)
GPS_RESET: J21.8, U3.10 (RESET)
GPS_TIMER: J21.10, U3.7 (TIMER)
unnamed: C54.1, U2.1 (X1), Y3.1
unnamed: C55.1, U2.2 (X2), Y3.2
RTC_SQW: J21.1, U2.7 (SQW/OUT)
RX: U3.1 (RXD1); also elsewhere on the board
SCL: IC3.2 (SCL/SPC), R9.2, U2.6 (SCL), U4.4 (SCL/SPC); also elsewhere on the board
SDA: IC3.4 (SDA/SDI/SDO), R10.2, U2.5 (SDA), U4.6 (SDA/SDI/SDO); also elsewhere on the board
TX: U3.2 (TXD1); also elsewhere on the board
TempHumid_DRDY: IC3.3 (DRDY); also elsewhere on the board
VBAT: C38.1, C39.1, C40.1, C41.2, C42.2, C43.1, C44.2, C45.1, IC3.1 (VDD), R9.1, R10.1, U2.3 (VBAT), U3.4 (VCC), U3.5 (V_BCKP), U4.1 (VDD_IO), U4.14 (VDD); also elsewhere on the board

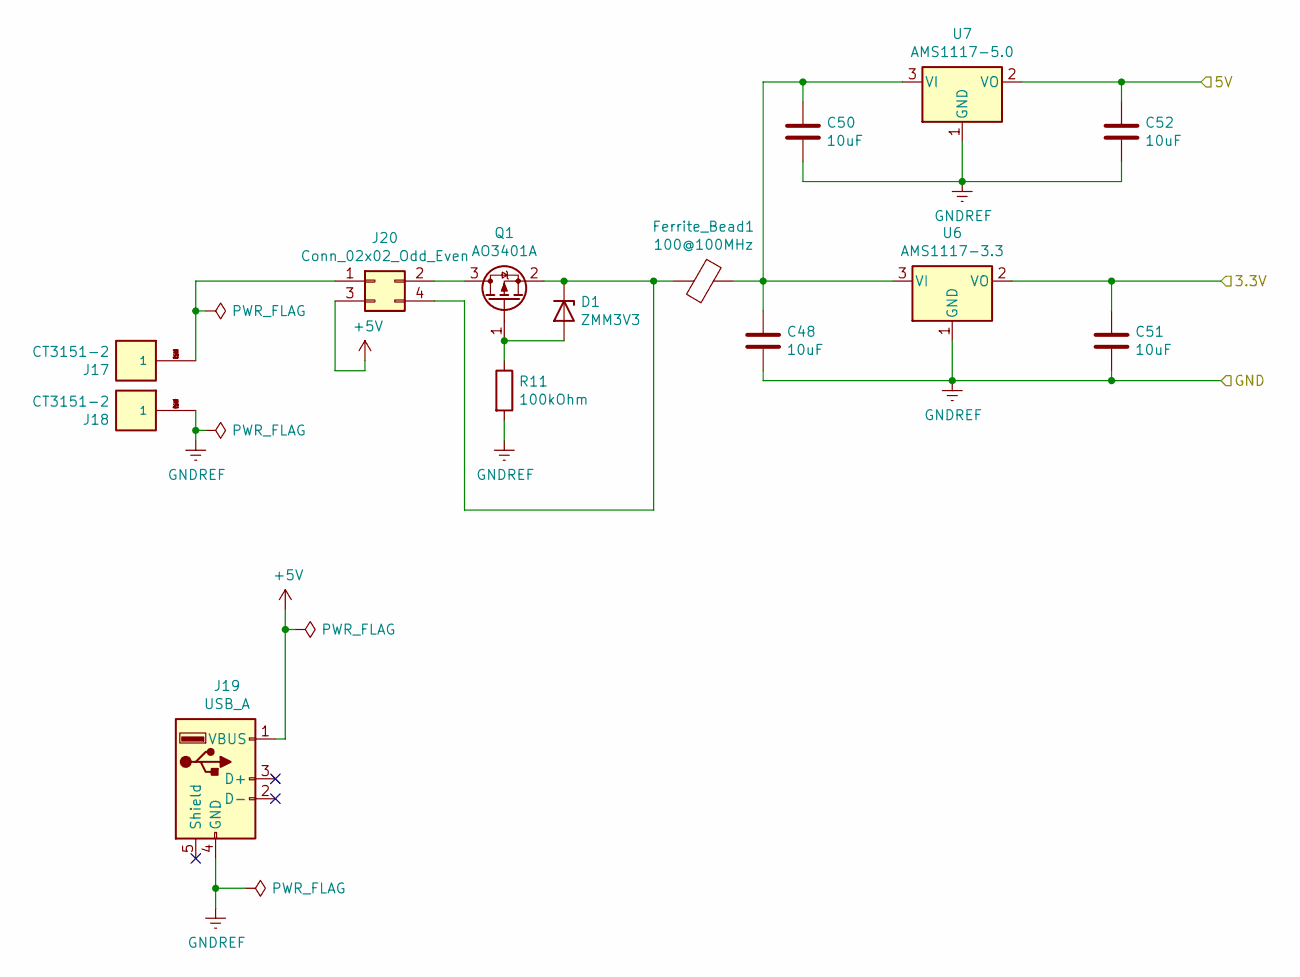
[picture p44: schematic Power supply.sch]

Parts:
C48, C50, C51, C52: 10uF; C_0805_2012Metric
D1: ZMM3V3; D_MiniMELF
Ferrite_Bead1: 100@100MHz; L_0805_2012Metric
J17, J18: CT3151-2; CALTEST_CT3151-2; PARTREV H
J19: USB_A; USBASFBTH
J20: Conn_02x02_Odd_Even; PinHeader_2x02_P2.54mm_Vertical_SMD
Q1: AO3401A; SOT-23
R11: 100kOhm; R_0805_2012Metric
U6: AMS1117-3.3; SOT-223-3_TabPin2
U7: AMS1117-5.0; SOT-223-3_TabPin2

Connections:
5V: C52.1, U7.2 (VO); also elsewhere on the board
+5V: J19.1 (VBUS), J20.3
GNDREF: C48.2, C50.2, C51.2, C52.2, J18.1, J18.2, J18.3, J18.4, J19.4 (GND), R11.2, U6.1 (GND), U7.1 (GND); also elsewhere on the board
unnamed: C48.1, C50.1, Ferrite_Bead1.1, U6.3 (VI), U7.3 (VI)
unnamed: D1.1 (K), Ferrite_Bead1.2, J20.4, Q1.2 (S)
unnamed: D1.2 (A), Q1.1 (G), R11.1
unnamed: J17.1, J17.2, J17.3, J17.4, J20.1
unnamed: J20.2, Q1.3 (D)
VBAT: C51.1, U6.2 (VO); also elsewhere on the board



Board: 4 copper layers, 98 parts (2 on the bottom side), 126 nets.

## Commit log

2021-09-01 First commit of PCB design
    [ADC122S021CIMM.step, B3B-XH-A_LF__SN_.step, CT3151-2.step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]
2021-09-03 First pcb commit
    [GPS_ACC.sch, Power supply.sch, STM32WL55JC_pcb_design.sch]
2021-09-07 Complete first version - todo: rf pins
    [ADC08831IM.step, ExpanderPlusEncoders.sch, GPS_ACC.sch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]
2021-09-14 Add temperature and humidty sensor, add rf connections
    [ExpanderPlusEncoders.sch, GPS_ACC.sch, LoRa.sch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]
2021-09-14 Add missing cap on LoRa.sch
    [LoRa.sch]
2021-09-14 Add RTC
    [STM32WL55JC_pcb_design.sch, Sensors+RTC.sch]
2021-09-29 Finish RF matching network
    [ExpanderPlusEncoders.sch, LoRa.sch, Power supply.sch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]
2021-09-30 Update ADC section to work with MAX11635
    [ExpanderPlusEncoders.sch, L80-M39.step, LIS3DHTR.step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]
2021-09-30 Finish component selection and footprint assignment
    [ExpanderPlusEncoders.sch, LoRa.sch, MAX11635.sch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]
2021-10-05 Initial pcb layout
    [ExpanderPlusEncoders.sch, LoRa.sch, Power supply.sch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]
2021-10-06 Finished component placement
    [ExpanderPlusEncoders.sch, STM32WL55JC_pcb_design.kicad_pcb, STM32WL55JC_pcb_design.sch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]
2021-10-06 Only micro left to be routed
    [STM32WL55JC_pcb_design.kicad_pcb, STM32WL55JC_pcb_design.sch, Sensors+RTC.sch]
2021-10-07 Add some microcontroller routing
    [STM32WL55JC_pcb_design.kicad_pcb]
2021-10-17 Finish new design schematic
    [ADC08831IM.step, ADC122S021CIMM.step, B3B-XH-A_LF__SN_.step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]
2021-10-18 Initial pcb layout and routing
    [LoRa.sch, Power supply.sch, STM32WL55JC_pcb_design.kicad_pcb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]
2021-10-19 Finish pcb routing
    [ExpanderPlusEncoders.sch, Power supply.sch, STM32WL55JC_pcb_design.kicad_pcb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]
2021-10-22 Remove acid traps, make vias the same size, and improve wire spacing
    [STM32WL55JC_pcb_design.kicad_pcb]
2021-10-26 Change devices to available ones from JLC
    [ExpanderPlusEncoders.sch, LoRa.sch, Power supply.sch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]
2021-10-26 Add copper fill and edge cuts
    [STM32WL55JC_pcb_design.kicad_pcb]
2021-10-27 Finish routing
    [STM32WL55JC_pcb_design.kicad_pcb]
2021-10-27 Finish silk screen
    [ExpanderPlusEncoders.sch, LoRa.sch, STM32WL55JC_pcb_design.kicad_pcb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]
2021-11-07 Final push
    [LoRa.sch, Power supply.sch, STM32WL55JC_pcb_design.kicad_pcb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]
2021-11-07 Correct copper fill
    [STM32WL55JC_pcb_design.kicad_pcb]

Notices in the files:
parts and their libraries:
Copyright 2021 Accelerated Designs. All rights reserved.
